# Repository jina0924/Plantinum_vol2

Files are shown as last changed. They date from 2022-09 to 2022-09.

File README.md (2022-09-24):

# 🍀PLANTINUM

<div align="center">
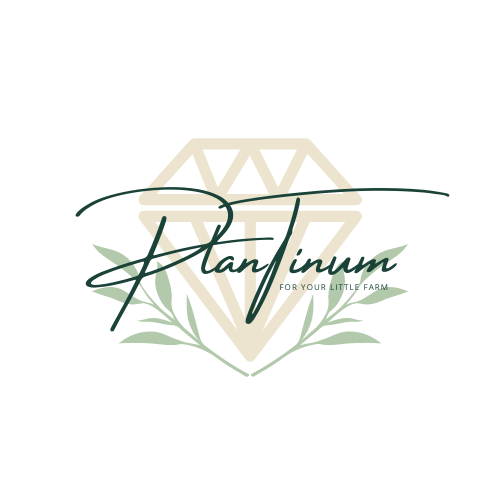
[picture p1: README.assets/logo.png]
  
</div>

**PLANTinum** 이란 **Plant**와 **Platinum**의 합성어입니다. 또한, **Plan**이라는 단어를 담고 계획적으로 식물을 관리하고 보살핀다는 의미를 나타냅니다. 본 프로젝트는 반려식물을 자동으로 케어해주고 나아가 웹을 통하여 반려식물을 거래할 수 있는  **IoT-플랫폼 서비스**를 제공합니다.
Plantinum은 크게 두 가지 서비스로 이루어져 있습니다.

## 1. IoT
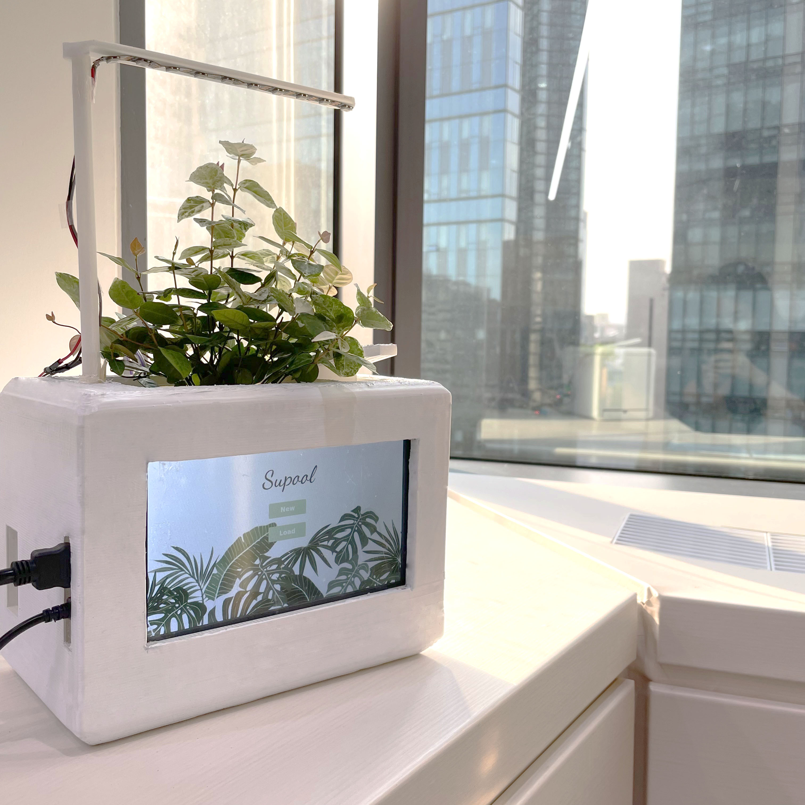
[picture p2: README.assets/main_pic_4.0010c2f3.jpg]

플랜티넘의 IoT 기기 Supool수풀입니다.
Supool의 이름은 **나무와 식물이 우거진 곳**이라는 뜻의 수풀에서 유래했습니다.

### 기능

> 실시간으로 흙의 습도를 측정
> 
> 자동 급수를 진행
>
> LED 식물등
> 
> LCD 터치스크린을 통한 모니터링
> 
> Plantinum, mySQL 웹과 연동

### IoT 기기 구성

<details>
<summary > <b>기능 자세히 보기</b></summary>
<div markdown="1">

[Plantinum 디바이스 시연 영상](https://youtu.be/C1uGjrZCowk)

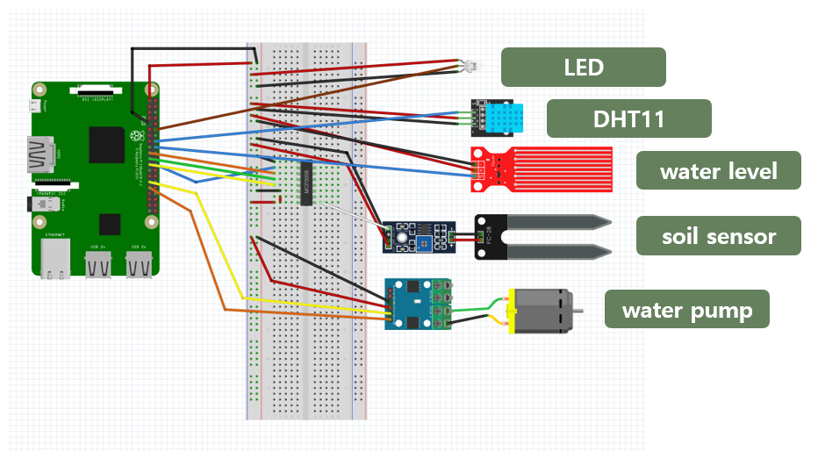
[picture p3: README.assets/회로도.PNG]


> 사용 센서 : LCD, 모터 드라이브(L9110S), 워터펌프, DHT11, 네오픽셀 LED, 수위센서(접촉식), 토양수분센서, mcp3008(컨버터)
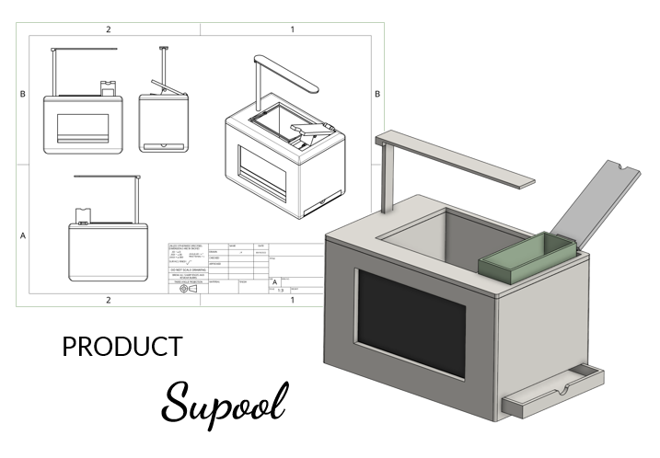
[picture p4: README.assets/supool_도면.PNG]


> supool 3D 도면

</div>
</details>

### LCD 화면 구성

<details>
<summary > <b>기능 자세히 보기</b></summary>
<div markdown="1">

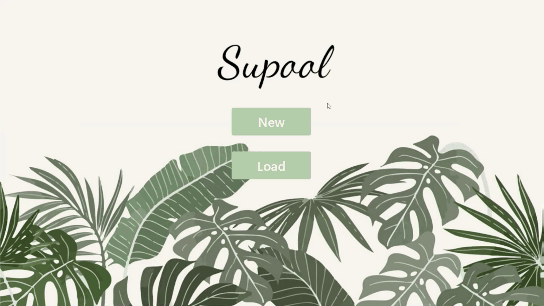
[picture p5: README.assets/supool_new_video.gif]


> new 버튼 클릭 시 OTP 입력으로 WEB과 연동
> 
> OTP는 웹의 내식물 상세 페이지에서 확인 가능 (Supool 연동)
  
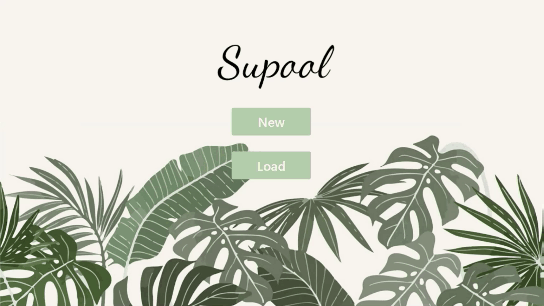
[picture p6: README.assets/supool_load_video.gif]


> load 버튼 클릭 시 supool에 저장되어 있는 정보 불러오기

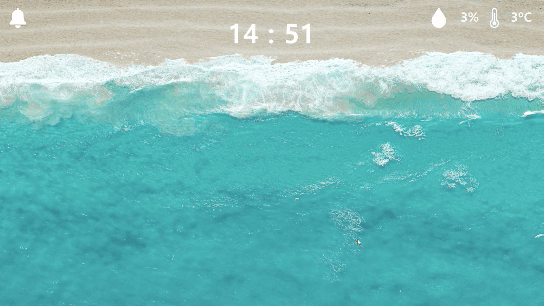
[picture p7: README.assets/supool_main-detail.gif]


> 메인 페이지에서 파도의 높이로 토양 습도 확인
> 
> 디테일 페이지에서 주변환경의 온습도, 토양 수분, 최근 관수 시간, 물통 잔여량 확인

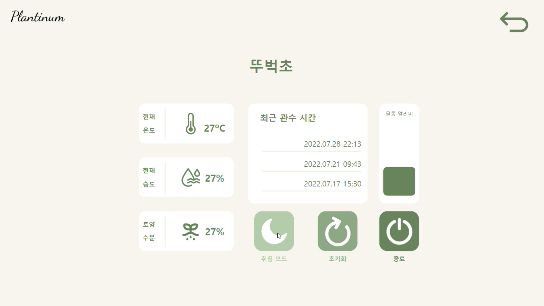
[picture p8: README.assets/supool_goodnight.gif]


> 절전모드 버튼 클릭 후 5초 뒤 절전모드
> 
> 화면 터치 시 메인페이지로 이동

</div>
</details>

<br>

[상세 코드](https://github.com/jina0924/Plantinum_vol2/tree/master/HW/Supool) /
[실행법](https://github.com/jina0924/Plantinum_vol2/blob/master/exec/%EA%B3%B5%ED%86%B5PJT_%EC%84%9C%EC%9A%B81%EB%B0%98_A109_%ED%8F%AC%ED%8C%85%EB%A7%A4%EB%89%B4%EC%96%BC.pdf) /
[기술 스택](https://github.com/jina0924/Plantinum_vol2/blob/master/Docs/STACK_EXPLANATION.md)

## 2. WEB

웹은 크게 세 가지 서비스를 제공합니다.

### 회원가입 및 프로필

<details>
<summary > <b>기능 자세히 보기</b></summary>
<div markdown="1">



> 회원 가입
>
> 최초 회원가 입시 닉네임 자동 생성



> 닉네임, 이메일, 연락처, 주소, 프로필 이미지 변경
>
> 회원가입 후 경과일 확인
>
> 작성한 판매, 구매 게시글 확인
>
> 회원 탈퇴



> 비밀번호 변경

</div>
</details>

<br>

### 내 식물

<details>
<summary > <b>기능 자세히 보기</b></summary>
<div markdown="1">

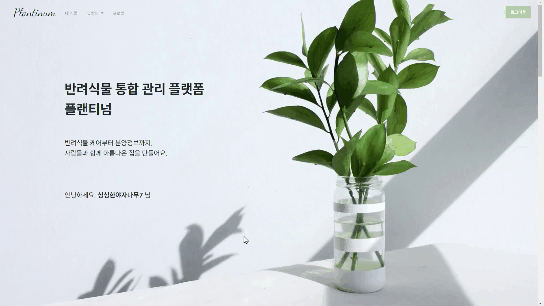
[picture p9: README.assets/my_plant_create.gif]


> 식물 리스트로부터 식물 선택
>
> 존재하지 않는 식물은 사용자가 직접 작성
>
> 반려 식물의 닉네임 지정

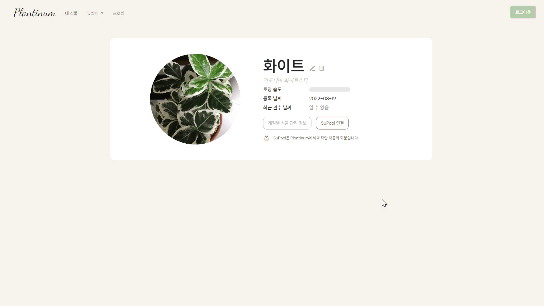
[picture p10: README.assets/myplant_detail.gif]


> 계절별 관리 정보와 특별 관리 정보 제공
>
> SuPool 연결 버튼을 통해 60초 동안 임시 비밀번호 발급, IoT 기기와 웹페이지 연결
>
> 연결 후 웹페이지에서 토양습도와 최근 관수 날짜확인 가능

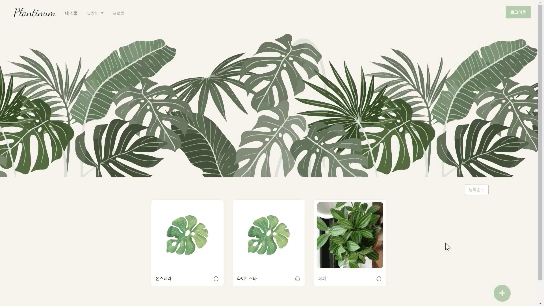
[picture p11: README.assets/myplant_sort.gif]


> 등록순, 이름순 조회
</div>
</details>

<br>

### 잎팔이

<details>
<summary > <b>기능 자세히 보기</b></summary>
<div markdown="1">

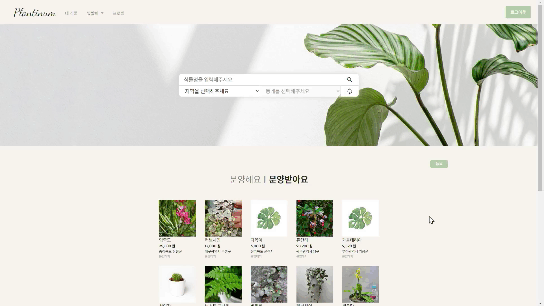
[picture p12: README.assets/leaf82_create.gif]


> 판매, 구매 게시글 등록 및 조회

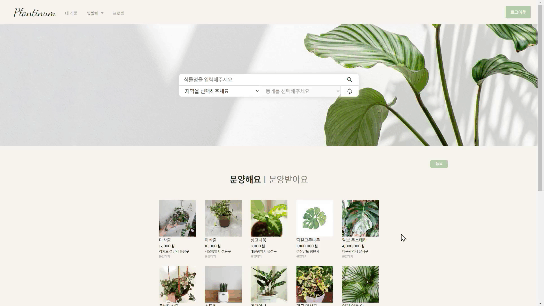
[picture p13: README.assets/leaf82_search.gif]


> 식물명, 지역별 게시글 검색
>
> 게시글은 20개씩 추가 조회

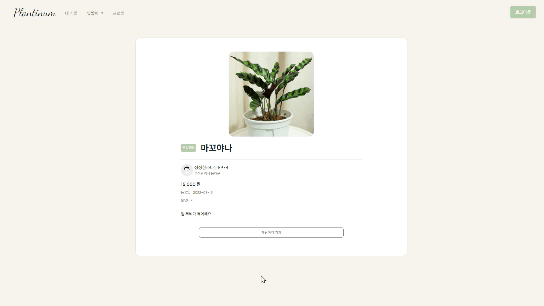
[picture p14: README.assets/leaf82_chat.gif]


> 거래자 간 채팅
</div>
</details>

<br>
<br>
<br>

<details>

<summary > 상세 코드는 여기로 </summary>
<div markdown="1">

### (1) BE

[상세 코드](https://github.com/jina0924/Plantinum_vol2/tree/master/BE) /
[실행법](https://github.com/jina0924/Plantinum_vol2/blob/master/exec/%EA%B3%B5%ED%86%B5PJT_%EC%84%9C%EC%9A%B81%EB%B0%98_A109_%ED%8F%AC%ED%8C%85%EB%A7%A4%EB%89%B4%EC%96%BC.pdf) /
[기술 스택](https://github.com/jina0924/Plantinum_vol2/blob/master/Docs/STACK_EXPLANATION.md)

### (2) FE
[상세 코드](https://github.com/jina0924/Plantinum_vol2/tree/master/FE/plantinum) /
[실행법](https://github.com/jina0924/Plantinum_vol2/blob/master/exec/%EA%B3%B5%ED%86%B5PJT_%EC%84%9C%EC%9A%B81%EB%B0%98_A109_%ED%8F%AC%ED%8C%85%EB%A7%A4%EB%89%B4%EC%96%BC.pdf) /
[기술 스택](https://github.com/jina0924/Plantinum_vol2/blob/master/Docs/STACK_EXPLANATION.md)

</div>
</details>

---

## 💾설치

사이트 주소 : [Plantinum](http://plantinum.co.kr)

> 자세한 내용은 [포팅 매뉴얼](./exec) 참고

- FE
> 파일 위치 : ./FE/plantinum
```shell
// 배포용 설치
$ npm run build

// 로컬에서 이용시 설치
$ npm i
$ npm run serve
```

- BE
> 파일 위치 : ./BE/back

```shell
$ python manage.py runserver
```

- CHAT

> 파일 위치 : ./BE/chat
```shell
$ nohup node app.js &
```

## 🌸 IoT

[코드정보](./HW/Supool)

### [Supool](./HW/Supool)
> 라즈베리파이에 다운로드 후 폴더 내에서 다음 명령어 실행
```shell
$ python main.py
```

### [외관](./HW/stl_files)
> SuPool의 외관 3D 디자인

## 🌸WEB 
### 🌻FE
[코드정보](./FE/) 참고

>  [플랜티넘 폴더](./FE/plantinum/)에서 vscode 실행 후 api 연결 포트 선택

```js
// /FE/plantinum/src/api/drf.js

// 로컬에서 실행할 경우
const HOST = 'http://127.0.0.1:8000/api/v1/'

// 배포용 api 주소
// const HOST = 'http://plantinum.co.kr/api/v1/'
```

### 🌻BE
[api 가이드 문서.md](./BE/api%20%EA%B0%80%EC%9D%B4%EB%93%9C%20%EB%AC%B8%EC%84%9C.md) 참고

[채팅 서버 구축 문서.md](./BE/uwsgi%EB%A5%BC%20%EC%9D%B4%EC%9A%A9%ED%95%B4%EC%84%9C%20django%EC%99%80%20nginx%EC%97%B0%EA%B2%B0%ED%95%98%EA%B8%B0.md) 참고

## 🎮기술스택
[기술스택정리문서](./Docs/STACK_EXPLANATION.md)

## 📃Docs
[문서 모음](./Docs/)
> [프로젝트_명세서](./Docs/%5B%ED%94%84%EB%A1%9C%EC%A0%9D%ED%8A%B8_%EB%AA%85%EC%84%B8%EC%84%9C%5DPlantinum.docx) : 프로젝트가 수행해야 할 모든 기능과 제약 사항, 서비스적인 요구사항을 분석해서 기록해둔 문서

> [HW 흐름 구상 및 유즈케이스.docx](./Docs/HW%20%ED%9D%90%EB%A6%84%20%EA%B5%AC%EC%83%81%20%EB%B0%8F%20%EC%9C%A0%EC%A6%88%EC%BC%80%EC%9D%B4%EC%8A%A4.docx) : 하드웨어 흐름 구상도

> [Jira_guide.pdf](./Docs/Jira_guide.pdf) : Jira 사용법 정리

> [STACK_EXPLANATION](./Docs/STACK_EXPLANATION.md) : 기술 스택 정리

## 💿ERD
 [ERD](https://www.erdcloud.com/d/BqMQqe8yrRaQ5PXyd)

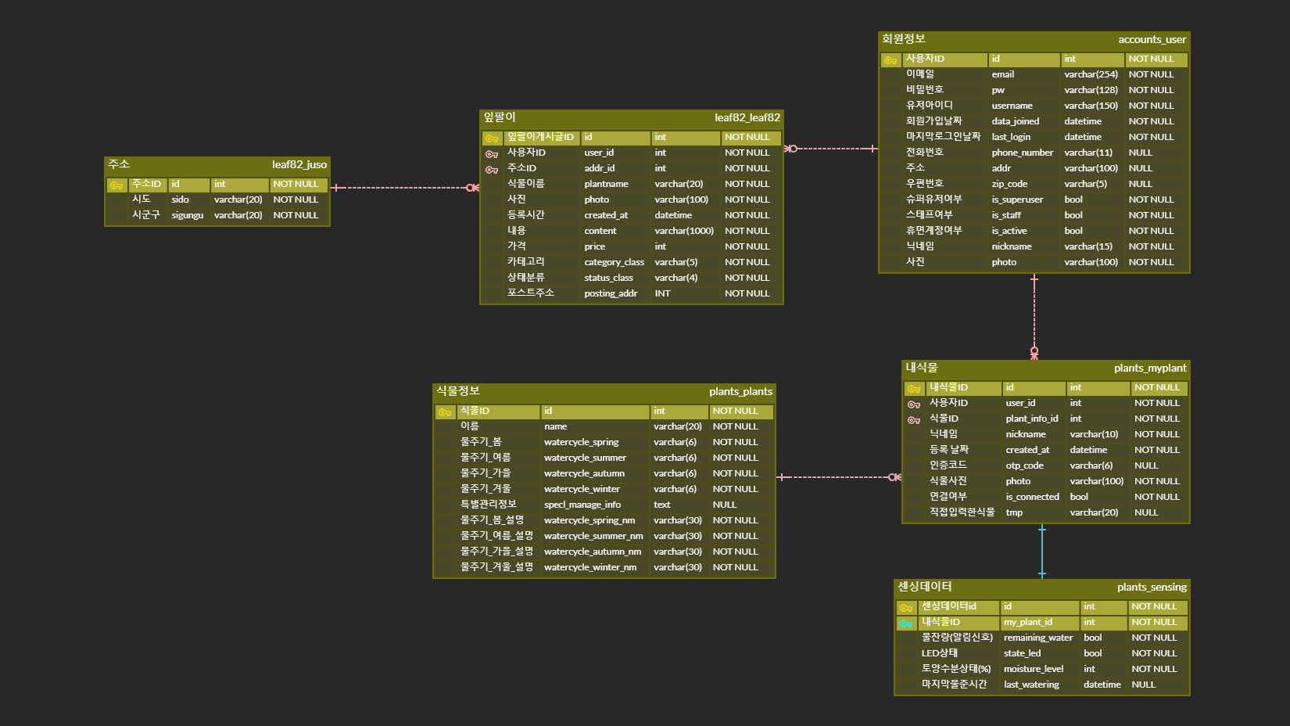
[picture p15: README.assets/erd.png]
erd


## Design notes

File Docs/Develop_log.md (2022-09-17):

# 개발일지

Plantinum 개발 로그입니다.

하루동안 각자 개발한 내용 추가로 적으시면 됩니다.

---

### 2022-07-15

##### [HW] 이용 센서 구매 진행

- 구매완
  - 라즈베리파이 카메라 전용 리본 케이블 (7700원)
  - 아두이노 L9110 듀얼 모터 드라이버 모듈 (990원)
  - MCP3008 ADC칩 아날로그 디지털 컨버터 (3300원)
  - 아두이노 브레드보드 400홀(불투명) (2200원)
  - 아두이노 빗물감지 수위 측정 센서 모듈 (1900원)
  - 아두이노 워터펌프용 실리콘튜브 (3000원)
  - 아두이노 워터펌프 모터3~5V (5500원)
  - 아두이노 토양 수분감지 센서 모듈 (2200원)

### 2022-07-20

##### [HW] 센서 제어 코드 작성 in ./RP2/sensor_test/sensor_main.py

- 구현 함수
  - init() : GPIO 초기 세팅
  - read_spi_adc(adcChannel) : 토양 습도 센서 값 측정 함수
  - map(value, min_adc, max_adc, min_hum, max_hum) : 토양 습도 센서 값이 0~1023이라 0~100사이 값으로 변환해주는 함수
  - humidTemp() : 온습도 센서 측정 / time 라이브러리로 현재시간 출력
    **아직 구현중
  - waterlevel(pin) : 수위 센서 -> 0 or 1 디지털값 1이면 물있음
  - main코드 : 토양 수분이 임계점 이하면 워터펌프 작동 / 10초마다 온습도 센서값 및 현재 시간 출력 / 수위측정값이 0이면 빨간 LED 점등 or 1이면 초록 LED점등

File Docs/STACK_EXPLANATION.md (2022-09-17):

# STACK_EXPLANATION

### Configuration Management

- GITLAB
  > https://lab.ssafy.com/s07-webmobile3-sub1/S07P11A109.git

### Issue Management

- JIRA
  > S07P11A109
  > S07P12A109

### Communication

- Mattermost
- Webex

### Design

- Mockup
  - Web
    - Figma
    - PhotoShop
    - Illustraor
  - HW
    - onshape / 3DWOX Desktop x64
- PPT
  - Figma
  - Google slides

### OS

- Window OS
  > Windows 10 Exterprise
- Linux

### DB

- MySQL

  >MySQL 8.0.20

- Redis

  > Redis 3.0.504

### Server

- AWS EC2 ubuntu
- Nginx
- S3

### Front-end

- Vue.js

  > 3.2.13

- HTML5

- CSS3

- JavaScript

- Node.js

- Vuex

  > 4.0.0

### Back-end

- Django

  > Django 3.2.14
  >
  > djangorestframework 3.13.1

- Python

  > Python 3.9.9

- node.js

  > node.js 16.15.0

- express

  > express  ^4.17.2

- socket.io

  > socket.io  ^4.4.0

- mysql2

  > mysql2  ^2.3.3

### HW

- Raspberry Pi
  - Raspberry Pi 4 model B

- DHT11
  > DHT11 (온습도 센서)
- FC-28
  > FC-28 (토양 수분 감지 센서)
- Water Level Sensor
  > Water Level Sensor (수위 측정 센서 <접촉식>)
- Water Pump
  > Water Pump(워터 펌프)
- mcp3008
  > mcp3008(디지털 컨버터)
- LED
  > 네오 픽셀 LED(보라색)
- LCD
  > LCD 7인치 module
- BreadBoard (아래 2개 중 선택)
  > 400holes BreadBoard
- Pyside6
- C
- Python
- 3D Print
  > 2X DP 303 (Sindoh)
  > 3DWOX Desktop x64

### IDE

- Visual Studio Code
  > Visual Studio Code 1.68.1
  
- Pycharm

### TOOL

- Vim

- MobaXterm

  > MobaXterm Home Edition v22.1 installer edition

- Postman

- Movavi

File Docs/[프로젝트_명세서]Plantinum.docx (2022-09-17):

# 프로젝트 명세서

웹 IoT 프로젝트

“ PLANTinum, IoT 플랫폼 ”

A109팀

팀장 임진경

팀원 김유민

팀원 문요성

팀원 이지수

팀원 정진아

# 목차

1. 프로젝트 개요 ………………………………………………………………………… 3
1) 소개 …………………………………………………………………………… 3
2) Sub PJT 1. Back-End ……………………………………………………… 3
3) Sub PJT 2. Front-End ……………………………………………………… 3
4) Sub PJT 3. Hardware…………………………………………………………4
2. 프로젝트 목표 ………………………………………………………………………… 5
3. 필수 지식 습득 ………………………………………………………………………… 5
4. 과제 명세 ……………………………………………………………………………… 7
1) Back-End ………………………………………………………………………7

Req. 1. 회원관리

Req. 2. 식물등록

Req. 3. 커뮤니티

Req. 4. 프로필

Req. 5. 관리자

2) Front-End ……………………………………………………………………11

Req. 1. 레이아웃

Req. 2. 메인 화면

Req. 3. 커뮤니티 화면

Req. 4. 반응형 웹

Req. 5. 회원관리

Req. 6. 프로필

Req. 7. 당근 페이지

3) Hardware …………………………………………………………………… 14

Req. 1. Raspberry Pi OS 설치

Req. 2. 환경 세팅

Req. 3. 회로도 작성

Req. 4. 서버 연결

Req. 5. GUI 구성

Req. 6. 클래스 및 함수 목록

Req. 7. 자동 실행

5. 프로젝트 실행 및 배포 …………………………………………………………………18
6. 기술 스택 ……………………………………………………………………………… 21
7. 별첨 ………………………………………………………………………………………22

# 1. 프로젝트 개요

## 소개

PLANTinum이란 Plant(식물)와 Platinum(백금)의 합성어를 의미합니다. 또한, 플랫폼을 통해 계획적(Plan)으로 식물을 관리하고 보살핀다는 의미를 담고 있기도 합니다. 본 프로젝트에서는 반려 식물을 케어해주는 자동화된 하드웨어 시스템과 웹 커뮤니티를 통합한 플랫폼 서비스를 제공하는 『IoT 플랫폼』 구현을 목표로 합니다.

“플랫폼 연동 IoT 서비스” PLANTinum은 사용자가 IoT 기기 화면을 통해 화분 내의 토양 상태를 확인하고, 자동화된 케어 서비스를 제공하도록 하는 몇 가지의 선택 항목을 가집니다. 연동된 웹 플랫폼에서는 식물 상태와 서비스 기록을 확인할 수 있으며 비슷한 다수의 사용자가 경험과 소통을 나눌 수 있는 커뮤니티를 제공합니다.

프로젝트의 진행은 3개의 Sub PJT로 진행되며, 각 Sub PJT의 진행은 아래 표와 다음 각 단계를 설명한 내용을 참고하시기 바랍니다.

Sub PJT 1. BE | Sub PJT 2. FE | Sub PJT 3. HW
- Django로 백엔드 구성 - MySQL로 DB 구성 - 게시글 관리 | - Window에 기반한 환경 구성 - Vue로 온라인 웹 플랫폼 제작 - 반응형 웹 | - Raspberry Pi로 하드웨어 구성 - API 제작 - BE 서버 연결

## Sub PJT 1. Back-End

Sub PJT 1에서는 ERD를 그리며 데이터베이스 구조를 설계하고 Django를 사용하여 서비스의 백엔드 영역을 구축합니다. AWS의 S3를 이용해 이미지 업로드 기능을 구현합니다. 마찬가지로 AWS EC2를 통해 서버를 관리하게 됩니다. 주 기능으로는 회원관리, 식물 페이지, 커뮤니티, 프로필 관리, 관리자 페이지 등이 있습니다. 또한 IoT 기기가 받아오는 센서 값들을 DB에 저장하는 역할을 하기도 합니다.

## Sub PJT 2. Front-End

Sub PJT 2에서는 Vue를 사용하여 서비스의 프론트 영역을 구현합니다. 화면은 메인페이지와 내식물 페이지, 커뮤니티, 프로필 페이지로 나뉘며 각 화면은 반응형으로 웹과 모바일에 차이가 둡니다. 관리자용 페이지가 따로 존재합니다. 구현이 완료되었다면 부가 기능으로 식물 거래를 돕는 당근 페이지를 구현합니다.

## Sub PJT 3. Hardware

Sub PJT 3에서는 라즈베리파이와 LCD 모니터를 사용하여 서비스의 하드웨어를 구현합니다. LCD 화면에 식물의 토양 습도와 온도, 기존 기록 등의 정보를 출력하며 웹과 연동하여 식물의 상태를 기록할 수 있습니다. 토양습도 센서, 온도 센서, 워터 필터 등 다양한 센서와 라즈베리파이를 조합하여 뼈대를 제작한 후, 3D 프린터로 프레임을 출력합니다. 각 센서들이 수집한 데이터들은 정해진 시기에 맞춰 서버로 전송됩니다.

# 2. 프로젝트 목표

1) Django와 Vue를 활용한 IoT 플랫폼 구축
2) 임베디드 KIT를 이용한 IoT 서비스 구현
3) AWS 서버를 통해 배포

# 3. 필수 지식 학습

프로젝트 진행을 위한 자기주도 학습에 실마리가 될 수 있는 필수 학습 대상 키워드와 유용한 참고 자료 링크 목록이 아래 표에 제시되어 있습니다. 아래 목록에 제시된 내용은 기초적인 내용에 해당하는 예이며, 이외 추가로 필요한 항목들을 직접 찾아 학습해 나가시기 바랍니다.

주제 | | 참고 링크
반응형 SPA | ES6 | JavaScript의 Array 객체에 대한 소개 https://developer.mozilla.org/ko/docs/Web/JavaScript/Reference/Global_Objects/Array
| React | React 공식 문서(React 기본 예시, CRA, JSX, Hook, Context 등) https://ko.reactjs.org/docs/hello-world.html
| SPA | SPA 개념 설명 https://linked2ev.github.io/devlog/2018/08/01/WEB-What-is-SPA/
| 반응형 웹 | 반응형 웹 디자인 패턴 https://developers.google.com/web/fundamentals/design-and-ux/responsive/patterns?hl=ko
| MariaDB | Maria DB 공식 문서 https://mariadb.org/documentation/
임베디드 키오스크 제작 | Raspbian | Raspbian OS 설치 가이드 https://geeksvoyage.com/raspberry%20pi4/installing-os-for-pi4/
| Arduino | 아두이노 기초 http://blog.naver.com/PostView.nhn?blogId=jamduino&logNo=220812436210
| Arduino 연결 | Node.js에서 시리얼 포트를 활용한 아두이노 연결 https://linked2ev.github.io/devlog/2018/08/01/WEB-What-is-SPA/
| Express.js | Express.js의 이해 및 설치 http://webframeworks.kr/getstarted/express.js
| Material-UI | Material UI Theme 사용법 https://bitly.kr/1LmbXZH
| pm2 | 프로세스 관리툴 중 하나인 pm2의 사용법 소개 https://blog.outsider.ne.kr/1197
| crypto | 암호화 모듈 crypto 사용 https://nodejs.org/api/crypto.html
임베디드 키오스크 완성 | 인증 | 인증과 권한의 개념 https://hanee24.github.io/2018/04/21/authentication-authorization/
| JWT | JWT 장단점 및 토큰 구성 개념 http://www.opennaru.com/opennaru-blog/jwt-json-web-token/
| Socket | Socket의 정의 및 사용법 이해 https://en.wikipedia.org/wiki/Network_socket
| SSR | SPA에서의 SSR과 CSR https://bit.ly/2NK7bfp
| Next.js | Next.js 소개 https://nextjs.org/docs/getting-started
| CSS Animation | CSS Animation 소개 https://developer.mozilla.org/ko/docs/Web/CSS/CSS_Animations
| Infinite Scroll | React에서의 Infinite Scroll 구현 https://reactgo.com/react-infinite-scroll/

# 4. 과제 명세

## Sub PJT 1. Back-End

### Req. 1. 회원관리

회원가입 및 로그인 페이지 관리

제목 | 웹 - 로그인 페이지

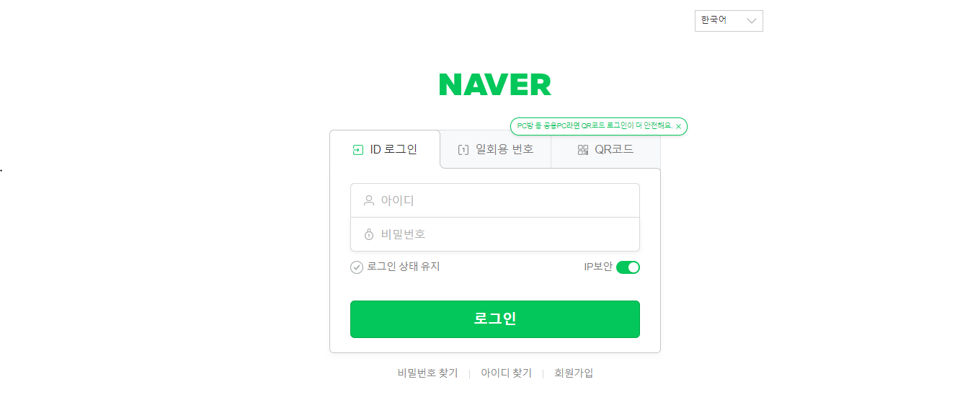
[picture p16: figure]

구성도
설명 | - 로그인 - 회원가입 - 아이디/패스워드 찾기

Req. 1-1. 회원 가입 기능 구현

기능 상세 | - 회원가입 API 구현 - ID, e-mail, 패스워드 필수 입력 - 랜덤 닉네임 자동 생성 - DB의 컬럼 조건에 따라 입력 시 형식 체크(정규식) - email 중복 시 가입 불가로 설정 - 패스워드는 암호화하여 통신 및 DB에 저장

Req. 1-2. 회원 로그인, 로그아웃 기능 구현

기능 상세 | - 회원 로그인 API 구현 - ID, e-mail, 패스워드를 필수 입력 항목으로 설정 - 패스워드는 암호화하여 통신

Req. 1-2. 회원 비밀번호 찾기 기능 구현

기능 상세 | - 비밀번호 분실 시 이메일을 통해 찾기 가능

### Req. 2. 식물 등록

기능 상세 | - 나의 식물 등록하기 - 등록 시 랜덤 값 생성-중복없이, 20초 안에 등록, 이후 삭제 - 이름, 심은 날짜 설정 - 토양 수분 체크 - 최근 물주기 날짜

Req. 2-1. 등록한 식물 상세 페이지

기능 상세 | - 이름, 심은 날짜 - 토양 수분 기록

Req. 2-1. 실내 정원용 식물 정보 등록

기능 상세 | - 농촌진흥청 농사로에서 제공하는 공공데이터 사용 - 식물 이름, 물주기 조건(봄, 여름, 가을, 겨울)

### Req. 3. 커뮤니티

기능 상세 | - 게시글 제목, 내용, 작성자, 작성 시간(최신 순으로) - 댓글, 대댓글 - 카테고리 정렬 - 지역에 따른 카테고리 분류 - 게시글 검색 - 디폴트 이미지 설정

### Req. 4. 프로필

기능 상세 | - 유저가 작성한 게시글 목록 조회 기능 - 유저가 등록한 식물 조회 기능 - 개인정보(비밀번호) 수정 기능

### Req. 5. 관리자

기능 상세 | - 회원 관리 - 게시글 관리

### Req. 6. 추가기능

기능 상세 | - 즐겨찾기 및 좋아요 - 즐겨찾기 등록한 게시글 조회

## Sub PJT 2. Front-End

### Req. 1. 레이아웃

Req. 1-1 | 레이아웃 내용 구성
기능 명세 | - Header에 로고, 메뉴, 회원관리, 검색 버튼 배치 - Footer에 팀 정보 추가 - 메인 화면의 구성요소 가운데 정렬

### Req. 2. 메인 화면- 식물 등록

Req. 2 | 메인화면

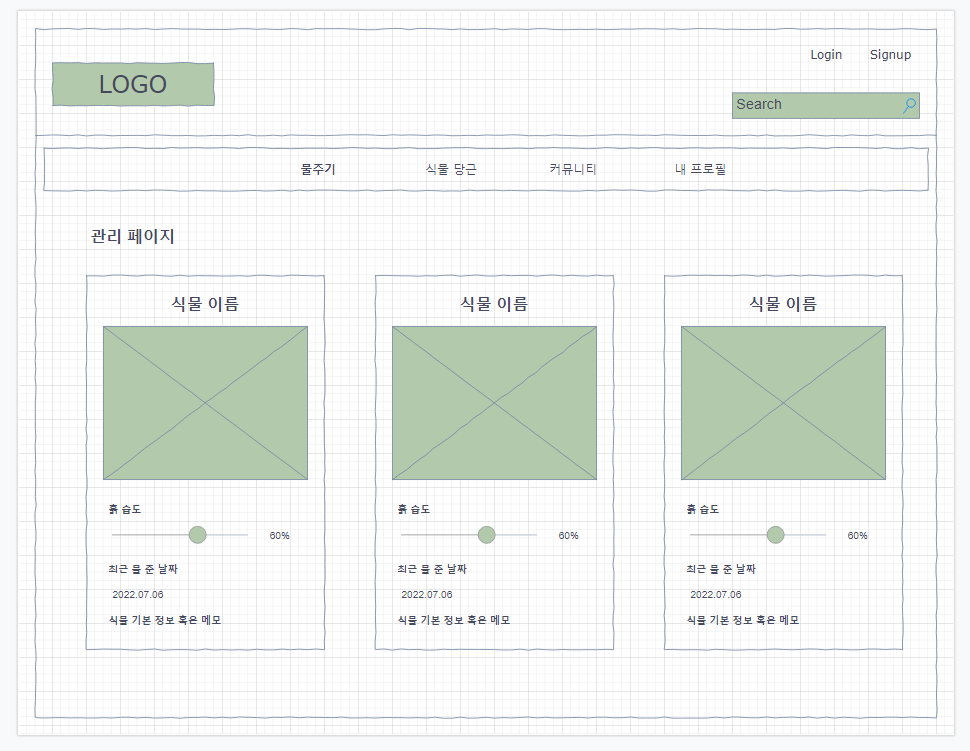
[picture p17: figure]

Req. 2-1 | 버튼 및 메뉴에 주요 이벤트 기능 구현
기능명세 | - 로고 클릭 시 홈화면으로 이동 - login / signup 버튼 클릭 시 해당 페이지로 이동 - search 바를 통해 유저가 등록한 식물 목록 조회 가능 - 물주기, 식물당근, 커뮤니티, 내프로필 등 다른 유저와의 interaction 페이지로 이동 - 등록된 식물을 관리페이지에 보여주며, 등록된 식물이 없을 경우에는 동그라미 안에 + 버튼으로 식물 추가할 수 있도록 구현 - 등록된 식물의 그리드를 클릭함으로써 상세 페이지 접근

### Req. 3. 커뮤니티 화면

Req. 3 | 커뮤니티 화면

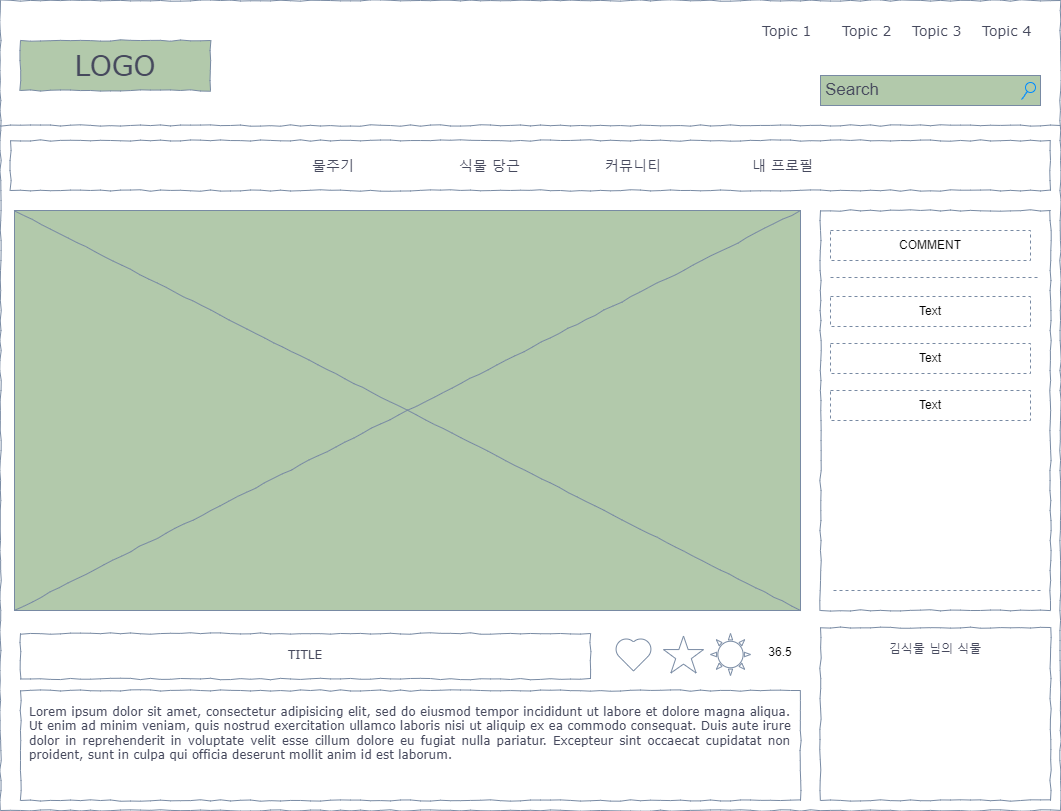
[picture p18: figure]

Req. 3-1 | 커뮤니티 UI 구현
기능 명세 | - 모든 유저가 게시글 열람 가능하도록 구현 - 사진 클릭 시 게시글 상세 페이지로 이동 - 인증된 유저에게만 게시글 작성 루트 노출 - 앨범형으로 구성 (default image) - 인증된 유저는 게시글에 댓글 작성 및 수정, 삭제 가능

Req. 3-2 | 커뮤니티 추가
기능 명세 | - 거래를 위한 채팅 서비스 지원

### Req. 4. 반응형 웹

Req. 4-1 | 모바일 사이즈일 때 메뉴 사이드 바 노출
설명 | - PC화면에서 메뉴 아이콘 비활성 기능 추가 - 화면 사이즈를 변경해 기능 동작 확인

### Req. 5. 회원관리

Req. 5-1 | 회원 가입 UI 구현
설명 | - 회원 관리 모달 구현 - 모달 안에 회원 관리 UI 구현

Req. 5-2 | 회원 로그인 UI 구현
설명 | - 회원 관리 모달 안에 회원 로그인 UI 구현

### Req. 6. 프로필

Req. 6-1 | 유저 정보 변경 UI 구현
설명 | - 프로필 모달 구현 - 유저 정보 변경 UI 구현

Req. 6-2 | 비밀번호 변경 UI 구현
설명 | - 비밀번호 변경 UI 구현

### Req. 7. 일지 페이지

Req. 7-1 | 다이어리 형식의 일지 페이지 구현
설명 | - 각 게시글에 반응 표시 기능 구현 (ex. 좋아요)

## Sub PJT 3. Hardware

### Req. 1. 라즈베리파이 OS 설치 및 초기 환경설정

Req. 1-1 | sd카드에 라즈베리파이 os설치
설명 | - raspberry pi imager 설치 - sd 카드 포맷 후 os설치

Req. 1-2 | 모니터를 이용한 초기 설정
설명 | - 국가, 언어 설정 - 계정 해상도 설정 - WIFI 연결 후 IP확인 - SSH, VNC, SPI, I2C, Serial Port 등 Enable설정

Req. 1-3 | 원격제어 연결
설명 | - VNC Viewer 설치 - IP확인 후 연결

### Req. 2. 환경 세팅(라즈베리파이 쉘)

Req. 2-1 | 설치 라이브러리 목록
설명 | - 라이브러리 설치 전 sudo apt-get update && sudo apt-get upgrade - sudo apt-get install python3.7 - sudo apt-get install vim - vim 설치 후 .vimrc 파일 작성 필요 개인 취향에 맞춰서 작성 - git 설치 (최신 버전으로 받으려면 의존성 패키지 먼저 설치 )

### Req. 3. 회로도 작성

Req. 3-1 | 필요 HW 목록
설명 | - raspberry pi 4 model B - 토양감지센서 - mcp 3008 (디지털 컨버터) x 2 (토양감지센서 1, 수위센서 1) - DHT11(온습도센서) - 네오픽셀 LED, 저항 - lcd monitor 7인치 - 수위센서 - 워터펌프, 모터드라이브 - 브레드보드

Req. 3-2 | 회로구성
설명 | - HW 회로 구성 - 간단한 동작 코드로 각 회로 연결 테스트

Req. 3-3 | 기능 관련
설명 | - date time으로 급수 시기 조절 - 데이터 측정 시간 주기 조절(하루에 두 번?) - DB에는 물 주는 시간만 넘기기 - LCD monitor를 통해서 터치로 조작 가능

### Req. 4. 서버 연결

Req. 4-1 | DB 연결
설명 | - mysql-server && mysql -client 설치 - mysql connector 라이브러리를 이용해서 DB 연결 예정 - db, cur 변수 활용해 db접근 및 쿼리문 전송

Req. 4-2 | 데이터 송수신
설명 | - AWS ubuntu server를 기반하여 MySQL Server 와 통신 - 식물 정보 및 물주기 정보를 받아와 하드웨어에 등록

### Req. 5. GUI 구성

Req. 5-1 | 터치 스크린 GUI 연결
설명 | - 라즈베리파이에 Qtside2 설치 - windows 에서 작성한 python코드 옮겨오기

### Req. 6. 클래스 및 함수 목록 및 기능

1. 식물 정보 등록 시 랜덤 코드(unique)를 DB attribute 하나 추가
2. 해당 primary key를 웹페이지에서 확인이 가능해야됨
3. 해당 코드를 화분에 입력 시 식물정보 가져옴

함수 | 기능
init() | - 각종 센서 및 사용할 DB init - GPIO Pin Number setting
plant_registration() | - 식물 정보 등록(OTP 코드 이용예정)
get_info() | - 파일을 읽어 처음 실행하는 것인지 확인 - 처음 실행시 code로 정보 받기 - 처음 실행이 아닐 시 파일에 등록되어있는 정보 가져오기
Check_Time() | - 해당 식물의 물 주기에 맞는 시간 측정
control_watering() | - 서보모터 작동해서 물주기 - 물 주는 작업 끝날때 check_remaining() 실행 - if( check_remaining() < 100ml ) watchOut() 실행
control_nutrition() | - 서보모터 작동해서 영양제 주기 - 물 주는 작업 끝날때 check_remaining() 실행 - if( check_remaining() < 100ml ) watchOut() 실행
check_remaining() | - 수위센서 활용해서 잔량 확인
watchOut() | - lcd화면에 물 충전 알림 or 웹페이지에 알림
control_light() | - 파라미터로 led 제어 - light(0) => led off - light(1) => led on
get_wheater() | - 실시간 날씨정보 받아오기(보류)
get_sensingData() | - 조도센서, dht11로 온습도,조도 정보 받아오기
send_sensingData() | - DB에 정보 업데이트

### Req. 7. 자동실행

Req. 7 | 전원 공급 시 프로그램 자동 실행
설명 | - crontab, rc.local 등 맞는 방법 선택

### Req. 8. 센서 Pin

이름 | 필요 Pin
LCD monitor | - GND - VCC
모터드라이브 (L9110S) | - GND - VCC - Pin 2개
워터펌프 | - 모터드라이브에 +, - 핀 연결
DHT11 | - GND - VCC - Data Pin 1
네오픽셀 LED | - GND - VCC - IN
수위센서(접촉) | - GND - VCC - mcp3008에 Data Pin 1 연결
토양수분센서 | - GND - VCC - mcp3008에 Data Pin 1 연결
mcp3008(디지털 컨버터) | - GND 2 - VCC 2 - Data Pin 4

# 5. 프로젝트 실행 및 배포

## EC2 인스턴스

Amazon Elastic Compute Cloud(Amazon EC2)는 500개가 넘는 인스턴스, 그리고 최신 프로세서, 스토리지, 네트워킹, 운영 체제 및 구매 모델의 옵션과 함께 워크로드의 요구 사항에 가장 잘 부합할 수 있도록 가장 포괄적이고 심층적인 컴퓨팅 플랫폼을 제공합니다.[^1] AWS EC2 인스턴스를 통해 리눅스 기반 Ubuntu20.04LTS 서버를 구축하고 MobaXterm의 SSH 통신을 통해 인스턴스에 접속합니다.

## Nginx&uWSGI를 이용한 프로세스 관리

Nginx는 동시접속 처리에 특화된 웹서버 프로그램으로 다수의 사용자가 웹에 접속할 경우에 권장되는 사양입니다. 비동기 처리 방식을 채택하여 사용자들의 요청 간의 버퍼링과 대기 시간을 줄일 수 있다는 장점이 존재합니다. AWS 인스턴스 상에 Nginx를 설치하여 다수의 프로그램을 중계합니다. $ sudo apt-get install nginx 명령어를 통해 Nginx 설치 후 환경설정을 세팅할 수 있습니다.

Nginx는 Node.js 환경에서 Proxy 서버로 활용될 수 있으나 Python을 사용하는 Django는 Nginx를 proxy 서버로 이용할 수 없습니다. 따라서 본 프로젝트에서는 Nginx와 Django를 이어주는 중간 다리 역할로서 uWSGI를 채용합니다.

uWSGI는 python 패키지를 사용할 수 있는 애플리케이션 컨테이너 서버로 애플리케이션 호출을 통해 애플리케이션 서버가 코드와 통신할 수 있도록 합니다. 일반적으로 서버가 접근할 수 있는 python 모듈에서 ‘애플리케이션’이라는 이름의 객체로 제공되곤 합니다. 본 프로젝트의 uWSGI는 실제 물리 서버가 아닌 가상 인스턴스(venv)에서 작동합니다.

$ cd /etc/nginx/sites-available

$ vi default

#default

…

server {

listen 80 default_server;

}

위와 같이 Nginx의 default 파일을 수정하면 localhost의 8000번 포트 대신 Nginx에서 입력한 80번의 포트 번호로도 페이지에 접속할 수 있습니다.

## S3 이미지 등록

Amazon Simple Storage Service(Amazon S3)는 AWS에서 제공하는 객체 스토리지 서비스입니다. 스토리지 내에서 이미지를 포함한 데이터를 저장하고 보호할 수 있습니다. 본 프로젝트에서는 웹서비스와 커뮤니티 내에서 사용되는 다양한 이미지 파일들을 S3에 올림으로써 DB가 무거워지는 것을 방지하여 서비스 성능을 향상시키고자 합니다. 대표적으로 본 프로젝트의 S3 스토리지 내에는 plantinum 웹 서비스에서 기본적으로 제공하는 이미지가 포함되어 있습니다.

## 프로그램 배포

예전으로 거슬러 올라가면 서버를 점검하고 수정할 때마다 서버를 정지시키고 재실행해서 변경사항을 적용하곤 했습니다. 이건 당연히 거대한 서비스상의 결함입니다. 서버가 재실행되는 동안은 사용자들이 접속을 할 수 없고, 처리 중에 있던 서비스가 중간에 중단될 수 있기 때문입니다.

따라서 웹의 배포는 백그라운드 작업으로 진행되며, 지속적인 서비스를 고려한 ‘무중단 배포’를 목표로 합니다. 이를 위해서 우선 SSH 터미널 상에서 소스를 수정해서 저장하고, runserver를 통해 서버를 실행합니다. Ctrl+Z를 눌러 실행되던 프로그램을 일시 정지 시킨 후 shell로 돌아와 $ bg명령어를 작성하면 해당 프로그램이 백그라운드에서 작동하게 됩니다. 추가적으로 $ disown -h 명령어를 작성하면 ssh 연결이 끊어져도 프로세스가 종료되지 않습니다. restart는 프로세스를 무조건 kill한 후에 시작하기 때문에 사용해서는 안 됩니다.

단순한 상황에서는 이것만으로 중단이 사라지지만 이때 몇 가지 구멍에서 끊김 현상이 발생할 수 있습니다.

1. new_app이 완전히 동작하기 전에 요청을 받을 경우
2. old_app이 요청 처리 도중에 SIGKILL로 죽을 경우
3. HTTP Keep-Alive 가 사용될 경우

이러한 경우 발생할 수 있는 일부 사태를 방지하기 위해 Redis를 사용합니다.

## Redis 저장소

Redis는 지속성을 보장하는 In-메모리 데이터베이스입니다. 짧은 대기 시간 대비 높은 데이터 처리율을 보이며 멀티 스레드를 사용하여 메모리 관리에 용이합니다. 관계형 데이터베이스인 mySQL과 달리 Redis는 비관계형 데이터베이스이며 데이터에 유효 기간을 두고 있습니다. 일정 기간이 지나면 오래된 데이터를 자동으로 삭제하여 데이터 용량 관리에도 용이합니다. 또한, 데이터가 key-value의 dictionary 형식으로 이루어졌기에 mySQL보다 빠른 속도를 자랑합니다. 이러한 특징들로 인해 채팅 주로 시스템 구현에 이용됩니다.

그 중에서도 Redis의 데이터 유효 기간은 데이터베이스 관리자에 의해 조절 가능합니다. 이를 TTL(Time To Live)라고 부르며 본 프로젝트에서는 OTP 데이터의 관리를 위해 mySQL과 함께 Redis 데이터 베이스를 일부 채용합니다.

OTP 코드가 발급된 채로 서버가 다운될 시, 생성된 OTP는 서버가 복구된 후 IoT 기기가 연결되지 않은 상황에서도 삭제되지 않고 mySQL의 스키마에 남아 새로운 OTP 발급을 저해합니다. 이러한 사태를 해결하기 위해 Redis의 TTL을 사용합니다. Redis는 서버가 다운되어도 TTL에 지정된 시간이 지나면 자동적으로 데이터가 삭제되며 새로운 OTP 발급을 가능케 합니다. 이를 통해 서버가 다운됐을 때, OTP의 재발급이 불가능한 문제를 해결할 수 있습니다.

# 6. 기술 스택

PART | 기술 스택 / HW | 상세 내용
형상관리 | GITLAB | - https://lab.ssafy.com/s07-webmobile3-sub1/S07P12A109.git
이슈관리 | JIRA | - S07P11A109 - S07P12A109
커뮤니케이션 | Mattermost
디자인 | 포토샵/일러스트
| Figma
OS | Window | - Windows 10 Enterprise
| Linux
DB | MySQL | - MySQL 8.0.29 (64bits)
| S3
| Redis
Server | AWS EC2 ubuntu
| Ngnix
FE | Vue
BE | Django
HW | Raspberry Pi | - Raspberry Pi 4 model B
| PySide6
IDE | Visual Studio Code | - Visual Studio Code 1.68.1
| MobaXterm

# * 별첨

각 명세서에 첨부된 별첨 목록을 첨부합니다.

## 웹 IoT 명세서 1. 반응형 SPA 제작

- Chocolatey 설치
- Node.js 설치
- VS Code 설치
- 프록시 서버 NginX 설치

## 웹 IoT 명세서 2. 웹 서버 및 임베디드 기반 키오스크 제작

- Raspbian OS 설치
- Raspbian OS 환경설정
- Maria DB 설치
- 미들웨어 활용

[^1] AWS EC2, https://aws.amazon.com/ko/ec2/features/?trk=ec2_landing, 2022.08.15

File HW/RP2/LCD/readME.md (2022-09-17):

따로 컨벤션이 없어서 편하게 작성합니다.

수정사항!
1. mainUI.py를 수정했습니다. 해당 화면을 확인해 주세요.
2. 토양 수분 센서 값에 따라 이미지 파일(wave)을 움직이는 작업이 필요합니다.
3. 온습도 센서 값에 따라 아이콘 옆에 값을 넣어주는 작업이 필요합니다.
4. 알림 버튼을 누르면 다른 화면, 혹은 modal이 떠서 현재 물통 잔여량, 혹은 물통을 충전해야 한다는 알림을 제공해야 합니다.

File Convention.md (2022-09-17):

# GIT

[toc]

### Message✉

### 개괄
    모든 커밋 메시지는 영어로 작성

### 구조
    기본적으로 커밋 메시지는 아래와 같이 제목/본문/꼬리말로 구성
    - type : subject
        - body
        - footer

### 커밋 타입(Type)
    feat : 새로운 기능 추가
    fix : 버그 수정
    docs: 문서 내용 변경
    style: 포맷,  세미콜론 수정 등 코드가 아닌 스타일에 관련된 수정
    refactor: 리팩토링 코드
    test: 테스트 코드 추가 및 리팩토링 테스트 등
    chore: build task 수정, 프로젝트 매니저 설정 수정 등
    - 타입은 소문자로 시작
        - 타입은 항상 대괄호 안에 파트를 입력하여 시작
        - 예시
            3: "fix" --> ''[HW] fix'

### 제목(Subject)
    제목은 50자 이내로, 대문자로 시작하며 마침표로 끝나지 않도록 함
    - 과거시제를 사용하지 않고 명령어로 작성
        - 예시
        "feat : Logined" --> "feat : Login"
        "feat : Added" --> "feat : Add"

### 본문(Body)
    선택사항

    - 부연 설명 필요 시 작성
        - 100자 미만 작성 권장

### 꼬리말(Footer)
    선택사항

    - issue tracker id를 작성할 때 사용
        - JIRA Code 작성 시 사용
        - 예시
            [FE] feat : Login Design
    
        한글한글한글
        - 영어말고 한글로
        - 선택사항
    
        Issue tracker id : 486
        JIRA Code : #123

## Branch 종류

- main
  - 배포 가능한 상태의 결과물
- develop
  - 구현한 기능을 병합하기 위한 브랜치
  - 통합 폴더의 기능
- feature
  - 개별 기능 구현 브랜치
  - 기능 개발 완료 시 삭제
  - 네이밍 규칙
    - feature/기능
    - 예) feature/login
- ~~hotfix~~

## JIRA
### Epic
    큰 파트 생성
    HW / WEB / 기획 / DB / 배포 / TEST

### Story
    회원에게 제공되는 서비스/기능 목록

    - 네이밍 규칙 - 명사로 마무리
        예) 물주기, 빛조절 / 회원가입, 로그인, 게시물 작성
        - 스토리에는 이모지 추가

### Task
    해당 스토리에 관련한 상세 구현 사항

    - 네이밍 규칙
        파트는 대괄호에 작성
        명사로 마무리
            예) [BE] 유저 모델 작성
        - Task의 Story point는 4 이하로 작성

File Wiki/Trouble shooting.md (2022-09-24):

## Trouble shooting

[TOC]

1. [FE](#1-fe)
2. [BE](#2-be)
3. [HW](#3-hw)
4. [server](#4-server)
5. [기타](#5-기타)

### 1. FE

#### div 태그에 span태그를 수평 중앙정렬🎈

```html
<template>
  <div class="boxes">
    <!-- first box -->
    <div class=first-box>
      <div class="row">
        <div class="col-md-3 home-logo">
          <router-link :to="{ name: 'home' }">
            <span>
              Plantinum
            </span>
          </router-link>
        </div>
      </div>
    </div>
  </div>
  ...
</template>
```

```css
  .home-logo {
    text-align: center;
    padding-top: 1rem;
    padding-bottom: 1rem;
    text-decoration: none;
  }
```

- 포인트
  - 스타일에도 넣을 수 있고,
  - 클래스에 d-flex justify-content-center로도 가능!

---

#### 버튼에 스타일 주기🎆

```html
<template>
  <div class="boxes">
    <div class="first-box">
      ...
      <div class="btnbox row" v-if="!isLoggedIn">
        <!-- <div class="btnbox row"> -->
          <div class="btn-border col-6">
            <div class="login d-flex justify-content-center">
              <router-link :to="{ name: login }">
                <button class="btn">로그인</button>
              </router-link>
            </div>
          </div>
        </div>
      ...
    </div>
  </div>  
</template>
```

```css
  .btn{
    border-radius: 5px;
    height: 44px;
    font-size: 1rem;
    background-color: #b2c9ab;
    color: white;
    width: 100%;
  }

  .btnbox a {
    width: 50%;
  }
```

- 기능

  1. 버튼 클릭하면 해당 링크로 이동

- 포인트

  1. 버튼 생성 후 위치를 정하기 위해 justify-content-center

  2. 높이(height) 조절

  3. border-radius를 통해 버튼 둥글기 조절

  4. 부모  div인 btn-border가 가지고 있는 col-6에서 버튼의 너비(width)를 100%로 꽉 채운 후, 그 속에 있는 a 태그 역할을 하는 router-link의 너비(width)는  50%로 채움

---

#### 배경 이미지 투명도 조절🧨

```css
<style scoped>
.profile {
  background-image: linear-gradient(rgba(255, 255, 255, 0.6), rgba(255, 255, 255, 0.6)), url('@/assets/ProfileView/background_img.jpg');
  background-size: cover;
  height: 1117px;
}
</style>
```

- 기능
  - 배경 `이미지만` 투명으로 설정하고 싶다!
  - **opacity로 조절하면 글자도 투명해짐...ㅠㅠ**

---

#### input[type="file"] 커스터마이징🎉

```vue
<template>
  ...
  <div class="profile-pic d-flex justify-content-center">
    <label for="pic-file">
      <span class="material-symbols-outlined">
        photo_camera
   	  </span>
      <span>
        사진 변경하기
      </span>
    </label>
      <input type="file" id="pic-file">
    </div>
  ...
</template>
```

- 기능
  - 기존 멋없는 input 태그가 없어지고,
  - label로 묶인 항목이 표시됨

---

#### search-bar 검색버튼 input tag 안에 들어간 것 같은 효과 주기🎐

```vue
<template>
...
  <div class="search-box col-sm-8 col-md-4 col-12 d-flex justify-content-center">
    <input class="search-input" type="text" v-model="info.plantname" placeholder="식물명을 입력해주세요" @keyup.enter="beforeSearch()">        
    <button class="search-btn" type="submit" @click="beforeSearch()">
      <span class="material-symbols-outlined d-flex align-items-center justify-content-center">search</span>
    </button>
  </div>
...
</template>

<style>
.search-box {
  position: relative;
  border-radius: 0.5rem;
  box-shadow: 0rem 0rem 1rem #d2d2d2;
}

.search-input {
  width: 90%;
  height: 2.5rem;
  border: 0;
  border-top-left-radius: 0.5rem;
  border-bottom-left-radius: 0.5rem;
  font-size: 1.2rem;
}

.search-btn {
  width: 10%;
  border: 0;
  background-color: white;
  border-top-right-radius: 0.5rem;
  border-bottom-right-radius: 0.5rem;
  color: black;
}
</style>
```

- 효과
  - 서치바에 그림자를 두어 입체감 주기
    - 최상단 div에 주고 싶은 border-radius와 box-shadow  입력
  - 인풋 좌측만 border-radius
  - 버튼 우측만 border-radius
  - 버튼 배경 색 white로 변경

---

#### v-on click을 활용해 렌더링되는 화면 교체하기🎇

```vue
<template>
  ...
  <span @click="changeMyleaf82">
      내 잎팔이 글
  </span>
  ...
</template>
<script>
export default {
  name: 'ProfileDetail',
  data() {
    return {
      myleaf82: false,
    }
  },
  methods: {
    changeMyleaf82() {
      this.myleaf82 = !this.myleaf82
    },
  }
}    
</script>
```

- 기능
  - 버튼 클릭시 관련 정보 보여주기
    - 로그인 및 회원정보 수정 | 내가 등록한 게시글 

- 포인트
  1. 보여줄 화면을 인식하는 값(myleaf82)을 데이터에 저장
  2. methods에 그 값을 변경해주는 changeMyleaf82() 함수 지정
     - ~~method~~ --> methods...
  3. 클릭시 이동시켜줄 span 태그 지정

---

#### vuex 관리하기(로그인 , 로그아웃 사이클)🎃

```js
import router from '@/router'
import axios from 'axios'
import drf from '@/api/drf'

export const Account = {
  // state: {
  // },
  // getters: {
  // },
  // mutations: {
  // },
  // actions: {
  // },
  state: {
    token: localStorage.getItem('token') || '' ,
    currentUser: {},
    authError: null,
    profile: {},
  },

  getters: {
    isLoggedIn: state => !!state.token,
    currentUser: state => state.currentUser,
    authError: state => state.authError,
    authHeader: state => ({ Authorization: `Token ${state.token}`}),
    profile: state => state.profile,
  },

  mutations: {
    SET_TOKEN: (state, token) => state.token = token,
    SET_CURRENT_USER: (state, user) => state.currentUser = user,
    SET_AUTH_ERROR: (state, error) => state.authError = error,
    SET_PROFILE: (state, profile) => state.profile = profile,
  },

  actions: {
      
    // mutations을 호출할 actions
    saveToken({ commit }, token) {
      commit('SET_TOKEN', token)
      localStorage.setItem('token', token)
    },

    removeToken({ commit }) {
      commit('SET_TOKEN', '')
      localStorage.setItem('token', '')
    },

    resetCurrentUser({ commit }) {
      commit('SET_CURRENT_USER', {})
    },

    resetProfile({ commit }) {
      commit('SET_PROFILE', {})
    },

    // 홈페이지에서 로그인이나 로그아웃 버튼이 눌릴 때 시행될  actions
    login({ commit, dispatch }, credentials) {
      axios ({
        url: drf.accounts.login(),
        method: 'post',
        data: credentials
      })
      .then(res => {
        const token = res.data.key
        dispatch('saveToken', token)
        dispatch('fetchCurrentUser')
        dispatch('fetchProfile')
        router.push({ name: 'home' })
      })
      .catch(err => {
        console.error(err.response.data)
        commit('SET_AUTH_ERROR', err.response.data)
      })
    },

    logout({ getters, dispatch }) {
      axios({
        url: drf.accounts.logout(),
        method: 'post',
        headers: getters.authHeader,
      })
      .then(() => {
        dispatch('removeToken')
        dispatch('resetCurrentUser')
        dispatch('resetProfile')
        alert('logout 되었습니다')
        router.push({ name: 'home' })
      })
      // 에러 발생 시 어떻게 할 지 고민해야 함
      .catch(err => {
        alert('잘못된 접근입니다.')
        console.log(err.response)
      })
    },

    // 로그인시 내부적으로 작동할 actions 
    fetchCurrentUser({ commit, getters, dispatch }) {
      if (getters.isLoggedIn) {
        axios({
          url: drf.accounts.currentUserInfo(),
          method: 'get',
          headers: getters.authHeader,
        })
        .then(res => commit('SET_CURRENT_USER', res.data))
        .catch(err => {
          if (err.response.status === 401) {
            dispatch('removeToken')
            router.push({ name: 'login' })
          }
        })
      }
    },

    fetchProfile({ commit, getters },) {
      axios({
        url: drf.accounts.profile(),
        method: 'get',
        headers: getters.authHeader,
      })
      .then(res => {
        commit('SET_PROFILE', res.data)
      })
      .catch(err => {
        if (err.response.status === 404) {
          router.push({ name: 'NotFound404' })
        }
      })
    },
  }
}
```

- 기능
  - 로그인 시 사용자 정보 및 프로필 페이지에 활용될 정보 받아옴
  - 로그아웃 시 토큰, 사용자 정보, 프로필 정보를 지워서 해당 페이지에 접근해도 띄어주는 정보가 없어짐
    - 1차적으로 접근을 못하게 막아야함

- 포인트

  1. 로그인 클릭했을 때, 백엔드로 credentials로 묶어 로그인 정보와 함께 axios 요청을 보냄

  2. 백엔드에서 response를 보내줌
  3. 받아온 토큰 값을 saveToken actions를 호출해 state의 token에저장해주고,
     1. saveToken actions는 SET_TOKEN mutations를 호출해 state의 token 값을 수정
  4.  fetchCurrentUser actions를 실행함
     1. 로그인이 되어있다면 백엔드에 유저 정보를 요청함
     2. 받아온 유저정보를 SET_CURRENT_USER mutations를 호출해 state의 currentUser 값을 수정
  5. fetchProfile actions를 실행함
     1. 위와 같은 형태
  6. router.push를 통해 home이름을 가진 라우터로 이동시킴(로그인 후 홈화면 이동)
  7. 에러가 발생했다면 어스에러 실행...

---

#### 로그인시 로그인, 회원 정보 vuex store에 저장하여 유지하고 로그아웃시 삭제🎊

- App.vue(가장 상위항목에서 실행)
  - 하위항목에서 항상 차있음
- logout actions를 실행하면서 resetToken과 resetCurrentUser, resetProfile을 실행하여 store에서 삭제

---

#### Vue.js에서 다음 주소찾기 api 활용하기🎄

```vue
<template>
...
  <div class="card-text pb-5">
    <input type="text" class="card-input mx-4" v-model="info.addr" id="sample6_address">
    <input type="text" class="card-input mx-4" v-model="info.zip_code" id="sample6_postcode">
    <input type="button" @click="findAddr" value="주소찾기">
  </div>
...
</template>

<script>
...

  methods: {
    findAddr() {
      new window.daum.Postcode({
          oncomplete: (data) => {
                // 팝업에서 검색결과 항목을 클릭했을때 실행할 코드를 작성하는 부분.

                //사용자가 선택한 주소 타입에 따라 해당 주소 값을 가져온다.
              if (data.userSelectedType === 'R') { // 사용자가 도로명 주소를 선택했을 경우
                  this.info.addr = data.roadAddress;
              } else { // 사용자가 지번 주소를 선택했을 경우(J)
                  this.info.addr = data.jibunAddress;
              }
              this.info.zip_code = data.zonecode

                // 우편번호와 주소 정보를 해당 필드에 넣는다.
              document.getElementById('sample6_postcode').value = data.zonecode;
              document.getElementById("sample6_address").value = this.info.addr;
          }
      }).open();
  }

...
</script>
```

- 기능
  - 주소찾기 버튼 클릭시 주소 검색 팝업창 오픈
  - 검색 후 선택한 주소 input 태그로 불러오기
  - v-model로 연동하여 연결

- 포인트
  - [다음 주소 검색 api](https://postcode.map.daum.net/guide) ... 친절하게 설명 됨
  - this. 을 사용하기 위해
    - `oncomplete: function(data) {...}`을 `oncomplete:(data) => {...}`으로 변경

---

#### vue router에 params 적용시 발생하는 `Uncaught (in promise) Error: Missing required param "username"` 해결하기🎋

- 문제 발생 포인트

  - router-link를 사용할 때 params로 getters에 저장된 currentUser.username을 전송하려 했음
    - 개발자 도구 vue-devtools에는 currentUser가 채워져있음...
  - 하지만 DOM이 그려질 때 이를 받아오는 것보다 탭이 먼저 렌더링되어 에러 발생
  - created, mounted, watch 등 여러 수단을 써보았지만 해결 안됨
  - `console.log() 찍으면 2회가 찍히는데 처음엔 undefined 다음엔 username이 정확하게 찍힘`
    - 이를 통해 '두 번' 불러와지고 그 사이에 오류가 뜨는구나 유추
  
- 해결 방법

  - v-if 문을 걸어서 username이 존재하는지 여부를 판단하고 router-link를 렌더링하는 방식을 채택

    ```vue
    <template>
      ...
        <div class="new-box" v-if="!!username">
          <router-link :to="{ name: 'myplant', params: { username } }">
              <button class="btn">내 식물</button>
          </router-link>
        </div>
      ...
    </template>
    ```

- **해결방법(추가, 쉬움)**

  - currentUser를 불러올 수는 있으나 특정 깊이 이상으로 가면 불러오지 못함
  - state나 getters에 원하는 값을 얕게 작성

  ```js
  import router from '@/router'
  import axios from 'axios'
  import drf from '@/api/drf'
  
  export const Account = {
    state: {
  	...
      currentUser: {},
      username: '',
      ...
    },
  
    getters: {
  	...
      currentUser: state => state.currentUser,
      username: state => state.username,
      ...
    },
  
    mutations: {
      ...
      SET_CURRENT_USER: (state, user) => {
        state.currentUser = user
        state.username = user.username
      },
      ...
    },
  
    actions: {
      ...
  }
  ```

---

#### select tag에서 값(option)이 선택되었을 때 서버로 요청보내기(@change 핸들러 사용)🎍

```vue
<template>
  <select class="sido mr-1" @change="beforeFetchSigungu($event)">
    <option selected>지역을 선택해주세요</option>
    <option v-for="(loc) in sido" :key="loc.pk" :value="loc.sido">{{ loc.sido }}</option>
  </select>
</template>

<script>
...    
  data() {
    return {
      info: {
          sido = ''
      }  
    }
  } 
...
  methods: {
    beforeFetchSigungu(event) {
      const sido = event.target.value
      this.info.sido = sido
    },      
  },
...      
</script>
```

- 기능
  - 주소를 검색할 때 드랍박스에서 지역(시, 도)을 선택하고, 동네(시, 군, 구)를 고르는 형식
  - 고를 때마다 data의 info에 담아주어 나중에 요청을 보낼 예정
- 포인트
  - select 태그의 option은 @click이 먹히지 않는다...
    - 처음에 이 방식으로 시도했으나 함수자체가 실행이 되지않아 당황
  - change 핸들러를 통해 event를 받아오고
  - console.log를 찍어가며 어디에 원하는 데이터가 있는지 파악해야 함

---

#### script에서 store로 dispatch(함수) 실행 시 데이터 넘길 때 주의사항🎎

- 데이터는 객체 형태로 넘겨야 한다!

  - 파이썬처럼 중괄호로 감싸면 객체로 인식하지 않음
  - 따로 변수에 할당하기

- 잘못된 예시들

  ```vue
  <script>
  export default {
    data() {
      retrun {
        info: {
          ...블라블라
        }
      }
    }
    ...
    methods: {
      ...
      beforeUpdateLeaf82(credentials) {
          ...
          this.updateLeaf82(credentials, this.info)
      // credentials는 template에서 받는 값, this.info는 data 에 저장된 값
      }
    },
  </script>
  ```

  ```vue
  <script>
  export default {
    data() {
      retrun {
        info: {
          ...블라블라
        }
      }
    }
    ...
    methods: {
      ...
      beforeUpdateLeaf82(credentials) {
          ...
          this.updateLeaf82({credentials, this.info})
      // credentials는 template에서 받는 값, this.info는 data 에 저장된 값
      // 중괄호 해봤자 넘어가서 어차피 객체로 인식못함  
      }
    },
  </script>
  ```

- 좋은 예시

  ```vue
  <script>
  export default {
    ...
    methods: {
      ...
      beforeUpdateLeaf82(credentials) {
          ...
          const updateInfo = {
            credentials,
            info: this.info
          }
          this.updateLeaf82(updateInfo)
      }
    },
  </script>
  ```

---

#### vuex를 사용할 때 created를해도 getters를 받아오지 못할 때 해결법(`watch 사용`)🎑

```vue
<script>
import { mapGetters , mapActions } from 'vuex'

export default {
  name: 'Leaf82Detail',
  data() {
    return {
      user: {
      },
      addr: {
      },
      info: {
        id: null,
        user: {
          nickname: '',
          photo: '',
          pk: null,
          username: '',
        },
        addr: {
          id: null,
          sido: '',
          sigungu: '',
        },
        plantname: '',
        photo: '',
        created_at: '',
        content: '',
        price: '',
        category_class: '',
        status_class: '',
        posting_addr: null
      },
      deleteInfo: {
        username: this.$route.params.username,
        posting_addr: this.$route.params.posting_addr
      }
    }
  },
  methods: {
    ...mapActions(['deleteLeaf82']),
    fillData() {
      this.user = this.leaf82Detail.user
      this.addr = this.leaf82Detail.addr
      this.info = this.leaf82Detail
      this.info.price = this.info.price.toLocaleString('ko-KR')
    }
  },
  computed: {
    ...mapGetters(['leaf82Detail', 'currentUser']),
  },
  watch: {
    leaf82Detail() {
      this.fillData()
    }
  }
}
</script>
```

- 발생한 에러
  - created때 상위components에서 fetchLeaf82Detail actions를 호출해 getters의  leaf82Detail을 채워줬으나, 받지 못함..
  - 콘솔창에 오류 발생, 렌더링 하면 데이터 날라감
- 해결책
  - `watch`
    - getters의 leaf82Detail값을 쳐다보고 있다가 변화가 발생하면,
    - data에 준비한 값을 채우고 그 값을 이용해 template에 띄어주는 방식

---

#### socket.io를 활용해서 채팅 구현하기🧧(미완성)

---

#### 이미지 업로드 시 보내고 받는 방법🎀

- 기능
  
  - 사진 선택 시 이미지를 우선적으로 보여줌
    - 사용자가 접근 후 모든 파일로 이동 가능(이미지가 아니라면 alert로 막아야 함)
  
  - 사진이 업로드 되기 전에는 기본이미지 보여주기
    - 최초에는 S3에서 생성된 url을 초기값으로 설정
  - 사진이 업로드 되면서 blob url 생성 후 대체 이미지 보여주기
    - 이미지와 글 클릭하면 파일 첨부 기능(라벨로 묶자)
    - 미리보기 변수가 필요하겠다!
  - 사진 백엔드로 보내기
    - 백엔드에서 S3로 파일 변환 후 이미지 url 저장
  
- 코드

  ```vue
  <template>
  ...
    <div class="left">
      <div class="img-box d-flex justify-content-center">
        <img :src="preview" alt="등록될 사진입니다.">
      </div>
      <div class="img-add-box d-flex justify-content-center pt-2">
        <label for="pic-file" class="img-add mb-0">
          <span class="material-symbols-outlined">
            photo_camera
          </span>
          <span>
            사진 변경하기
          </span>
        </label>
        <input type="file" id="pic-file" @change="onInputImage()" accept="image/*" ref="leaf82Image">
      </div>
    </div>
  </template>
  
  <script>
  import { mapActions , mapGetters } from 'vuex'
  
  export default {
    name: 'Leaf82NewForm',
    data() {
      return {
        credentials: {
          // 사진을 담아 보낼 변수 photo
          photo: '',
          ...
        },
        // 이미지 미리보기를 위한 변수
        // 디폴트는 백에서 S3로 생성한 이미지 url
        // 밑에서 첨부된 사진이 바뀔 때 이미지 url을 만들어 바꿔줄 예정
        preview: 'https://plantinum.s3.ap-northeast-2.amazonaws.com/static/monstera.jpg'
      }
    },
    methods: {
      ...mapActions(['fetchSido', 'fetchSigungu', 'createLeaf82']),
      ...
      beforecreateLeaf82(credentials) {
        if (credentials.plantname === '') {
          alert('이름을 입력해주세요.')
        } else if (credentials.price === '' || !Number.isInteger(parseInt(credentials.price))) {
          alert('가격을 확인해주세요.')
        } else if (credentials.sigungu === '') {
          alert('주소를 선택해주세요.')
        } else if (credentials.content === '') {
          alert('식물을 소개해주세요')
        } else {
          this.createLeaf82(credentials)
        }
      },
      onInputImage() {
        // data 값에 있는 photo 변수를 ref를 통해 이미지 파일에 접근
        this.credentials.photo = this.$refs.leaf82Image.files[0]
        // 임시 이미지 url 생성 (blob으로 없어지는 임시 데이터)
        const url = URL.createObjectURL(this.credentials.photo)
        // 이미지를 로드해주는 preview 변수에 담아줌
        this.preview = url
      },
    },
    ...
  }
  </script>
  ```

- 포인트

  - 이미지 미리보기 url 만들기 : `URL.createObjectURL(사진 파일)`
  - 이미지 미리보기를 위한 data 값 지정 : `preview`
  - 사진 선택 시 우선적으로 이미지 파일 선택하게 하기 : `accept="image/*"`

---

#### router-link로 이동할 때 스크롤 위치 최상단으로 이동하기(기본값으로는 스크롤 위치로 이동)🎞

```js
// src/router/index.js

// 함수 추가 전
const router = createRouter({
  history: createWebHistory(process.env.BASE_URL),
  routes,
});

// 함수 추가 후
const router = createRouter({
  history: createWebHistory(process.env.BASE_URL),
  routes,
  scrollBehavior(){
    return { top: 0 }
  },
});
```

- 문제점
  - 스크롤이 내려가 있는 상태에서 라우터를 통해 다른 페이지로 이동
    - 스크롤 위치가 그대로 페이지가 바뀜
- 해결
  - 페이지 이동 시 스크롤이 최상단으로 올라감

---

#### viewport 너비를 기준으로 화면 스타일 적용🎟

- 기능
  - 휴대폰 사이즈일때 배경 이미지 변경

```vue
<template>
<div class="boxes">
    <!-- first box를 바인딩해서 조건에따라 값을 변경 -->
    <div :class="firstBox">
      ...
    </div>
    ...
  </div>
</template>

<script>
export default {
  name: 'HomeView',
  data() {
    return {
      // 초기 너비는 윈도우의 이너 너비
      width: window.innerWidth,
      // 기본값으로는 'first-box' 설정
      firstBox: 'first-box',
    }
  },
  methods: {
    // 현재 너비를 수정해줄 함수
    handleResize() {
      this.width = window.innerWidth;
    },
    // 너비값이 바뀔 때마다 실행시켜줄 함수
    mobileOrPc() {
      if (this.width <= 576) {
        this.firstBox = 'first-box-mobile'
      } else {
        this.firstBox = 'first-box'
      }
    },
  },
  // 시작화면이 모바일인지 피씨인지 판별하기위해 초기 설정
  created() {
    this.mobileOrPc()
  },
  // 마운티드에 설정
  mounted() {
    window.addEventListener('resize', this.handleResize);
	},
  // 비포언마운트에 설정
  beforeUnmount() {
    window.removeEventListener('resize', this.handleResize);
  },
  //width 값이 바뀔 때마다 모바일인지 피씨인지 판별하는 함수 실행
  watch: {
    width() {
      this.mobileOrPc()
    }
  }
}
</script>

<style>
.first-box {
  height: 1117px;
  background: url("../assets/HomeView/background_img.jpg") bottom left;
  background-size: cover;
}

.first-box-mobile {
  height: 800px;
  background: linear-gradient(rgba(255, 255, 255, 0.6), rgba(255, 255, 255, 0.6)), url('../assets/HomeView/main_pic_1.jpg') bottom left;
  background-size: cover;
}
</style>
```

#### 더보기 클릭시 추가 데이터 받아오기🎢

- 흐름
  - `더보기` 버튼 클릭
  - 서버로 파라미터를 담아 요청(`page(몇번쨰 페이지인지), limit(몇개씩 받아올 건지)`)
  - 받아온 데이터  `vuex`에 담아주기
  - `watch`를 통해 vuex가 변경되면 `.vue`파일에 `data`채워주기

```vue
src/components/Leaf82Search.vue

<template>
...
	<!-- sellObject로 데이터를 받는데 next 값이 존재한다면(더 받을 데이터가 있는지 백엔드에서 검사) -->
    <div class="d-flex justify-content-center pb-5" v-if="isSell">
      <button class="more-btn" v-if="!!sellObject.next" @click="more()">- 더보기 -</button>
    </div>
    <div class="d-flex justify-content-center pb-5" v-if="!isSell">
      <button class="more-btn" v-if="!!buyObject.next" @click="more()">- 더보기 -</button>
    </div>
...
</template>

<script>

</script>
<script>
import { mapActions , mapGetters } from 'vuex'
import router from '@/router'

export default {
  name: 'Leaf82SearchList',

  //bList, sList를 채워서 v-for문으로 사용자에게 보여줌
  data () {
    return {
      isSell: true,
      info: {
        plantname: '',
        sido: '',
        sigungu: '',
        limit: 20,
        page: 1,
        category_class: '분양해요',
      },
      bList: [],
      sList: [],
      searchBox: '',
      create: '',
      title: '',
    }
  },

  methods: {
    ...mapActions(['fetchSigungu', 'search',]),

    fillList() {
      this.sList = this.sellList
      this.bList = this.buyList
      for (let item of this.sList) {
        const price = Number(item.price)
        item.price = price.toLocaleString('ko-KR')
        if (item.plantname.length > 7) {
          const plantname = item.plantname.substr(0, 7) + '...'
          item.plantname = plantname
        }
      }
      for (let item of this.bList) {
        const price = Number(item.price)
        item.price = price.toLocaleString('ko-KR')
        if (item.plantname.length > 7) {
          const plantname = item.plantname.substr(0, 7) + '...'
          item.plantname = plantname
        }
      }
    },
	
    // 더보기 버튼 클릭시 호출할 api
    more() {
      this.info.page += 1
      const params = this.info
      if (!this.info.plantname) {
        delete params.plantname
      }
      if (!this.info.sigungu) {
        delete params.sigungu,
        delete params.sido
      }
      this.search(params)
    },

	...
  },

  // sellObject, sellList, buyObject, buyList 값이 변화될 예정
  computed: {
    ...mapGetters(['sido', 'sigungu', 'isLoggedIn', 'sellObject', 'sellList', 'buyObject', 'buyList', 'device'])
  },

  created() {
    this.fetchSearch()
    this.changeDevice()
  },

  // 와치를 통해 값이 바뀔 때마다 데이터 값을 추가해줄 예정
  watch: {
    sellList() {
      this.fillList()
    },
    buyList() {
      this.fillList()
    },
    device() {
      this.changeDevice()
    }
  }
}
</script>

<style>

</style>
```

```js
import axios from 'axios'
import drf from '@/api/drf'
import router from '@/router'

export const Leaf82 = {
  state: {
	...
    sellObject: {},
    sellList: [],
    buyObject: {},
    buyList: [],
    ...
  },

  getters: {
    ...
    sellObject: state => state.sellObject,
    sellList: state => state.sellList,
    buyObject: state => state.buyObject,
    buyList: state => state.buyList,
    ...
  },

  mutations: {
    ...
    // set은 첫 불러오기 add는 추가하기
    // count는 데이터 총 개수
    // next는 불러온 데이터들 뒤에 데이터를 더 불러올 수 있는지, 개수와 page 변수로 판단
    // previous는 이전 데이터가 있는지
    SET_SELLOBJECT: (state, sellObject) => {
      state.sellObject = {
        count: sellObject.count,
        next: sellObject.next,
        previous: sellObject.previous
      }
      state.sellList = sellObject.results
    },
    // sellList에 데이터들 for 문으로 돌려주기
    ADD_SELLOBJECT: (state, sellObject) => {
      state.sellObject = {
        count: sellObject.count,
        next: sellObject.next,
        previous: sellObject.previous
      }
      for (let result of sellObject.results) {
        const price = Number(result.price)
        result.price = price.toLocaleString('ko-KR')
        if (result.plantname.length > 7) {
          const plantname = result.plantname.substr(0, 7) + '...'
          result.plantname = plantname
        }
        state.sellList.push(result)
      }
    },
    SET_BUYOBJECT: (state, buyObject) => {
      state.buyObject = {
        count: buyObject.count,
        next: buyObject.next,
        previous: buyObject.previous
      }
      state.buyList = buyObject.results
    },
    ADD_BUYOBJECT: (state, buyObject) => {
      state.buyObject = {
        count: buyObject.count,
        next: buyObject.next,
        previous: buyObject.previous
      }
      for (let result of buyObject.results) {
        const price = Number(result.price)
        result.price = price.toLocaleString('ko-KR')
        if (result.plantname.length > 7) {
          const plantname = result.plantname.substr(0, 7) + '...'
          result.plantname = plantname
        }
        state.buyList.push(result)
      }
    },
    ...
  },

  actions: {
    // 서치로 axios 요청
    // params로 데이터를 보내줄 예정
    // page가 1이라면 초기 요청이기에 set, 그게 아니라면 add
    search({ commit }, params) {
      axios({
        url: drf.leaf82.search(),
        method: 'get',
        params
      })
      .then(res => {
        if (params.category_class === '분양해요' && params.page === 1) {
          commit('SET_SELLOBJECT', res.data)
        } else if (params.category_class === '분양해요' && params.page !== 1) {
          commit('ADD_SELLOBJECT', res.data)
        } else if (params.category_class === '분양받아요' && params.page === 1) {
          commit('SET_BUYOBJECT', res.data)
        } else {
          commit('ADD_BUYOBJECT', res.data)
        }
      })
      .catch(err => {
        console.log(err)
      })
    },

    ...
}
```

#### 배너 이미지 비율 고정🏞

```vue
<template>
  ...
    <!-- 배경 화면 -->
    <div class="container my-0">
      
    </div>
    ...
</template>
```

```css
.container {
  height: 50vh;
  margin: 0;
  padding: 0;
  max-width: 1920px;
}

.banner-img {
  background-image: url('../assets/MyplantView/banner_img-02.svg');
  height: 100%;
  width: 100%;
  margin: 0;
  background-size: cover;
}
```

- 기능
  - 화면이 줄어들 때 배너 이미지의 비율이 망가지지 않고 자리 차지하게 함
- 포인트
  1. 이미지 바깥 태그의 `heignt`값을 `vh`로 설정함
     - `vh` : 뷰포트의 초기 컨테이닝 블록 높이 1%와 같음
  2. `background-size: cover` 
     - 이미지가 찌그러지지 않는 한도 내에서 제일 크게 설정함
     - 이미지의 가로 세로 비율이 요소와 다르다면 이미지를 세로 또는 가로 방향으로 잘라내어 빈 공간이 생기지 않도록 설정함
  3. 이미지가 잘라질 것을 고려하여 가로로 긴 이미지를 준비해서 적용함

#### 모달창 띄우기☁

```vue
...
<div class="row plant-btn-group">
  <button class="btn plant-info-btn" type="button" @click="changeModal(1)">계절별 식물 관리 정보</button>
    ...
  <div class="black-bg" @click="close($event)" v-if="modal===1 || modal===2 ">
    <div class="modal-bg myplant-modal">
      <!-- 계절별 식물 관리 정보 모달 -->
      <div v-if="modal===1">
        <h5>계절별 식물 관리 정보</h5>
        <div class="season">봄</div>{{ myplant.plant_info?.watercycle_spring_nm }}
        <div class="season">여름</div>{{ myplant.plant_info?.watercycle_summer_nm }}
        <div class="season">가을</div>{{ myplant.plant_info?.watercycle_autumn_nm }}
        <div class="season">겨울</div>{{ myplant.plant_info?.watercycle_winter_nm }}
      </div>
      ...
      <button class="modal-close-btn">닫기</button>
    </div>
  </div>
    ...
```

```vue
<script>
import { mapGetters, mapActions } from 'vuex'

export default {
  ...
  methods: {
    ...
    close(event) {
      if (event.target.classList.contains('black-bg') || event.target.classList.contains('modal-close-btn')) {
        this.modal = 0
      }
    },
    changeModal(num) {
      this.modal = num
    }, 
    ...
  },
  ...
}
</script>
```

```css
.black-bg {
  width: 100%;
  height: 100%;
  background: rgba(0, 0, 0, 0.4);
  position: fixed;
  top: 0px;
  left: 0px;
}

.myplant-modal {
  position: relative;
  top: 150px;
}

.modal-bg {
  width: 80vw;
  ...
}

.modal-close-btn {
  ...
  margin-left: auto;
  display: block;
  ...
}
```

- 기능
  - 버튼 클릭하면 모달창 띄움
- 포인트
  1. 모달은 새 페이지가 아니라 `<div>`의 위치값을 지정하는 것
  2. 모달이 띄워질 때 뒷 배경이 어둡게 처리되는 것 = `<div>` 태그 배경 색을 약간 투명한 검은색으로 처리
  3. 모달창 위치를 잡기 위해 `black-bg` 태그가 최상단에 위치
     - `modal`태그는 `black-bg` 안에 위치함
     - `modal`태그 위치값은 `black-bg`를 기준으로 `relative`
  4. `black-bg`가 뷰 화면 전체를 덮기 위해 `width: 100%`, `height: 100%`, `position: fixed`로 하여 좌상단 꼭지점이 뷰 화면의 좌상단과 일치하게 만듦
  5. 모달이 띄워졌을 때 모달 창을 내리는 방법 = 모달 밖 배경을 클릭 or  모달 내의 닫기 버튼 클릭
     1. 모달 밖 배경을 클릭
        - `event.target.classList.contains('black-bg')`
     2. 모달 내의 닫기 버튼 클릭
        - `event.target.classList.contains('modal-close-btn')`
  6. 서로 다른 내용의 모달 띄우는 방법
     - 모달 마다 번호를 매겨 클릭할 때 `changeModal`함수를 일으킴

#### 오른쪽 하단에 등록 버튼 고정시키기🎯

```vue
<template>
  ...
    <!-- 추가 버튼 (스티키 바텀) -->
    <div class="create-btn" v-if="mypage">
      <router-link class="add px-5 mx-5 pb-5" :to="{ name: 'myplantNew' }">
        <button class="btn">
          <span class="material-symbols-outlined">add</span>
        </button>
      </router-link>
    </div>
  ...
</template>
```

```css
.create-btn {
  position: sticky;
  bottom: 15px;
  text-align: end;
  }
```

- 기능
  - 스크롤로 화면을 이동해도 항상 오른쪽 하단에 정해진 위치에 등록 버튼이 따라 다님
- 포인트
  1. `position: sticky` : 위치를 고정시키기 위해
  2. `bottom: 15px` : 뷰 화면 맨 밑에서 약간 떨어진 곳에 위치
  3. `text-align: end` : 오른쪽 정렬로 버튼 위치를 오른쪽에 위치 시킴

#### 마우스 오버시 활성화 효과✨

```vue
<template>
  ...
        <button class="btn">
          <span class="material-symbols-outlined">add</span>
        </button>
  ...
</template>
```

```css
.btn{
  border-radius: 100%;
  height: 60px;
  width: 60px;
  background-color: #b2c9ab;
  color: white;
}

.btn:hover {
  background-color: #65805d;
  transition: all 0.5s;
}
```

- 기능
  - 마우스 오버 시 색상이 바뀌도록하여 사용자에게 클릭할 수 있는 버튼임을 인식하게 함
- 포인트
  1. `:hover` : 마우스 오버시 적용할 css를 담을 수 있음
  2. transition
     - 엘리먼트의 두 가지 상태 사이에 변화를 줄 수 있음
     - 엘리먼트의 상태란, `:hover`나 `:active` 또는 자바스크립트를 사용해 동적으로 만들어진 것
     - `transition: property name | timing function | duration | delay`의 형태로 작성됨
       - property name : 1개 이상의 속성 값을 적용할 수 있음
       - 순서 중요함 : 시간으로 해석될 수 있는 값이 첫 번째면 duration으로, 두 번째면 delay로 적용됨
     - `transition: all 0.5s` : 모든 요소를 0.5초 delay 후 바꿈

#### 객체 안의 객체의 값을 사용하는 방법🧪

###### 1. 객채 안에 값이 있는지 확인하고 그 안에서 값 가져오기

```vue
<div v-if="myplant.plant_info?.name!=='직접 입력하기'" class="myplant-data botanical-name">{{ myplant.plant_info?.name }}</div>
```

- `?.` 
  - `myplant`라는 객체 안에 `plant_info`라는 값이 있는지 먼저 확인함
  - 만약 값을 받아오는 과정에서 `plant_info`값이 있으면 그 안에 있는 `name`을 받아옴

###### 2. 자주 쓰는 값이라면 최초 1회에 받아올 때 다른 곳에 저장함

```vue
<router-link class="nav-link pb-0 mx-2" :to="{ name: 'myplant', params: { username } }" :style="[isMyplant ? {fontWeight: 700} : {fontWeight: 400}]" v-if="!!username">내 식물</router-link>
```

- 상황 설명

  - `username`은 `currentUser`라는 객체 안에 있는 값
    - `created`때 `currentUser`는 받아오지만 아직 그 안에 있는 `username`에 접근하지는 못함
      => 값에 접근하지 못하므로 콘솔창에 에러를 먼저 띄움
      => 에러를 띄운 뒤에 값에 접근해서 동작하는 데에는 문제 없음

- 해결 방법

  - `currentUser`를 저장할 때 `username` 변수를 vuex의 `state`에 저장해두는 방식으로 변경

    ```js
    export const Account = {
      state: {
        ...
        currentUser: {},
        username: localStorage.getItem('username') || '',
        ...
      },
        ...
        fetchCurrentUser({ commit, getters, dispatch }) {
          if (getters.isLoggedIn) {
            axios({
              url: drf.accounts.currentUserInfo(),
              method: 'get',
              headers: getters.authHeader,
            })
            .then(res => {
              commit('SET_CURRENT_USER', res.data)
              localStorage.setItem('username', res.data.username)
            })
            .catch(err => {
              if (err.response.status === 401) {
                dispatch('removeToken')
                router.push({ name: 'login' })
              }
            })
          }
        },
    ```

    - `username`을 `localStorage`에 저장한 이유 : vuex는 새로고침하면 값을 모두 날림
      -> 자주 접근해서 쓰는 값이라면 `localStorage`에 저장해서 쓰는 방식이 경제적

  - 그럼에도 값에 접근하지 못하는 상황 종종 발생

    ```vue
    <router-link class="nav-link pb-0 mx-2" :to="{ name: 'myplant', params: { username: username } }" :style="[isMyplant ? {fontWeight: 700} : {fontWeight: 400}]" v-if="!!username">내 식물</router-link>
    ```

    - `v-if="!!username"` 이라는 조건문을 달아 `username`이라는 값이 존재할 때에만 router-link가 동작하게 만듦
    - 조건문이 없어도 동작하는 데에는 문제가 없지만 에러를 제거하기 위한 시도

#### progress bar📈

```vue
<progress :value=otpTimer max="60" class="progress-bar"></progress>
```

```css
.progress-bar {
  appearance: none;
  background-color: white;
  text-align: center;
  width: 80%;
  margin: 1rem 0;
}
.progress-bar::-webkit-progress-bar {
  background:#e9e9e9;
  border-radius:10px;
}
.progress-bar::-webkit-progress-value {
  border-radius:10px;
  background: #B2C9AB;
  transition: width 1s linear;
}
```

- 기능
  - 바인딩한 수치값에 따라 상태바 형태로 값을 표현함
- 포인트
  1. 원하는 수치값을 바인딩
     - `:value=otpTimer`
       - 타이머가 카운트다운하면 변하는 값을 progress bar의 value값으로 연결함
  2. `-webkit-`
     - 웹 브라우저를 만드는 데 기반을 제공하는 오픈 소스 응용 프로그램 프레임워크
     - `-webkit-` : 구글, 사파리
     - `-mox-` : 파이어폭스

#### OTP 타이머⏱

```vue
<div v-if="!myplant.is_connected && !!temp_OTP" class="otp-timer">
    <div>다음 숫자를 화분에 입력해주세요</div>
    <div class="otp-number">{{ temp_OTP }}</div>
    <div v-if="otpTimer > 0">{{ otpTimer }}초</div>
    <div v-if="otpTimer <= 0">0</div>
    <div class="d-flex justify-content-center">
        <progress :value=otpTimer max="60" class="progress-bar"></progress>
    </div>
</div>
```

```vue
<script>
import { mapGetters, mapActions } from 'vuex'

export default {
  ...
  computed: {
    ...mapGetters(['myplant', 'isOwner', 'temp_OTP', 'otpTimer']),
    ...
  },

  methods: {
    ...mapActions(['fetchMyplant', 'fetchOTP', 'checkOTP', 'disconnectMyplant', 'countTime', 'deleteMyplant', 'removeOTP']),
    ... 
    startTimer() {
      const interval = setInterval(() => {
        this.checkOTP(this.myplantPk)
        this.countTime(this.otpTimer - 1)
        if (this.otpTimer <= 55 && this.temp_OTP === null) {
          this.stopTimer(interval)
          this.fetchMyplant(this.myplantPk)
          this.modal = 0
        } else if (this.myplant.is_connected===true) {
          this.stopTimer(interval)
          this.temp_OTP = null
          this.modal = 0
        }
      }, 1000)
      return interval},
    stopTimer(Timer) {
      clearInterval(Timer)
      this.countTime(60)
      this.modal = 0
    }
  },
  created() {
    this.fetchMyplant(this.$route.params.plantPk)
    if (this.temp_OTP) {
      this.startTimer()
    }
  },
}
</script>
```

- 기능
  - OTP를 입력할 수 있는 60초를 카운트다운

- 포인트
  1. `setInterval` : 일정 시간 간격으로 반복해서 함수를 실행함
     - 첫 번째 인자 : 실행할 코드 혹은 함수
     - 두 번째 인자 : 반복 주기(ms)
     - Interval ID를 반환함 (함수를 호출할 때마다 내부적으로 생성되는 타이머 객체)
     - 이 값을 인자로 `clearInterval()`함수를 호출하면 코드가 주기적으로 실행되는 것을 중단시킬 수 있음
  2. `clearInterval()` : `Interval ID`를 인자로 받아 `setInverval`함수를 중단시킴
- 해결해야 될 점:warning:
  - OTP 타이머가 카운트다운 되는 도중 뒤로가기 혹은 다른 페이지로 이동하는 경우 타이머가 끝나지 않음
  - DB에서 otp_code를 `null`값으로 받아와도 타이머가 계속 실행됨
  - 새로고침하면 타이머가 초기화됨

###### OTP 오류 해결

```vue
<script>

export default {
  name: 'MyplantDetailView',
  data() {
    return {
      ...
      interval: 0,
    }
  },
  ...
  computed: {
    ...mapGetters(['myplant', 'isOwner', 'temp_OTP', 'otpTimer']),
    ...
  methods: {
    ...mapActions(['fetchMyplant', 'fetchOTP', 'checkOTP', 'disconnectMyplant', 'countTime', 'deleteMyplant', 'removeOTP']),
    close(event) {
      if (event.target.classList.contains('black-bg') || event.target.classList.contains('modal-close-btn')) {
        if (this.modal === 3) {
          this.stopTimer(this.interval)
          this.countTime(60)
          this.removeOTP(this.myplantPk)
          this.interval = 0
        }
        this.modal = 0
      }
    },
    changeModal(num) {
      this.modal = num
    },
    startTimer() {
      this.interval = setInterval(() => {
        this.checkOTP(this.myplantPk)
        this.countTime(this.otpTimer - 1)
        if (this.otpTimer <= 55 && this.temp_OTP === null) {
          this.stopTimer(this.interval)
          this.fetchMyplant(this.myplantPk)
          this.modal = 0
        } else if (this.myplant.is_connected===true) {
          this.stopTimer(this.interval)
          this.temp_OTP = null
          this.modal = 0
        }
      }, 1000)
      return this.interval},

    stopTimer(Timer) {
      clearInterval(Timer)
      this.countTime(60)
      this.modal = 0
    },
  },
  created() {
    this.fetchMyplant(this.$route.params.plantPk)
    if (this.temp_OTP) {
      this.removeOTP(this.myplantPk)
      this.countTime(60)
    }
  },

  beforeUnmount() {
    if (this.temp_OTP !== null) {
      this.stopTimer(this.interval)
      this.countTime(60)
      this.removeOTP(this.myplantPk)
    }
  },

}
</script>
```

- 기능
  - 모달창 닫기 버튼 클릭 시, 페이지 새로고침 시, 다른 페이지로 이동 시 연결 시도 중단
- 포인트
  1. `setInterval` 함수가 반환하는 `Interval ID`를 data에 선언해서 변경해 사용함
     - 페이지 이동 시 `Interval ID`를 인자로 받아 타이머를 중단하기 위해
  2. `beforeUnmount()` 사용
     - 페이지 이동, 페이지 새로고침 시 연결 시도 중단하기 위해
  3. `created()` 에서도 OTP코드가 남아있다면 초기화

#### form 하나로 create, update 다루기🖍

NewView

```vue
<template>
  <div class="new-myplant">
    <nav-bar></nav-bar>
    <myplant-form :myplant="myplant" action="create" class="mt-3"></myplant-form>
  </div>
</template>

<script>
...
import MyplantForm from '@/components/MyplantForm.vue'

export default {
  name: 'MyplantNewView',
  components: { NavBar, MyplantForm },
  data() {
    return {
      myplant: {
        nickname: '',
        photo: '',
        plantname: '',
        tmp: '',
      }
    }
  }
}
</script>
```

EditView

```vue
<template>
  <div class="edit-myplant">
    <nav-bar></nav-bar>
    <myplant-form :myplant="myplant" action="update" class="mt-3"></myplant-form>
  </div>
</template>

<script>
...
import MyplantForm from '@/components/MyplantForm.vue'
import { mapGetters, mapActions } from 'vuex'

export default {
  name: 'MyplantEdit',
  components: { NavBar, MyplantForm },
  computed: {
    ...mapGetters(['myplant'])
  },
  methods: {
    ...mapActions(['fetchMyplant'])
  },
  created() {
    this.fetchMyplant(this.$route.params.plantPk)
  }
}
</script>
```

Form

```vue
<template>
  ...
      <form @submit.prevent="onSubmit">
        ...
                <input @change="onInputImage" accept="image/*" ref="newMyplantImage" type="file" class="form-input" id="myplantPhoto">
              ...
        ...
            <input v-model="newMyplant.nickname" type="text" class="form-input" id="myplantNickname" placeholder="식물 닉네임을 입력해주세요.">
          ...
      </form>
    ...
</template>

<script>
import { mapGetters, mapActions } from 'vuex'

export default {
  name: 'MyplantForm',
  props: {
    myplant: Object,
    action: String,
  },
  data() {
    return {
      newMyplant: {
        nickname: this.myplant.nickname,
        photo: this.myplant.photo,
        plantname: this.myplant.plant_info?.name,
        tmp: this.myplant.tmp,
      },
      newMyplantImage: this.action==='create' ? 'https://plantinum.s3.ap-northeast-2.amazonaws.com/static/monstera.jpg' : this.myplant.photo,
    }
  },
  ...
  methods: {
    ...mapActions(['createMyplant', 'searchPlant', 'updateMyplant']),
    ...
    onSubmit() {
      ...
      if (this.action === 'create') {
        this.createMyplant(this.newMyplant)
      } else if (this.action === 'update') {
        if (this.newMyplant.photo === this.myplant.photo) {
          this.newMyplant.photo = 'same'
        }
        const payload ={
          plantPk: this.myplant.id,
          ...this.newMyplant,
        }
        this.updateMyplant(payload)
      }
    },
  },
  ...
}
</script>
```

- 기능
  - 각 페이지에서 데이터와 action 값을 보내어 form에서 받은 값을 토대로 새로운 등록 값을 만듦
- 포인트
  1. 각 페이지에서 form으로 데이터를 prop
  2. `action`을 구분하기 위해 string으로 prop
  3. `create`일 때는 빈 값을, `update`일 때는 해당 데이터를 넘겨주어 입력창을 채워 넣음

#### form에 이미지 넣기📷

```vue
...
<form>
    <div class="mb-3 img-section">
          <div class="preview-section">
            <label for="myplantPhoto" class="img-add">
              <img :src="newMyplantImage" alt="내식물 등록 이미지" class="preview-myplant-image">
            </label>
          </div>
            <div class="img-add-div">
              <label for="myplantPhoto" class="img-add">
                <span class="material-symbols-outlined img-add-icon">photo_camera</span>
                <span>사진 등록하기</span>
                <input @change="onInputImage" accept="image/*" ref="newMyplantImage" type="file" class="form-input" id="myplantPhoto">
              </label>
              <span class="px-2">|</span>
              <label for="photo-delete">
                <span @click="onDeleteImage" class="img-delete-btn img-add">
                  <span class="material-symbols-outlined img-add-icon">imagesmode</span>
                  <span>기본 이미지로</span>
                </span>
              </label>
            </div>
        </div>
</form>
```

```vue
<script>
import { mapGetters, mapActions } from 'vuex'

export default {
  ...
  data() {
    return {
      newMyplant: {
        nickname: this.myplant.nickname,
        photo: this.myplant.photo,
        plantname: this.myplant.plant_info?.name,
        tmp: this.myplant.tmp,
      },
      newMyplantImage: this.action==='create' ? 'https://plantinum.s3.ap-northeast-2.amazonaws.com/static/monstera.jpg' : this.myplant.photo,
    }
  },
  ...
  },
  methods: {
    ...
    onInputImage() {
      this.newMyplant.photo = this.$refs.newMyplantImage.files[0]
      const url = URL.createObjectURL(this.newMyplant.photo)
      this.newMyplantImage = url
    },
    onDeleteImage() {
      this.newMyplant.photo = ''
      this.newMyplantImage = 'https://plantinum.s3.ap-northeast-2.amazonaws.com/static/monstera.jpg'
    },
    onSubmit() {
      ...
      if (this.action === 'create') {
        this.createMyplant(this.newMyplant)
      } else if (this.action === 'update') {
        if (this.newMyplant.photo === this.myplant.photo) {
          this.newMyplant.photo = 'same'
        }
        const payload ={
          plantPk: this.myplant.id,
          ...this.newMyplant,
        }
        this.updateMyplant(payload)
      }
    },
  },
  created() {
    this.searchPlant()
  },
}
</script>
```

- 기능
  - 이미지를 file값으로 form에 넣어서 전공
  - DB에서 받아서 쓰는 이미지는 string(정확히는 url 주소)
- 포인트
  1. `<input>`태그의 `type=file`로 하여 유저의 로컬 파일을 입력 받음
     - `accept="image/*"` 조건을 걸어 이미지 파일만 먼저 필터링해서 볼 수 있게끔 함
  2. 이미지를 입력받고 미리보기 사진을 띄우기 위해 `onInputImage`함수를 만들어서 사용함
     - 입력받은 이미지 `file`을 `url`로 바꾸는 과정
     - `ref="newMyplantImage"` : ref 속성을 부여한 자식 태그를 호출하기 위해 사용
       - `this.newMyplant.photo = this.$refs.newMyplantImage.files[0]`와 같이 입력값을 가공하기 위해 사용함
     - 입력받은 파일 값을 `URL.createObjectURL`을 통해 url 주소값으로 변경하여 사용
  3. 이미지 태그에 `src`를 바인딩해 변하는 값을 띄울 수 있도록 함
  4. 미리보기 이미지와 `input` 태그 모두 같은 id를 가진 `label`로 감싸주어 이미지를 클릭해도, 등록하기를 클릭해도 이미지 파일을 입력받을 수 있도록 함
  5. 사진을 기본 이미지로 변경 시, django에는 빈 문자열을 보내주고, 미리보기는 디폴트 값으로 변경해줌
  6. `update`시에는 넘겨받은 이미지 값은 `string`이고 form에 넣는 값은 `file`이므로 `submit`하기 전에 이전값과 같은 값인지 확인해줌
     - 같은 값이라면 `'same'`이라는 문자열을 담아 전송하고 django에서 처리해줌

#### 검색을 통해 option 리스트 필터링🔍

```vue
<template>
	....
          <div class="select-plant mb-3" v-if="action==='create'">
            <input type="text" id="plant" list="search-plant-list" placeholder="식물 종류를 검색하세요." class="form-input" v-model="newMyplant.plantname">
            <datalist id="search-plant-list">
              <option v-for="(plant) in plant_list" :key="plant.pk">{{ plant.name }}</option>
            </datalist>
            <input v-if="newMyplant.plantname==='직접 입력하기'" type="text" id="tmp-plant" placeholder="식물 종류를 직접 입력해주세요." class="form-input mt-3" v-model="newMyplant.tmp">
          </div>
          <div class="select-plant mb-3" v-if="action==='update'">
            <input v-if="newMyplant.plantname!=='직접 입력하기'" type="text" id="plant" :placeholder="myplant.plant_info.name" class="form-input disabled-input" disabled>
            <input v-if="newMyplant.plantname==='직접 입력하기'" type="text" id="plant" :placeholder="myplant.tmp" class="form-input disabled-input" disabled>
          </div>
        </div>
</template>
```

- 기능
  - `input`태그에 검색어를 입력하면 해당 검색어로 필터링된 데이터 리스트를 띄워줌
- 포인트
  - `input` 태그의 `type`은 `text`
  - `input`태그에 `list="search-plant-list"`를 넣고 `datalist` 태그에 `id`를 동일한 값으로 넣어 검색어로 필터링된 리스트를 띄울 수 있게 함
  - `select` vs. `datalist`
    - `select`는 정해진 데이터만 받아서 쓸 수 있음
    - `datalist`는 미리 정해진 값 이외에도 사용자가 임의로 입력한 변수값도 데이터 입력을 받음
- 문제점:warning:
  - 안드로이드에서는 datalist를 보여주지 못함

#### 내비게이션 바에서 현재 탭일 때 활성화 표시🚩

```vue
<template>
  <nav class="navbar navbar-expand-lg navbar-light px-4">
    ...
    <div class="collapse navbar-collapse" id="navbarSupportedContent">
      <ul class="navbar-nav mr-auto">
        ...
        <li class="nav-item dropdown">
          <a class="nav-link dropdown-toggle pb-0 mx-2" href="#" id="navbarDropdown" role="button" data-toggle="dropdown" aria-haspopup="true" aria-expanded="false" :style="[isLeaf82 ? {fontWeight: 700} : {fontWeight: 400}]">
            잎팔이
          </a>
          <div class="dropdown-menu" aria-labelledby="navbarDropdown">
            <div>
              <router-link class="dropdown-item" :to="{ name: 'leaf82' }">거래</router-link>
            </div>
            
            <router-link class="dropdown-item" :to="{ name: 'messenger' }" v-if="isLoggedIn">채팅</router-link>
            <router-link class="dropdown-item" :to="{ name: 'login' }" v-if="!isLoggedIn">채팅</router-link>
          </div>
        </li>
        ...
  </nav>
</template>

<script>
import { mapGetters, mapActions } from 'vuex'

export default {
  name: 'NavBar',

  data() {
    return {
      ...
      leaf82Group: ['leaf82', 'leaf82New', 'leaf82Detail', 'leaf82Edit', 'messenger'],
      ...
  },

  computed: {
    ...
    isLeaf82() {
      return this.leaf82Group.includes(this.$route.name)
    },
  ...
}
</script>
```

- 기능
  - 하나의 탭에 연결된 페이지가 많을 때 해당 페이지에서 모두 같은 탭을 활성화 표시하기
- 포인트
  1. leaf82의 하위 페이지들을 모두 리스트로 만들어둠
  2. `isLeaf82()`에서 현재 route 페이지의 이름이 `leaf82Group`에 포함되어 있다면 `true`값을 반환함
  3. `li`태그의 `style`을 바인딩하여 활성화 표시 여부를 결정함
     - 삼항 연산자를 사용하여 `true`값이면 굵은 글씨를, `false`값이면 얇은 글씨를 적용하도록 함

#### vuex-persistedstate💾

```js
import { createStore } from 'vuex'
import { Account } from './modules/accounts'
import { Myplant } from './modules/myplant'
import { Leaf82 } from './modules/leaf82'
import { Timer } from './modules/timer'
import { Messenger } from './modules/messenger'
import createPersistedState from "vuex-persistedstate"

export default createStore({
  modules: { 
    Account, Myplant, Leaf82, Timer, Messenger,
  },
  plugins: [createPersistedState({
    paths: ['Timer',]
  })],
})
```

- 기능
  - 새로고침하면 vuex의 데이터가 모두 날아가는 것을 방지
- 포인트
  - vuex에 있는 모든 데이터를 저장해서 쓰면 성능 저하 발생함
  - 유지시킬 데이터만 따로 모듈화해서 지정해줌
  - `Timer`의 경우 새로고침을 해도 카운트다운이 멈추지 않도록 하기 위해 설정해놓음

#### 정해진 url이 아닐 때 404페이지로 이동🏃‍♂️

```js
import { createRouter, createWebHistory } from 'vue-router'
...
import NotFound404 from '@/views/NotFound404.vue'

import store from '../store'

const routes = [
  ...
  //404
  {
    path: '/404',
    name: 'NotFound404',
    component: NotFound404,
  },
  {
    path: "/:catchAll(.*)",
    name: 'catch-all',
    redirect: '/404'
  },
]
...
```

- 기능
  - 지정해놓은 url이 아닌 주소로 사용자가 접근할 경우 자동으로 404 페이지로 이동시킴
- 포인트
  1. 이전 버전 : `path: '*'`
     `vue-router@next` 버전 : `path: "/:catchAll(.*)"`

#### 채팅창의 스크롤을 최근 채팅에 고정시키기💬

```vue
<template>
  ...
                <!-- 채팅 내용 -->
                <div class="col-md-6 col-lg-7 col-xl-8">
                  <div class="you-username" v-if="now_receiver!==-1">{{ nicknames[now_receiver] }}</div>
                  <div class="chat-view" ref="now_messages">
                    ...
                      <!-- 채팅방 클릭 후 -->
                    <div v-for="msg in now_messages" :key="msg">
                      ...
                  <!-- 채팅 메시지 적는 부분 -->
                  <div class="d-flex justify-content-start align-items-center" v-if="now_receiver!==-1">
                    <input v-model="message" type="text" class="form-input" id="exampleFormControlInput2"
                      placeholder="Type message" @keyup.enter="sendMessage">
                    <span @click="sendMessage" class="material-symbols-outlined send-btn">send</span>
                  </div>
</template>
```

```vue
<script>
...
import { mapActions, mapGetters } from "vuex"
import { io } from 'socket.io-client'

export default {
  ...
  data(){
    return {
      socket: null,
      id: -1,
      message: '',
      now_messages: [],
      now_receiver: -1, // 새로고침 했거나, 거래탭에서 채팅하기로 넘어오지 않았을 경우
      rooms: {},
      urls: {},
      baseURL: "https://plantinum.s3.ap-northeast-2.amazonaws.com/",
      nicknames: {},
    }
  },
  ...
  methods : {
    ...
    sendMessage() {
      // 소켓을 통해 서버로 메세지를 보낸다.
      if(this.now_receiver == -1){
        return;
      }
      this.socket.emit('send', {receiver:this.now_receiver , msg: this.message, room_num:this.rooms[this.now_receiver]});
      this.message = ''
    },
  ...
  watch: {
    now_messages() {
      this.$nextTick(() => {
        let now_messages = this.$refs.now_messages;
        now_messages.scrollTo({ top : now_messages.scrollHeight, behavior: 'smooth' })
      })
    }
  },

  updated() {
    let now_messages = this.$refs.now_messages;
    now_messages.scrollTo({ top : now_messages.scrollHeight, behavior: 'smooth' })
  }
  
}
</script>
```

- 기능
  - 채팅 메시지가 새로 입력되었다면(혹은 메시지를 새로 받았다면) 최신 메시지에 맞춰 스크롤이 자동으로 내려가게 함
- 포인트
  1. `watch` : 내가 메시지를 입력했을 때 now_messages의 변화를 감지함
  2. `updated` : 상대방이 메시지를 입력하여 now_messages가 변화하는 것을 감지함
  3. `scrollTo()` : 지정된 위치로 스크롤
     - `scrollTo(x좌표, y좌표)`
     - `scrollTo({ top, left, behavior})`
       - `behavior` : 스크롤 효과 속성
         - `auto` : 기본값, 바로 위치로 이동
         - `smooth` : 부드럽게 이동
     - `scrollHeight` : 스크롤되는 부분을 포함한 실제 요소의 높이값
       - 0이 상단이므로 `scrollHeight`로 하게되면 최하단에 위치하게 됨
  4. `$nextTick()` : 다음 렌더링 사이클 이후 실행될 콜백 함수를 등록할 수 있는 기능을 제공하는 메서드
     - 데이터의 상태가 변경되었으나 화면에 변경된 상태가 반영되지 않는 경우 이 메서드를 사용하여 다시 렌더링하며 반영시킬 수 있음

#### 스크롤바 커스텀🖌

```css
.chat-view::-webkit-scrollbar {
  width: 10px;
}
.chat-view::-webkit-scrollbar-thumb {
  background-color: #EFEFEF;
  border-radius: 10px;
  background-clip: padding-box;
  border: 2px solid transparent;
}
.chat-view::-webkit-scrollbar-track {
  background-color: white;
  border-radius: 10px;
}
```

- 포인트
  - `::-webkit-scrollbar` : 스크롤바 영역에 대한 설정
  - `::-webkit-scrollbar-thumb` : 스크롤바 막대에 대한 설정
  - `::-webkit-scrollbar-track` : 스크롤바 뒷 배경에 대한 설정
- 문제점:warning:
  - 크롬, 사파리를 제외한 브라우저에서는 지원하지 않음

#### 띄어쓰기, 줄바꿈 그대로 입력하기✏

```vue
<template>
  ...
                  <div class="d-flex justify-content-start align-items-center" v-if="now_receiver!==-1">
                    <textarea v-model="message" type="text" class="form-input" id="exampleFormControlInput2"
                      placeholder="Type message" @keyup.enter="sendMessage" rows="1" autofocus></textarea>
                    <span @click="sendMessage" class="material-symbols-outlined send-btn">send</span>
                  </div>
  ...
</template>
```

```css
.form-input {
  ...
  resize: none;
}
```

- 기능
  - 사용자가 입력한 문자 그대로 입력폼에 담아 보내기
  - 띄어쓰기, 줄바꿈 그대로 적용
- 포인트
  - `<textarea>` : `input`보다 긴 텍스트를 입력받고 싶을 때 사용
    - `rows` : 보이는 영역의 라인 수
    - `autofocus` : 페이지가 로드될 때 자동으로 포커스가 텍스트 입력 영역으로 이동함
    - `resize`
      - `<textarea>`의 박스크기를 임의로 수정할 수 있음
      - 막기 위해선 `style`에 `none`으로 지정해야 함

#### 띄어쓰기, 줄바꿈 그대로 보여주기📄

```vue
<template>
                        <div class="message-section">
                          <pre class="your-message chat-message">{{ msg.msg }}</pre>
                          <p class="message-time">{{ msg.datetime.substr(5, 11) }}</p>
                        </div>
</template>
```

```css
.chat-message {
  font-family: 'SUIT';
  white-space: pre-wrap;
}
```

- 기능
  - 데이터로 넘겨받은 텍스트 그대로를 보여주는 것
- 포인트
  - `<pre>` : 작성한 내용 그대로를 표현
    - CSS가 날아가므로 새로 지정해주어야 함	
  - `white-space` : 요소의 공백을 어떻게 처리할 것인지 정의함
    - `normal` : 연속된 공백과 줄 바꿈을 메꿔 하나의 공백으로 표시
    - `nowrap` : 공백을 채우지만 가로로 긴 줄을 줄 바꿈하지 않고 표시함
    - `pre` : 연속된 공백을 그대로 표시
    - `pre-wrap` : 연속된 공백을 그대로 표시  & 행의 줄바꿈은 행의 박스를 채우기 위해 필요한 경우 실행
    - `pre-line` : 연속된 공백을 메꿔 하나의 공백으로 표시 & 행의 줄바꿈은 행의 박스를 채우기 위해 필요한 경우 실행
---

### 2. BE

#### Django 한국어, 한국시간 설정

문제상황
- 모델 설계 중 created_at = models.DateTimeField(auto_now_add=True)를 작성하면 한국 시간이 아니라 국제 표준 시간으로 저장됨
- 시간을 저장할 때 한국 시간으로 저장하고자 함

해결방안
- 기본 설정
```
# project/settings.py

LANGUAGE_CODE = 'en-us'
TIME_ZONE = 'UTC'
USE_I18N = True
USE_L10N = True
USE_TZ = True
```

- 한국어, 한국시간 설정
    - 반드시 USE_TZ = False 설정
```
# project/settings.py

LANGUAGE_CODE = 'ko-kr'
TIME_ZONE = 'Asia/Seoul'
USE_I18N = True
USE_L10N = True
USE_TZ = False
```

auto_now_add와 auto_now
- auto_now_add
    - 데이터 최초 저장 시 현재 날짜와 시간을 저장
    - 생성 당시의 날짜와 시간
- auto_now
    - 데이터가 저장될 때마다 현재 날짜와 시간을 저장
    - 수정 당시의 날짜와 시간

#### Django allauth signup
allauth를 통한 signup시 오류 발생
- User model
```
# accounts/models.py
from django.contrib.auth.models import AbstractUser
from django.db import models

class User(AbstractUser):
    pass
```
    - settings.py에 AUTH_USER_MODEL = 'accounts.User' 등록 완료한 상태
- signup에 요청을 보낼 때 body에 필수값인 username, password1, password2를 기본으로 작성하고, 선택값인 email까지 작성하면 예상하지 못한 오류 발생
- 발생한 오류
```
ConnectionRefusedError: [WinError 10061] 대상 컴퓨터에서 연결을 거부했으므로 연결하지 못했습니다
```
    - 예상 결과는 로그인 상태로 전환되어 토큰 리턴, DB에 email을 포함하여 데이터 저장
    - 실제 결과는 비로그인 상태로 토큰 발행 X, DB에 email을 포함하여 데이터 저장, 500 상태와 함께 에러 발생

해결방안
- 참고문서
    - [공식문서](https://django-allauth.readthedocs.io/en/latest/configuration.html)
    - [깃허브](https://github.com/pennersr/django-allauth/blob/master/allauth/account/app_settings.py#L7)

- 코드 (settings.py)
```
ACCOUNT_EMAIL_VERIFICATION = 'none'
```
또는
```
# 개발단계에서 사용
EMAIL_BACKEND = 'django.core.mail.backends.console.EmailBackend'
````

- ACCOUNT_EMAIL_VERIFICATION = 'none'
```
ACCOUNT_EMAIL_VERIFICATION (=”optional”)
Determines the e-mail verification method during signup – choose one of "mandatory", "optional", or "none".

Setting this to “mandatory” requires ACCOUNT_EMAIL_REQUIRED to be True

When set to “mandatory” the user is blocked from logging in until the email address is verified. Choose “optional” or “none” to allow logins with an unverified e-mail address. In case of “optional”, the e-mail verification mail is still sent, whereas in case of “none” no e-mail verification mails are sent.
```
    - email verification이 기본 설정으로 'optional'이 적용되었기 때문에 회원가입시 email을 작성하면 인증 이메일이 보내짐
    - 'none'으로 설정을 변경하면 메일이 보내지지 않고 바로 회원가입이 완료되며 로그인 상태로 전환됨
- EMAIL_BACKEND = 'django.core.mail.backends.console.EmailBackend'
    - 실제로 회원가입 확인 인증 메일을 보내는 대신에, 터미널창에 이메일 내용을 보여줌
    - 터미널에 이메일 내용을 보여주기 때문에 개발단계에서 사용
- 두 가지 방법 모두 오류 발생 X

#### Django allauth signup
allauth를 통한 signup시 오류 발생
- 자동으로 닉네임을 중복없이 생성하는 기능에 오류 발생
- 상황
    - DB를 새로 만들기 위해 기존의 스키마를 삭제하고 새로 생성
    - 기존의 migrations들을 모두 삭제하고 새롭게 생성하고자 함
    - python manage.py makemigrations를 실행하려 했으나 오류 발생
```
django.db.utils.ProgrammingError: (1146, "Table '<db이름>.accounts_user' doesn't exist")
```

- 기존 model
```
# accounts/models.py
from django.contrib.auth.models import AbstractUser
from django.db import models

class User(AbstractUser):
    
    phone_number = models.CharField(max_length=11, blank=True)
    addr = models.CharField(max_length=100, blank=True)
    zip_code = models.CharField(max_length=5, blank=True)
    nickname = models.CharField(max_length=15, unique=True)
```
- 기존 serializer
```
# accounts/serializers.py
from rest_framework import serializers
from dj_rest_auth.registration.serializers import RegisterSerializer
import random
from django.contrib.auth import get_user_model

User = get_user_model()

class CustomRegisterSerializer(RegisterSerializer):

    full_nickname = ''

    while full_nickname == '':
        nick1_lst = ['촉촉한', '싱싱한', '늘푸른', '건강한', '새내기']
        nick2_lst = ['참나무', '소나무', '올리브나무', '야자나무', '귤나무']
        nick1 = random.choice(nick1_lst)
        nick2 = random.choice(nick2_lst)
        nick3 = str(random.randint(0, 9999))
    
        full_nickname = nick1+nick2+nick3

        if User.objects.filter(nickname=full_nickname).exists():
            full_nickname = ''

    nickname = serializers.CharField(max_length=15, default=full_nickname)
    email = serializers.EmailField()

    def get_cleaned_data(self):
        data = super().get_cleaned_data()
        data['nickname'] = self._validated_data.get('nickname', '')
        data['email'] = self._validated_data.get('email', '')
        return data
```
- 오류 발생 원인
    - 닉네임 default 값을 줄 때 if User.objects.filter(nickname=full_nickname).exists(): 코드를 통해 이미 존재하는 닉네임인지 확인하려 함

→ 아직 존재하지 않는 User 테이블에서 찾아보라는 지시였던 것

    - 이미 db와 테이블이 생성된 뒤에는 동작하였으나 생성되기 전에는 오류 발생

해결방안
- 수정한 serializer
```
from rest_framework import serializers
from dj_rest_auth.registration.serializers import RegisterSerializer
import random
from django.contrib.auth import get_user_model

User = get_user_model()

class CustomRegisterSerializer(RegisterSerializer):

    email = serializers.EmailField()

    def get_cleaned_data(self):
        full_nickname = ''

        while full_nickname == '':
            nick1_lst = ['촉촉한', '싱싱한', '늘푸른', '건강한', '새내기']
            nick2_lst = ['참나무', '소나무', '올리브나무', '야자나무', '귤나무']
            nick1 = random.choice(nick1_lst)
            nick2 = random.choice(nick2_lst)
            nick3 = str(random.randint(0, 9999))
        
            full_nickname = nick1+nick2+nick3
            if User.objects.filter(nickname=full_nickname).exists():
                full_nickname = ''

        data = super().get_cleaned_data()
        data['nickname'] = self._validated_data.get('nickname', full_nickname)
        data['email'] = self._validated_data.get('email', '')
        return data
```
- nickname default 값을 data['nickname'] = self._validated_data.get('nickname', full_nickname)에서 설정해야함
- get_cleaned_data함수 밖 클래스 내에서 User 모델에 접근시 User 테이블이 생성되기 전이기 때문에 인식 불가능
- 기존의 nickname = serializers.CharField(max_length=15, default=full_nickname) 코드에서 default= 인자는 오류 발생

#### Django Redis
Django 설정
- django-redis 설치
```
$ pip install django-redis
```
- 설정
```
# <프로젝트>/settings.py

CACHES = {
    "default": {
        "BACKEND": "django_redis.cache.RedisCache",
        "LOCATION": "redis://127.0.0.1:6379/1",  # 1번 DB 사용
        "OPTIONS": {
            "CLIENT_CLASS": "django_redis.client.DefaultClient",
        }
    }
}
```
- 테스트 함수 작성
```
# views.py

from django.core.cache import cache
from rest_framework.response import Response

def test(request):
    cache.set('key', 'value', timeout=30)  # 지속시간 30초. 30초 뒤 삭제됨
    result = cache.get('key')
    return Response({'result': result})
```
- 주소 설정
```
# urls.py

urlpatterns = [
    path('test/', views.test),
]
```

문제상황 및 원인
- 위 설정까지만 하고 될 것이라 생각했지만 오류 발생
```
redis.exceptions.ConnectionError: Error 10061 connecting to 127.0.0.1:6379. 대상 컴퓨터 
에서 연결을 거부했으므로 연결하지 못했습니다.
[14/Aug/2022 01:41:39] "GET /api/v1/test/ HTTP/1.1" 500 119551  
```
- redis를 설치해야 django-redis 사용 가능

Redis 설치 (해결방안)
Window 설치
- Github에서 파일 다운 & 설치
```
https://github.com/microsoftarchive/redis/releases
```
- 3.0.504 (Latest)
- Redis-x64-3.0.504.msi 다운
- 파일 실행하여 설치
- 정상적으로 설치되었는지 확인
- redis-cli 로 실행, select <number>로 DB 선택 가능
```
# cmd

C:\Users\LJS>netstat -an|findstr 6379
  TCP    0.0.0.0:6379           0.0.0.0:0              LISTENING
  TCP    [::]:6379              [::]:0                 LISTENING
  
C:\Users\LJS>redis-cli  # redis 실행
127.0.0.1:6379> PING
PONG  # 정상 설치
```

Linux 설치 (Ubuntu)
- 설치에 앞서 apt-get 업데이트, 업그레이드
```
$ sudo apt-get update
$ sudo apt-get upgrade
```
- redis-server 설치
```
$ sudo apt-get install redis-server
```
- 버전 확인
```
$ redis-server --version

Redis server v=5.0.7 sha=00000000:0 malloc=jemalloc-5.2.1 bits=64 build=66bd629f924ac924
```
- 메모리 설정에 앞서 서버의 메모리 확인
```
$ vmstat

procs -----------memory---------- ---swap-- -----io---- -system-- ------cpu-----
 r  b   swpd   free   buff  cache   si   so    bi    bo   in   cs us sy id wa st
 1  0      0 9256552 214776 6114212    0    0     0     9    6    2  0  0 100  0  0
```
- maxmemory 설정을 위해 redis.conf 파일 편집
```
$ sudo vim /etc/redis/redis.conf
```
- 수정해야하는 부분
    - maxmemory: redis가 최대로 사용할 메모리
    - maxmemory-policy: redis가 최대로 사용할 메모리를 초과했을 때 데이터를 삭제하는 방식 정의
- 일반모드에서 /<검색할 단어>를 입력하고 엔터
    - 아래 방향으로 검색 (위→아래)
    ?<검색할 단어>: 위 방향으로 검색 (아래→위)
    - n을 누르면 다음 검색 결과로 이동
    shift + n: 이전 검색 결과로 이동
- maxmemory와 maxmemory-policy의 주석 부분을 편집
    - i를 누르면 입력 가능
    ```
    maxmemory 1g  # 최대 메모리 사용량 1G	
    maxmemory-policy allkeys-lru  # 초과시 오래된 데이터를 지워서 메모리 확보
    ```
    - 편집이 끝나면 Esc + :wq
- Redis 재시작
```
$ sudo systemctl restart redis-server.service
```

### 3. HW

#### LCD

1. 화면 해상도
   
    - 제공 받은 LCD가 잘 안쓰이는 해상도였다
    - **해결방안** : 직접 픽셀 수정해가면서 알아냈다. 

<br>

2. 작업표시줄

    - 프로그램이 구동될 때 보이는 작업표시줄이 신경쓰였다.
    - **해결방안** : 
        1. 마우스가 필요하다.
        2. 마우스로 작업표시줄에서 우클릭후 마우스 오버시에만 활성화 할 수 있다. 

#### 라즈베리파이
1. DHT11 : Adafruit_DHT
        
    - adafruit 측에서 더 이상 새로운 업데이트를 내놓지 않고 있다.
    - 즉, 공식적으로 라즈베리파이 4b를 위한 온습도 센서의 라이브러리가 없다.
    - **해결 방안** : 
        1. 기존 것을 쓰되 깃허브에서 직접 다운받는다.
        2. 다운 후 폴더에서 setup 전 직접 파일 수정을 하여 라즈베리파이 4b 모델을 추가해준다 그 이후 setup.py 실행

<br>  

2. NeoPixel LED
   
    - sudo로만 작동 가능하다.
    - 즉, 직접 코드 안에서 쓰는 것이 불가능하다.
    - **해결방안** : 외부 파일을 만든 후 안에서 쓰는 방법 채택하였다. 

<br>

3. subprocess
    - os.system 대신에 쓰인다.
    - subprocess.run("명령어") 구조이지만 에러가 난다. 쉘에서 쓰일 것인데 안된다고 한다.
    - **해결방안** : 
    ```python
        subprocess.run("명령어" , shell = true)
    ```
    로 작성해야 제대로 돌아간다. 

### 4. server

#### Django install 오류

<div markdown="1">

- pip 업데이트 확인 필요
- wheel 이나 다른것 설치가 필요하다.
```console
    pip install wheel
```
- settings.py에서 데이터베이스 명시가 필요하긴 하다.

- mysql-client 오류 시 해당 설치 후 다시 설치하면 잘된다.
```console
    sudo apt-get install python3-dev default-libmysqlclient-dev build-essential
```

</div>

---

<br>
<br>
<br>

#### UWSGI
모듈이 존재하지 않아요!
<div markdown="1">

- 몇시간을 고민하도록 한 문제이다.
- uwsgi를 실행했는데 모듈이 없는 문제이다.
```
    module = back.wsgi:application
```
- 이 부분에서 manage.py 가 있는 경로가 아닌 다른 파일에 wsgi.py가 있다 그 폴더 명을 써줘야한다.

</div>

#### 400 Bad Request
- ALLOWED_HOSTS
```
# 로컬호스트에서만 접속 허용
ALLOWED_HOSTS = []
ALLOWED_HOSTS = ['localhost', '127.0.0.1', '[::1]']

# 모든 곳에서의 접속 허용
ALLOWED_HOSTS = ['*']

# 특정 호스트에서 접속 허용
ALLOWED_HOSTS = ['서비스를 제공할 도메인 주소']
```

#### 500 Internal Server Error
(1) uwsgi 경로 설정 오류
- 프론트에서 백엔드로 보내는 요청 주소 설정
```
# 기존 설정값
const HOST = 'http://127.0.0.1:8000/api/v1/'

# 배포시 설정값
# 포트번호 넣지 않기
const HOST = 'http://<배포주소>/api/v1/'
```

- django uwsgi ini 설정
    - 경로 정확히 작성
```
[uwsgi]
# django 프로젝트 폴더 경로
chdir = /home/ubuntu/back/
# wsgi가 존재하는 경로
module = <프로젝트이름>.wsgi:application
# 가상환경 경로
home = /home/ubuntu/venv/
...

```

- 코드 수정 후 reload, restart
```
$ sudo systemctl restart uwsgi
$ sudo systemctl restart nginx
```

(2) 이미지 파일 최대 크기 설정 오류
- 오류 메시지
```
TypeError: cannot pickle '_io.bufferedrandom' object
```

- 오류 상황
    - POST 요청으로 새로 사진을 업로드할 때는 nginx에 설정한 최대 크기까지 가능
    - PUT 요청으로 사진을 수정할 때 nginx에 설정한 최대 크기가 아닌, django의 이미지필드 기본 최대 크기인 2.5MB까지만 가능

- 오류 해결
```
# <프로젝트>/settings.py
# 30MB까지 업로드 가능하도록 설정
# 프론트에서 파일 크기가 30MB가 넘으면 경고창 띄우기 추가

FILE_UPLOAD_MAX_MEMORY_SIZE = 30 * 1024 * 1024  
```

#### 도메인 연결 오류
- 도메인 구매 후, DNS 연결
    - 레코드 추가
    - 타입: A, 호스트: @, 값: IP주소 xxx.xxx.xxx.xxx, TTL: 600

- IP 찾는 방법
    - CMD 실행
    - tracert <주소>
        - 주소 첫 부분에 http:// 입력하지 않음, 마지막 부분에 / 입력하지 않음
        - 예) tracert naver.com

- nginx 설정
```
# 경로
$ /etc/nginx/site-available/dafault
```
```
# defalut
server {
        listen 80 default_server;
        listen [::]:80 default_server;
		server_name <도메인주소> <www.도메인주소>
		...
}

# 예시
server {
        listen 80 default_server;
        listen [::]:80 default_server;
		server_name abc.com www.abc.com
		...
}
```

- 재시작
```
$ sudo systemctl daemon-reload
$ sudo systemctl restart uwsgi
$ sudo systemctl restart nginx
```

### 5. 기타
#### 성능 검사 dev tool `Lighthouse`🎠

- performance 높이기 위해 필요한 것

  - 요청 수 줄이기
  - 이미지 최적화
  - CDN 사용
  - 모바일 코드 먼저 짜기
  - CSS, JS, HTML 파일 줄이기
  - 비동기 처리
  - 플러그인 줄이기
  - 웹사이트 캐시 사용하기

  ...

---

#### vue cli 사용시 font는 app.vue에 걸어서 사용하는 것 보다 각 .vue파일에 적용하는 것이 성능적으로 더 좋음🎡

app.vue => 31%

HomeView.vue => 58%

---

#### performance 고려 사항 우선순위🎠

1. 이미지, 동영상 등 파일 크기 조절
2. CSR 보다는 SSR로 페이지 구성하기
3. 사용하지 않는 데이터는 사용할 때 받아오기
   - props 등 데이터 간소화
   - components 이용시 적절한 배분 고려 필요

4. 웹팩 공부해서 적용하기

---
#### 등록버튼은 우측하단이 국룰!🎢

#### 검색 및 필터 활용시 🎪

- 로직 명확하게(오류 없이)
- 검색 및 필터는 한곳에 모아서 모듈화(유저는 자기가 어떤 필터를 걸었는지 기억하지 않는다)
- reset 버튼 추가 고려!

  - 변경 전

    ```vue
    <template>
      <!-- 서치배너 -->
      <div class="search row">
        
        <div class="search-box col-sm-8 col-md-4 col-12 d-flex justify-content-center">
          <input class="search-input pl-3" type="text" v-model="info.plantname" placeholder="식물명을 입력해주세요" @keyup.enter="beforeSearch()">        
          <button class="search-btn" type="submit" @click="beforeSearch()">
            <span class="material-symbols-outlined d-flex align-items-center justify-content-center">search</span>
          </button>
        </div>
        
      </div>
      <div class="select-box row mt-5 mb-3">
        
        <div class="select row d-flex justify-content-between col-sm-8 col-12">
          <div class="create">
            <!-- 생성버튼 -->
            <router-link :to="{ name : 'leaf82New' }" v-if="isLoggedIn">
              <button class="create-btn">
                등록
              </button>
            </router-link>
          </div>
          <div class="filter d-flex justify-content-center">
            <!-- 검색버튼 -->
            <select class="sido mr-1" @change="beforeFetchSigungu($event)">
              <option value="null">지역을 선택해주세요</option>
              <option v-for="loc in sido" :key="loc.pk" :value="loc.sido">{{ loc.sido }}</option>
            </select>
            <!-- 시도가 선택되면 활성화 -->
            <select class="sigungu" @change="beforeFetchSearch($event)" v-if="this.info.sido">
              <option selected>동네를 선택해주세요</option>
              <option v-for="loc in sigungu" :key="loc.pk" :value="loc.sigungu">{{ loc.sigungu }}</option>
            </select>
            <select class="sigungu" v-if="!this.info.sido" disabled>
              <option selected>동네를 선택해주세요</option>
            </select>
          </div>
        </div>
        
      </div>
    ...
    </template>
    ```

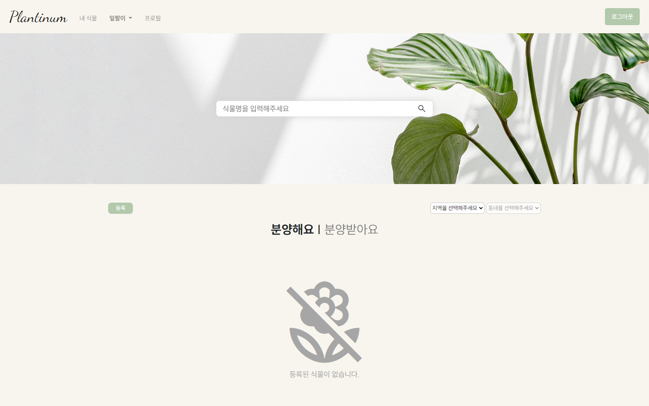
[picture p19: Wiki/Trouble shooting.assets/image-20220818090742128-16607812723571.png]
    
  - 변경 후

    ```vue
    <template>
      <!-- 서치 배너 -->
      <div class="search row">
        
        <div class="search-box col-sm-8 col-md-4 col-12">
          <div class="d-flex justify-content-center">
            <input class="search-input pl-3" type="text" v-model="info.plantname" placeholder="식물명을 입력해주세요" @keyup.enter="beforeSearch()">        
            <button class="search-btn" type="submit" @click="beforeSearch()">
              <span class="material-symbols-outlined d-flex align-items-center justify-content-center">search</span>
            </button>
          </div>
          <!-- 필터링 파트 -->
          <div class="d-flex justify-content-center">
            <select class="sido pl-3 active" @change="beforeFetchSigungu($event)">
              <option value="null">지역을 선택해주세요</option>
              <option v-for="loc in sido" :key="loc.pk" :value="loc.sido">{{ loc.sido }}</option>
            </select>
            <!-- 시도가 선택되면 활성화 -->
            <select class="sigungu pl-3 active" @change="beforeFetchSearch($event)" v-if="this.info.sido">
              <option selected>동네를 선택해주세요</option>
              <option v-for="loc in sigungu" :key="loc.pk" :value="loc.sigungu">{{ loc.sigungu }}</option>
            </select>
            <select class="sigungu pl-3" v-if="!this.info.sido" disabled>
              <option selected>동네를 선택해주세요</option>
            </select>
            <!-- 리셋버튼 -->
            <button class="reset d-flex align-items-center justify-content-center" @click="reset">
              <span class="material-symbols-outlined">autorenew</span>
            </button>
          </div>
        </div>
        
      </div>
    ...
    </template>
    ```

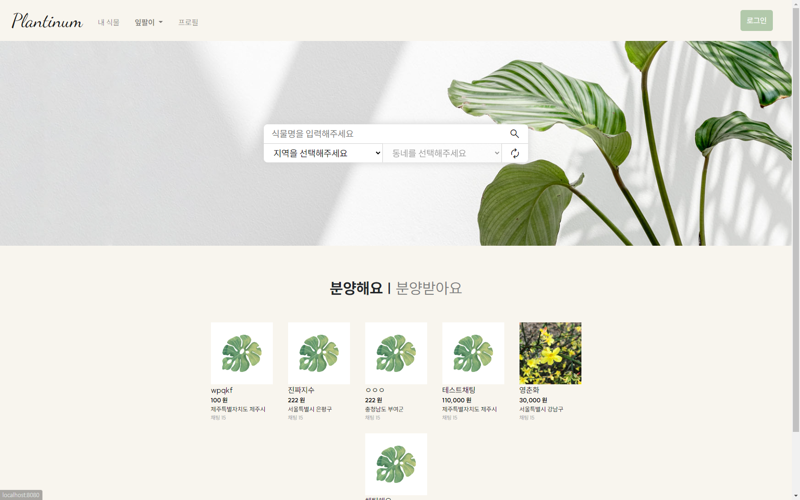
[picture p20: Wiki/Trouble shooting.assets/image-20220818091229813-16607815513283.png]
    

---

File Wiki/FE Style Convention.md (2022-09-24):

### 🌼\<FE Style Convention>🌼

---

#### font

- suit 폰트
  - https://noonnu.cc/font_page/840

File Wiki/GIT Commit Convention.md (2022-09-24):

### 🥑\<GIT Commit Convention>🥑

---
#### Message✉

- 개괄
  - 모든 커밋 메시지는 `영어`로 작성

- 구조

  - 기본적으로 커밋 메시지는 아래와 같이 제목/본문/꼬리말로 구성

  ```
  type : subject
  
  body
  
  footer
  ```

- 커밋 타입(Type)
  - feat : 새로운 기능 추가
  - fix : 버그 수정
  - docs: 문서 내용 변경 
  - style: 포맷,  세미콜론 수정 등 코드가 아닌 스타일에 관련된 수정
  - refactor: 리팩토링 코드
  - test: 테스트 코드 추가 및 리팩토링 테스트 등
  - chore: build task 수정, 프로젝트 매니저 설정 수정 등
  - 타입은 소문자로 시작
  - 타입은 항상 대괄호 안에 파트를 입력하여 시작
  - 예시
    - "fix" --> ''[HW] fix'

- 제목(Subject)
  - 제목은 50자 이내로, 대문자로 시작하며 모두 소문자로 작성 
  - 파일명의 경우에는 대소문자 고려하지 않음
  - 마침표로 끝나지 않도록 함
  - 과거시제를 사용하지 않고 명령어로 작성
  - 예시
    - "feat : Logined" --> "feat : Login"
    - "feat : Added" --> "feat : Add"

- 본문(Body)
  - 선택사항
  - 부연 설명 필요 시 작성
  - 100자 미만 작성 권장

- 꼬리말(Footer)
  - 선택사항
  - issue tracker id를 작성할 때 사용
  - JIRA Code 작성 시 사용

- 예시

  ```
  [FE] feat : Login DEsign.py
  
  한글한글한글
  - 영어말고 한글로
  - 선택사항
  
  Issue tracker id : 486
  JIRA Code : #123
  ```

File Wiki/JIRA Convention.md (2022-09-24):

### 🌻\<JIRA Convention>🌻

---

- **Epic**
  - 큰 파트 생성
  - HW / WEB / 기획 / DB / 배포 / TEST

- **Story**
  - 회원에게 제공되는 서비스/기능 목록
  - 네이밍 규칙 - 명사로 마무리
    - 예) 물주기, 빛조절 / 회원가입, 로그인, 게시물 작성
    - 스토리에는 이모지 추가
  - Story Point는 0

- **Task**
  - 해당 스토리에 관련한 상세 구현 사항
  - 네이밍 규칙
    - 파트는 대괄호에 작성
    - 명사로 마무리
    - 예) [BE] 유저 모델 작성
  - Task의 Story point는 4 이하로 작성
  - SubTask 작성 대신 확인 가능한 Task로 세분화하여 작성

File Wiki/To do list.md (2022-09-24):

## FE
**Vuex**
- [x] local storage & vuex 활용 방법 수정

**Home**
- [x] Homeview 배경 이미지 잘림
- [x] Hoewview 닉네임 강조
- [x] 메인 페이지 등록 버튼 sticky로 수정
- [x] params에서 username 넘기는 방법 찾기
- [x] 화면 크기 줄일 때 헤드라인이 사진이랑 겹쳐서 안보임
- [x] fetchProfile

**Myplant**
- [x] 등록 시 검색 기능 추가
- [x] 이미지 input
- [x] Homeview에서 버튼으로 페이지에 접근 시 navbar 안보임
- [x] router-link 연결
- [x] vuex-persistedstate 선택적 적용
- [x] 식물 리스트 카드 배경 조절
- [x] 리스트 정렬 수정
- [x] 로그인 후 목록 안뜸

**Myplant Detail**
- [x] 모달창 띄우기
- [x] 해당 식물 주인만 otp 버튼 띄우기
- [x] otp 타이머 progress bar
- [x] otp 타이머 딜레이 수정
- [x] 내 식물 정보 수정
- [x] 뒤로가기 버튼

**NewMyplant**
- [x] 등록 폼 CSS
- [x] 식물 목록에 원하는 식물 없을 때 직접 입력할 창 만들기

**NavBar**
- [x] 현재 있는 카테고리 탭 강조

**Login**
- [x] 입력값 폰트 색 조정
- [x] authError 처리
- [x] 로그인/회원가입 화살표 수정

**Logout**
- [x] 로그아웃 시 router push 수정(myplant에서 alert창을 enter쳐서 껐을 때...)

**favicon**
- [x] 아이콘 변경하기

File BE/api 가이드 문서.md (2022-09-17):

# 0. 목차

### 목차
[TOC]

### 시작하기

```python
python manage.py migrate
python manage.py loaddata plants.json juso.json user.json myplant.json leaf82.json
```

```
# 생성되어있는 유저
plantinum_test
plantinum_test2
```

# 1. 관리자 페이지

```
http://127.0.0.1:8000/admin/
```

# 2. 유저 관련 페이지

### 회원가입

- 회원가입시 자동으로 로그인 상태로 변경됨
- 토큰 생성 및 리턴
- POST

- URL

```
http://127.0.0.1:8000/api/v1/accounts/signup/
```

- Body

| Key | Type | Description | Mandatory | Example |
| --- | --- | --- | --- | --- |
| username | String | 유저아이디 | O | plantinum_test |
| email | String | 이메일 | O | plantinum_test@testemail.com |
| password1 | String | 비밀번호 | O | xptmxmdlqslek |
| password2 | String | 비밀번호 재입력 | O | xptmxmdlqslek |
| phone_number | String | 폰넘버 | | |
| addr | String | 주소 | | |
| zip_code | String | 우편번호 | | |
| nickname | String | 닉네임, default값 존재 | |  |

- Response

```
{
    "key": "3e2df1dc87c527fc5722b907f48e352dd3c046ee"
}
```

### 로그인

- 토큰 리턴
- POST
- URL

```
http://127.0.0.1:8000/api/v1/accounts/login/
```

- Body

| Key | Type | Description | Mandatory | Example |
| --- | --- | --- | --- | --- |
| username | String | 유저아이디  | O | plantinum_test |
| password | String | 비밀번호 | O | xptmxmdlqslek  |

- Response

```
{
    "key": "57f72c606b9cbd10d2ecf5df6eda4b90f2213198"
}
```

### 로그아웃

- 로그인 사용자 - 토큰 사용

- POST

- URL

```
http://127.0.0.1:8000/api/v1/accounts/logout/
```

- Headers

| Key | Type | Description | Mandatory | Example |
| --- | --- | --- | --- | --- |
| Authorization | String | Token {token} | O | Token 3e2df1dc87c527fc5722b907f48e352dd3c046ee |

- Response

```
{
    "detail": "로그아웃되었습니다."
}
```

### 비밀번호 변경

- 로그인 사용자 - 토큰 사용
- POST
- URL

```
http://127.0.0.1:8000/api/v1/accounts/password/change/
```

- Body

| Key | Type | Description | Mandatory | Example |
| --- | --- | --- | --- | --- |
| new_password1 | String | | O | new_xptmxmdlqslek |
| new_password1 | String | | O | new_xptmxmdlqslek |

- Response

```
{
    "detail": "새로운 패스워드가 저장되었습니다."
}
```

### 마이페이지(프로필)

- 잎팔이 글 전체 조회 추가예정
- 나의 프로필만 확인 가능, 다른 사람의 프로필 확인 X
- 로그인 사용자 - 토큰 사용
- GET
- URL

```
http://127.0.0.1:8000/api/v1/accounts/profile/
```

- Response

```
{
    "pk": 1,
    "nickname": "싱싱한소나무3309",
    "email": "plantinum_test@testemail.com",
    "phone_number": "",
    "addr": "",
    "zip_code": "",
    "myplant_count": 4,
    "dday": 1,
    "photo": "https://plantinum.s3.ap-northeast-2.amazonaws.com/static/profile.jpg",
    "leaf82_set": [
        {
            "pk": 1,
            "photo": "https://plantinum.s3.ap-northeast-2.amazonaws.com/images/leaf82/%EB%AC%B4%EB%8A%AC%EC%82%B0%ED%98%B8%EC%88%98.jpg",
            "posting_addr": 893570,
            "plantname": "무늬산호수"
        },
        {
            "pk": 2,
            "photo": "https://plantinum.s3.ap-northeast-2.amazonaws.com/images/leaf82/%EC%82%B0%EC%84%B8%EB%B2%A0%EB%A6%AC%EC%95%84.jpg",
            "posting_addr": 863022,
            "plantname": "산세베리아"
        },
        {
            "pk": 3,
            "photo": "https://plantinum.s3.ap-northeast-2.amazonaws.com/static/monstera.jpg",
            "posting_addr": 883823,
            "plantname": "치자나무"
        }
    ]
}
```

### 회원정보수정

- 닉네임, 이메일, 핸드폰번호, 주소, 우편번호, 사진만 수정 가능
- 비밀번호 변경은 별개의 요청
- 로그인 사용자 - 토큰 사용
- PUT
- URL

```
http://127.0.0.1:8000/api/v1/accounts/userinformation/
```

- Body

| Key | Type | Description | Mandatory | Example |
| --- | --- | --- | --- | --- |
| nickname | String | | O | 플랜티넘테스트 |
| email | String | | O | plantinum_test@testemail.com |
| phone_number | String | | O | |
| addr | String | | O | |
| zip_code | String | | O | |
| photo | ImageFile | 새로운 사진/기존사진/기본사진 | O | |

- Response

```
{
    "pk": 1,
    "nickname": "플랜티넘테스트",
    "email": "plantinum_test@testemail.com",
    "phone_number": "",
    "addr": "",
    "zip_code": "",
    "myplant_count": 4,
    "dday": 1,
    "photo": "https://plantinum.s3.ap-northeast-2.amazonaws.com/static/profile.jpg"
}
```

### 회원탈퇴

- 로그인 사용자 - 토큰 사용
- DELETE
- URL

```
http://127.0.0.1:8000/api/v1/accounts/withdraw/
```

- Response

```
{
    "detail": "정상적으로 탈퇴되었습니다."
}
```

# 3. 식물 관련 페이지

### 전체 식물 데이터 조회

- 공공데이터를 활용한 식물 데이터
- 확인용O 배포용X
- GET
- URL

```
http://127.0.0.1:8000/api/v1/plants/
```

- Response

```
[
    {
        "id": 1,
        "myplant_set": [
            {
                "pk": 2,
                "nickname": "가울이"
            }
        ],
        "name": "가울테리아",
        "watercycle_spring": "053003",
        "watercycle_spring_nm": "토양 표면이 말랐을때 충분히 관수함",
        "watercycle_summer": "053003",
        "watercycle_summer_nm": "토양 표면이 말랐을때 충분히 관수함",
        "watercycle_autumn": "053003",
        "watercycle_autumn_nm": "토양 표면이 말랐을때 충분히 관수함",
        "watercycle_winter": "053004",
        "watercycle_winter_nm": "화분 흙 대부분 말랐을때 충분히 관수함",
        "specl_manage_info": ""
    },
    ...
]
```

### 등록용 식물 검색

- 물주기 등록시 사용
- 로그인 사용자 - 토큰 사용
- GET
- URL

```
http://127.0.0.1:8000/api/v1/plants/search/
```

- Response

```
[
    {
        "pk": 1,
        "name": "가울테리아"
    },
    {
        "pk": 2,
        "name": "개운죽"
    },
    ...
    {
        "pk": 207,
        "name": "직접 입력하기"
    }
]
```

### 내식물 전체 조회

- 로그인 사용자 - 토큰 사용
- GET
- URL

```
http://127.0.0.1:8000/api/v1/plants/myplant/{username}/
```

- Request Parameters

| Name | Type | Description | Mandatory | Example |
| --- | --- | --- | --- | --- |
| username | String | 유저id | O | plantinum_test |

- Response

```
[
    {
        "pk": 4,
        "nickname": "개나리아님",
        "photo": "https://plantinum.s3.ap-northeast-2.amazonaws.com/images/myplant/%EC%98%81%EC%B6%98%ED%99%94.jpg",
        "sensing": {
            "moisture_level": 0
        },
        "diary_count": 0
    },
    {
        "pk": 3,
        "nickname": "중간고사",
        "photo": "https://plantinum.s3.ap-northeast-2.amazonaws.com/images/myplant/%EB%B2%9A%EB%82%98%EB%AC%B4.jpg",
        "sensing": {
            "moisture_level": 0
        },
        "diary_count": 0
    },
    {
        "pk": 2,
        "nickname": "가울이",
        "photo": "https://plantinum.s3.ap-northeast-2.amazonaws.com/images/myplant/%EA%B0%80%EC%9A%B8%ED%85%8C%EB%A6%AC%EC%95%84.jpg",
        "sensing": {
            "moisture_level": 0
        },
        "diary_count": 0
    },
    {
        "pk": 1,
        "nickname": "사랑이",
        "photo": "https://plantinum.s3.ap-northeast-2.amazonaws.com/images/myplant/%EB%9F%AC%EB%B8%8C%EC%B2%B4%EC%9D%B8.jpg",
        "sensing": {
            "moisture_level": 0
        },
        "diary_count": 0
    }
]
```

### 내식물 등록

- 물주기 등록 전 반드시 식물 이름 검색이 선행되어야 함
- 로그인 사용자 - 토큰 사용
- POST
- URL

```
http://127.0.0.1:8000/api/v1/plants/myplant/
```

- Body

| Key | Type | Description | Mandatory | Example |
| --- | --- | --- | --- | --- |
| nickname | String | 내식물 등록 대상 식물의 애칭 | O | 깨운이  |
| photo | ImageFile | 내식물 등록 대상 식물의 사진 | 기본값존재 | |
| plantname | String | 사용자가 선택한 식물 이름 | O | 개운죽 |
| tmp | String | 직접 입력하기 선택시 기입 |  |  |

- Response

```
{
    "id": 8,
    "user": {
        "pk": 1,
        "username": "plantinum_test",
        "nickname": "플랜티넘테스트"
    },
    "plant_info": {
        "pk": 2,
        "name": "개운죽",
        "watercycle_spring_nm": "흙을 촉촉하게 유지함(물에 잠기지 않도록 주의)",
        "watercycle_summer_nm": "흙을 촉촉하게 유지함(물에 잠기지 않도록 주의)",
        "watercycle_autumn_nm": "흙을 촉촉하게 유지함(물에 잠기지 않도록 주의)",
        "watercycle_winter_nm": "토양 표면이 말랐을때 충분히 관수함",
        "specl_manage_info": "수경은 물주기가 필요 없으나, 화분은 1-2주에 한번씩 충분히 관수한다."
    },
    "sensing": {
        "id": 8,
        "remaining_water": false,
        "state_led": false,
        "moisture_level": 0,
        "last_watering": "",
        "my_plant": 8
    },
    "diary_set": [],
    "diary_count": 0,
    "nickname": "깨운이",
    "created_at": "2022-08-13T22:41:15.882334",
    "otp_code": null,
    "photo": "https://plantinum.s3.ap-northeast-2.amazonaws.com/static/monstera.jpg",
    "is_connected": false,
    "tmp": ""
}
```

### 내식물 상세페이지

- 물주기 식물 별 상세페이지
- 로그인 사용자 - 토큰 사용
- GET
- URL

```
http://127.0.0.1:8000/api/v1/plants/myplant/{내식물 식물 pk}/detail/
```

- Request Parameters

| Name | Type | Description | Mandatory | Example |
| --- | ---- | --- | --- | --- |
| 내식물 식물 pk | Int  | 내식물 등록한 식물의 pk | O | 8 |

- Response

```
{
    "id": 8,
    "user": {
        "pk": 1,
        "username": "plantinum_test",
        "nickname": "플랜티넘테스트"
    },
    "plant_info": {
        "pk": 2,
        "name": "개운죽",
        "watercycle_spring_nm": "흙을 촉촉하게 유지함(물에 잠기지 않도록 주의)",
        "watercycle_summer_nm": "흙을 촉촉하게 유지함(물에 잠기지 않도록 주의)",
        "watercycle_autumn_nm": "흙을 촉촉하게 유지함(물에 잠기지 않도록 주의)",
        "watercycle_winter_nm": "토양 표면이 말랐을때 충분히 관수함",
        "specl_manage_info": "수경은 물주기가 필요 없으나, 화분은 1-2주에 한번씩 충분히 관수한다."
    },
    "sensing": {
        "id": 8,
        "remaining_water": false,
        "state_led": false,
        "moisture_level": 0,
        "last_watering": "",
        "my_plant": 8
    },
    "diary_set": [],
    "diary_count": 0,
    "nickname": "깨운이",
    "created_at": "2022-08-13T22:41:15.882334",
    "otp_code": null,
    "photo": "https://plantinum.s3.ap-northeast-2.amazonaws.com/static/monstera.jpg",
    "is_connected": false,
    "tmp": ""
}
```

### 내식물 수정

- 닉네임과 사진만 수정 가능

- 로그인 사용자 - 토큰 사용

- PUT
- URL

```
http://127.0.0.1:8000/api/v1/plants/myplant/{내식물 식물 pk}/detail/
```

- Request Parameters

| Name | Type | Description | Mandatory | Example |
| --- | ---- | --- | --- | --- |
| 내식물 식물 pk | Int  | 내식물 등록한 식물의 pk | O | 8 |

- Body

| Key | Type | Description | Mandatory | Example |
| --- | --- | --- | --- | --- |
| nickname | String | 내식물 등록 대상 식물의 애칭 | O | 깨운잉  |
| photo | String | 내식물 등록 대상 식물의 사진<br />새로운 사진/기존사진/기본사진 | O | |

- Response

```
{
    "id": 8,
    "user": {
        "pk": 1,
        "username": "plantinum_test",
        "nickname": "플랜티넘테스트"
    },
    "plant_info": {
        "pk": 2,
        "name": "개운죽",
        "watercycle_spring_nm": "흙을 촉촉하게 유지함(물에 잠기지 않도록 주의)",
        "watercycle_summer_nm": "흙을 촉촉하게 유지함(물에 잠기지 않도록 주의)",
        "watercycle_autumn_nm": "흙을 촉촉하게 유지함(물에 잠기지 않도록 주의)",
        "watercycle_winter_nm": "토양 표면이 말랐을때 충분히 관수함",
        "specl_manage_info": "수경은 물주기가 필요 없으나, 화분은 1-2주에 한번씩 충분히 관수한다."
    },
    "sensing": {
        "id": 8,
        "remaining_water": false,
        "state_led": false,
        "moisture_level": 0,
        "last_watering": "",
        "my_plant": 8
    },
    "diary_set": [],
    "diary_count": 0,
    "nickname": "깨운잉",
    "created_at": "2022-08-13T22:41:15.882334",
    "otp_code": null,
    "photo": "https://plantinum.s3.ap-northeast-2.amazonaws.com/static/monstera.jpg",
    "is_connected": false,
    "tmp": ""
}
```

### 내식물 삭제

- 로그인 사용자 - 토큰 사용

- DELETE
- URL

```
http://127.0.0.1:8000/api/v1/plants/myplant/{내식물 식물 pk}/detail/
```

- Request Parameters

| Name | Type | Description | Mandatory | Example |
| --- | ---- | --- | --- | --- |
| 내식물 식물 pk | Int  | 내식물 등록한 식물의 pk | O | 8 |

- Response

```
{
    "detail": "내식물이 삭제되었습니다."
}
```

### OTP 생성

- 기기와 연결되지 않았고 OTP도 없는 상태에서 OTP 발급
- 연결이 되지 않았는데 OTP가 있다면 현재 있는 값 보여주기
- 20초 후 자동으로 삭제 (NULL)

- 로그인 사용자 - 토큰 사용
- GET

- URL

```
http://127.0.0.1:8000/api/v1/plants/myplant/{내식물 식물 pk}/otp/
```

- Request Parameters

| Name | Type | Description | Mandatory | Example |
| --- | ---- | --- | --- | --- |
| 내식물 식물 pk | Int  | 내식물 등록한 식물의 pk | O | 1 |

- Response

```
# 정상 발급 / otp 존재
{
    "otp_code": "492279"
}
```

```
# 연결된 상태
{
    "detail": "이미 연결되었습니다."
}
```

```
# 존재하지 않는 식물pk
{
    "detail": "찾을 수 없습니다."
}
```

```
# 다른 유저의 식물
{
    "detail": "잘못된 접근입니다."
}
```

### OTP 상태 조회

- 식물의 OTP 상태 조회
- 값이 있으면 해당 값 리턴, 없으면 null 리턴
- 로그인 사용자 - 토큰 사용
- GET
- URL

```
http://127.0.0.1:8000/api/v1/plants/myplant/{내식물 식물 pk}/otp/status/
```

- Request Parameters

| Name | Type | Description | Mandatory | Example |
| --- | ---- | --- | --- | --- |
| 내식물 식물 pk | Int  | 내식물 등록한 식물의 pk | O | 1 |

- Response

```
{
    "otp_code": "636631"
}
```

```
{
    "otp_code": null
}
```

### 연결 해제

- 기기와 연결상태가 True인 경우 연결 해제
- 로그인 사용자 - 토큰 사용

- GET
- URL

```
http://127.0.0.1:8000/api/v1/plants/myplant/{내식물 식물 pk}/disconnect/
```

- Request Parameters

| Name | Type | Description | Mandatory | Example |
| --- | ---- | --- | --- | --- |
| 내식물 식물 pk | Int  | 내식물 등록한 식물의 pk | O | 1 |

- Response

```
# 정상 연결 해제
{
	"is_connected": false
}
```

```
# 연결되지 않은 식물의 연결 해제 시도
{
    "detail": "연결상태를 확인해주세요."
}
```

### 식물 일지

- **수정필요**

- 나의 식물 별 일지 전체 조회, 일지 작성
- 로그인 사용자 - 토큰 사용
- GET, POST
- PUT/DELETE는 추후 추가 예정
- URL

```
http://127.0.0.1:8000/api/v1/plants/myplant/{내식물 식물 pk}/diary/
```

- Request Parameters

| Name | Type | Description | Mandatory | Example |
| --- | ---- | --- | --- | --- |
| 내식물 식물 pk | Int  | | O | 2 |

- Body: POST

| Key | Type | Description | Mandatory | Example |
| --- | --- | --- | --- | --- |
| content | String | | O | 쑥쑥 자라는 가울이 |
| photo | String | **수정 예정** | 임시 X | |
| public_private | Bool | default=False<br />False=공개 | | |

- Response

```
# GET
[
    {
        "id": 1,
        "my_plant": {
            "pk": 2,
            "nickname": "가울이"
        },
        "content": "첫 번째 일지",
        "photo": "",
        "diary_created_at": "2022-07-26T08:15:09.427783Z",
        "public_private": false
    },
    {
        "id": 2,
        "my_plant": {
            "pk": 2,
            "nickname": "가울이"
        },
        "content": "두 번째 일지",
        "photo": "",
        "diary_created_at": "2022-07-26T08:16:08.831901Z",
        "public_private": false
    }
]
```

```
# POST
{
    "id": 3,
    "my_plant": {
        "pk": 2,
        "nickname": "가울이"
    },
    "content": "쑥쑥 자라는 가울이",
    "photo": "",
    "diary_created_at": "2022-07-26T08:32:50.126572Z",
    "public_private": false
}
```

# 4. 잎팔이 관련 페이지
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

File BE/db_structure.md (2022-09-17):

# 커뮤니티 

- 커뮤니티(잠정 중단)
  - 커뮤니티에 집중하기보다 당근에 집중하자?
  - 커뮤니티의 메리트가 없음
  - 당근부터 구현 후, 필요성 대두 시 커뮤니티 추가 
  - 구현새로운 중고거래 페이지 네이밍

- 당근 시스템(네이밍 변경)

  - 카테고리: 팔아요/삽니다/나눔

    ⇒ [팔아요] 화분도 같이 거래할 수 있도록 + 쿠팡 추천같은 느낌

    (ex. 이건 어때요? 처럼 구매 유도)

- DB 설계

  - 메인: 우리 기계를 소개하고 웹으로 할 수 있는 기능을 보여주는 페이지, 개발자 소개 ⇒ 로그인하기/회원가입(웹 화면 위 아래에 모두 위치)

  - 당근: 제목, 내용, 작성자, 가격, 작성자 거주지역(서울 경기 경상도 전라도 강원도… 드랍박스 검색이 가능하도록-필터링하여 게시글 열람, 회원가입시 저장)
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

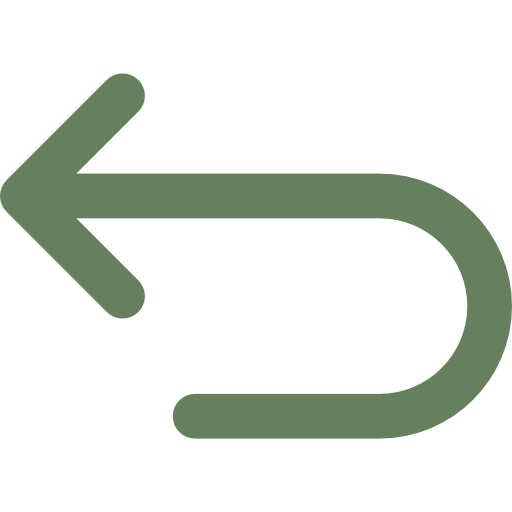
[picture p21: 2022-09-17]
HW/Supool/img/return_green.png

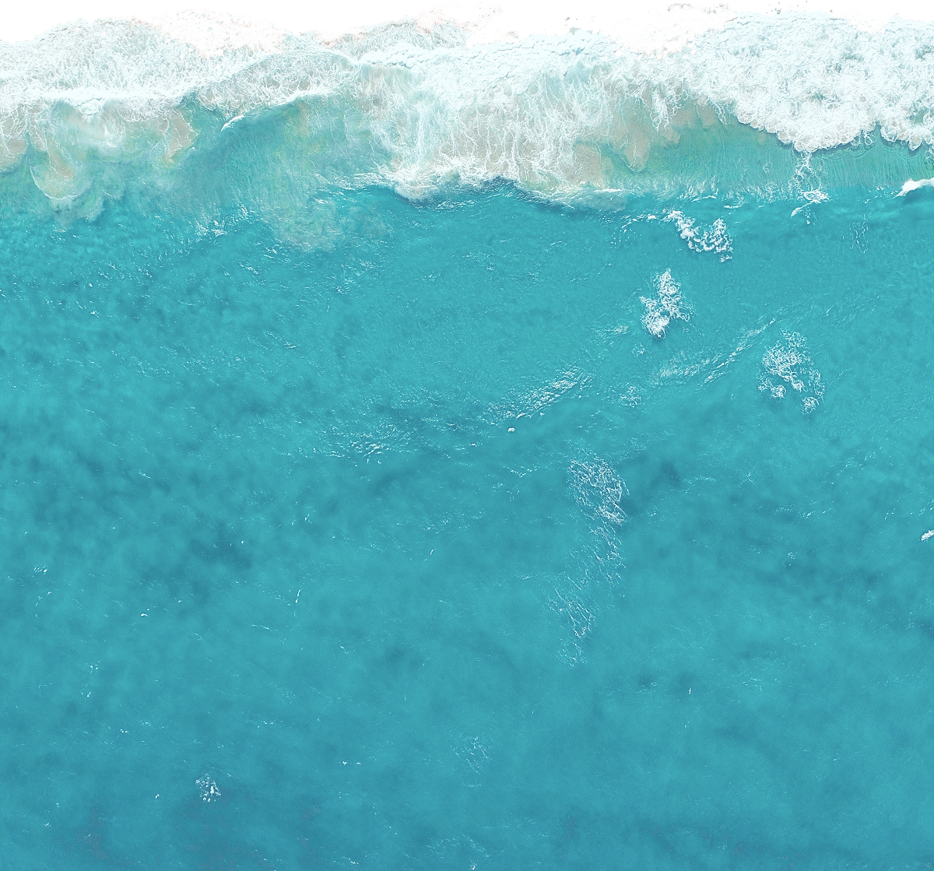
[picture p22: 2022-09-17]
HW/Supool/img/icc_wave.png

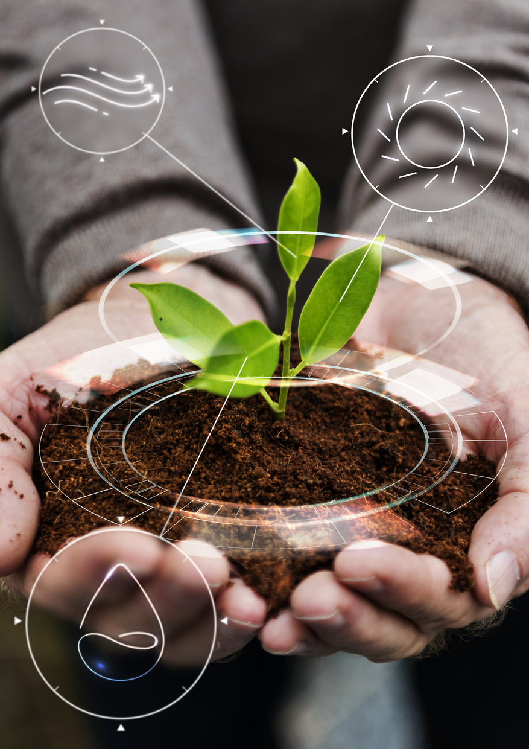
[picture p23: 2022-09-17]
FE/plantinum/src/assets/HomeView/main_pic_2_tablet.jpg

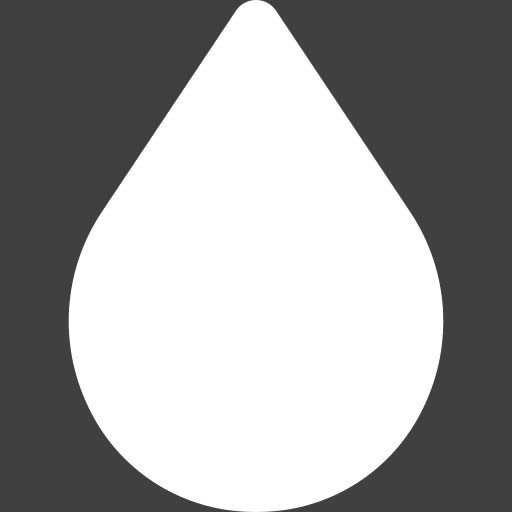
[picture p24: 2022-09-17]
HW/Supool/img/water_white.png

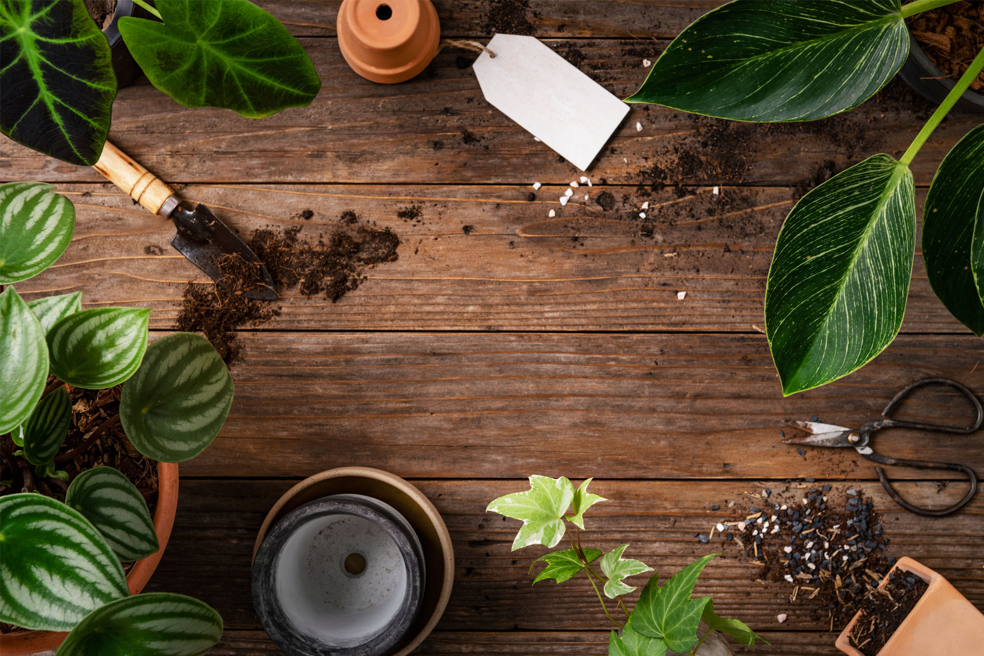
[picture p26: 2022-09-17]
FE/plantinum/src/assets/HomeView/main_pic_2_small.jpg

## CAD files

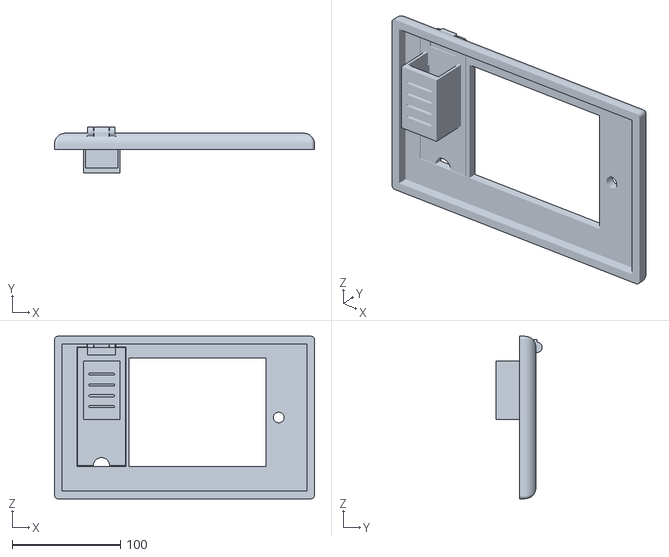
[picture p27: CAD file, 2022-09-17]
HW/stl_files/뚜껑.stl
240.0 x 42.9 x 150.0

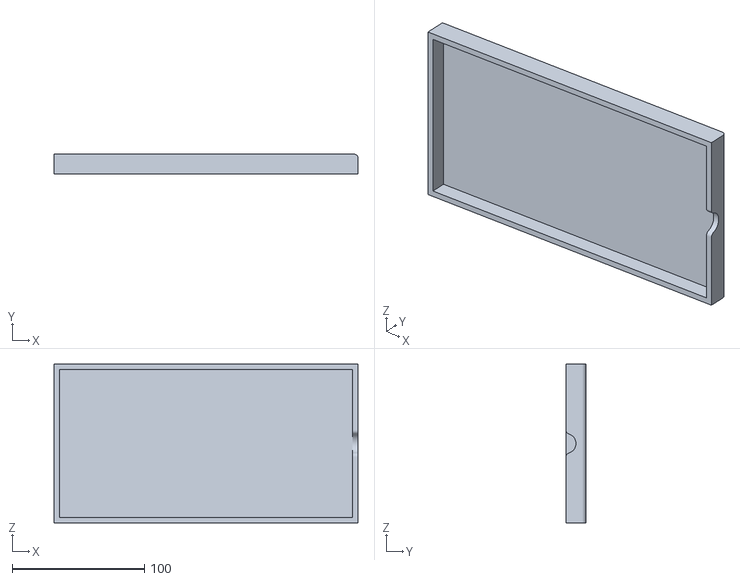
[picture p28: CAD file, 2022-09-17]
HW/stl_files/물받침.stl
230.0 x 15.0 x 120.0

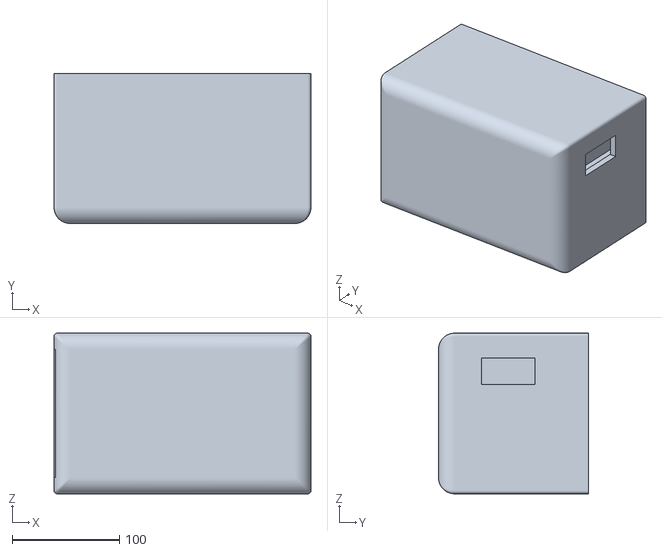
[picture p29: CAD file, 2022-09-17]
HW/stl_files/본체.stl
240.0 x 140.0 x 150.0

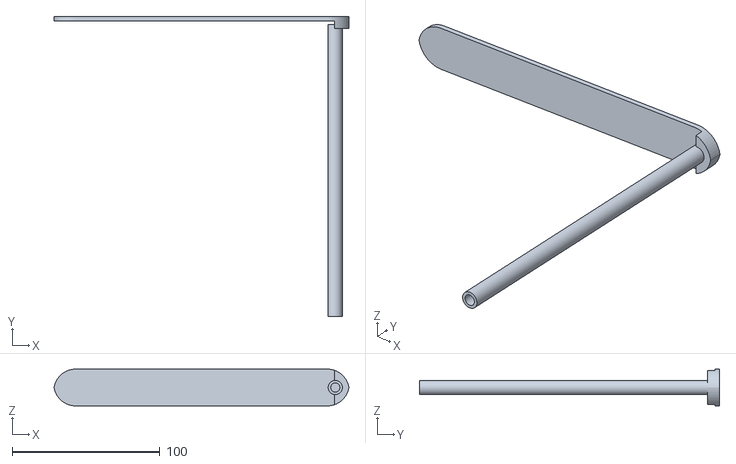
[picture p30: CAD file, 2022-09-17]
HW/stl_files/조명.stl
199.6 x 203.0 x 25.0

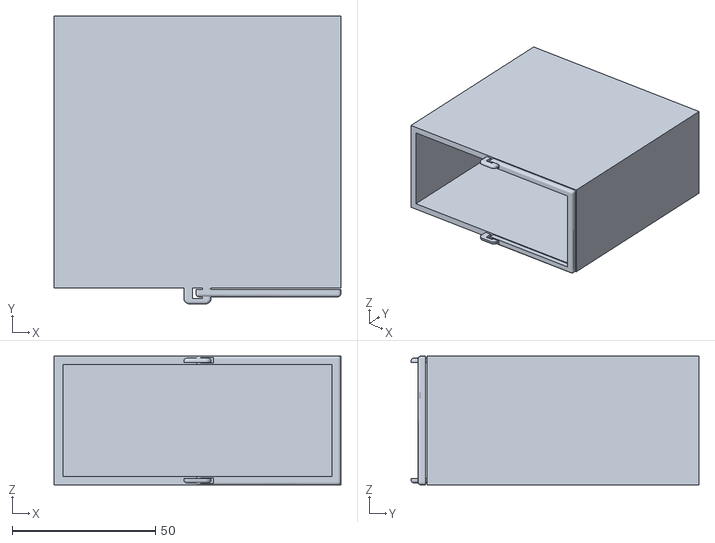
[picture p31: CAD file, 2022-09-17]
HW/stl_files/물통.stl
100.0 x 100.5 x 45.0

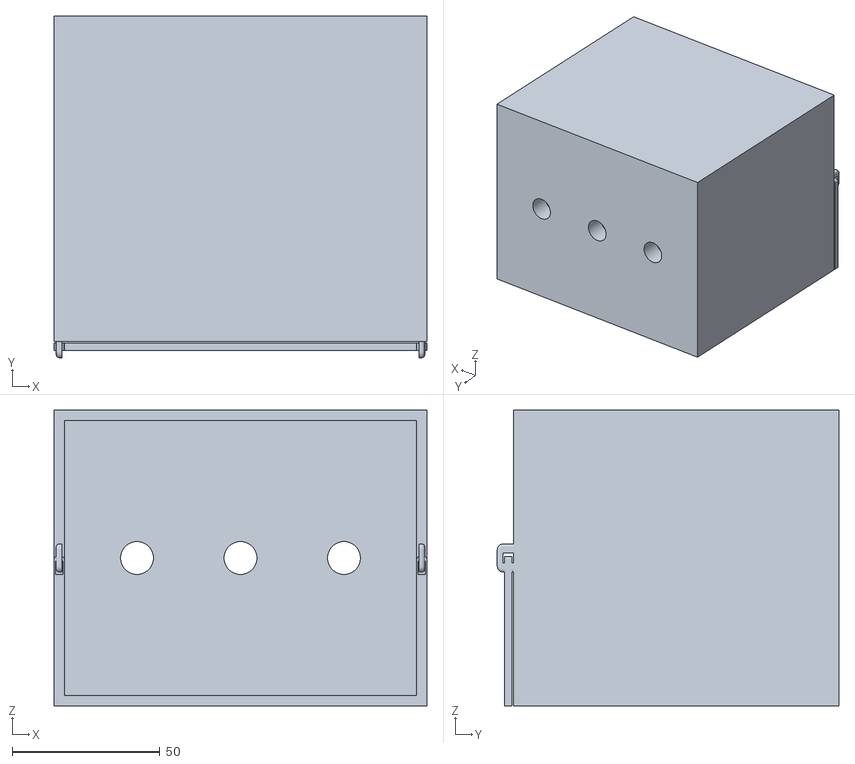
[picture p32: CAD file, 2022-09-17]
HW/stl_files/화분.stl
126.1 x 115.5 x 100.0

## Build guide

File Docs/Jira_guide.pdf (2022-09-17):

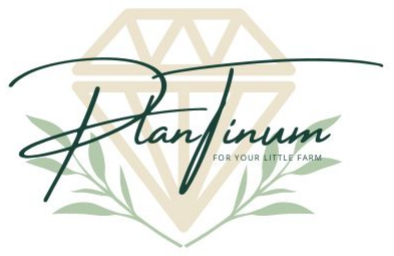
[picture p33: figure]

# Jira 사용법에 대해 알아봅시다

# 1. Epic 생성

## Epic

: 대분류

- HW / WEB / 기획 / DB / 배포 / TEST 등으로 나누어짐
- 자유롭게 생성 가능하나 되도록 팀원들과 상의 후 제작할 것
- Reporter는 자유 (혹은 팀장)

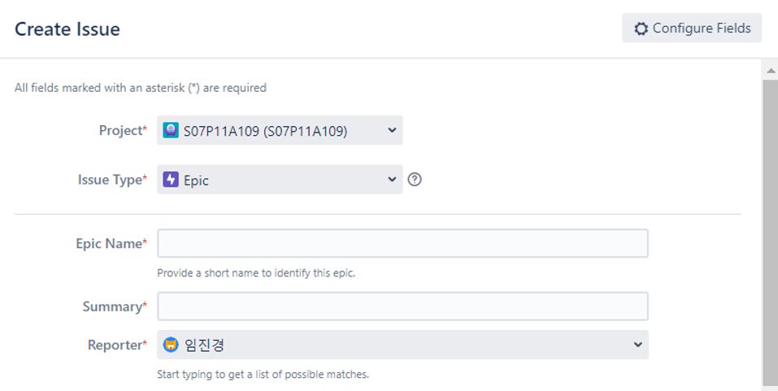
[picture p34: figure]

# 2. Story 생성

## Story

: 회원에게 제공되는 서비스/기능 목록

- 네이밍 규칙: 명사로 마무리
* 예) 물주기, 빛조절 / 회원가입, 로그인, 게시물 작성
- Story Point는 0
- Reporter, Assignee 무관
- 주제에 맞게 Epic Link와 팀 Sprint 설정

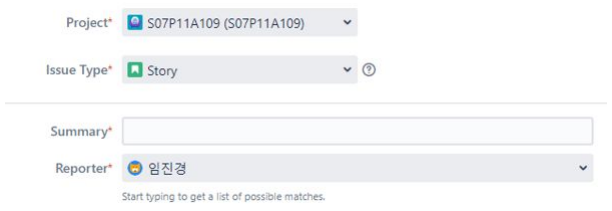
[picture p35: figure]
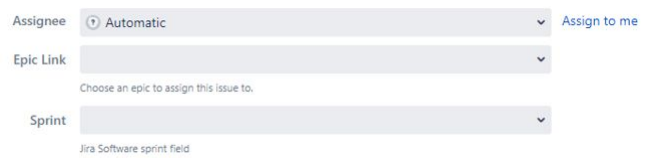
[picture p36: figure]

# 3. Task 생성

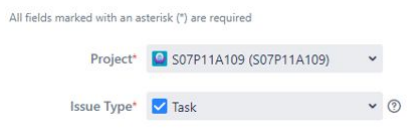
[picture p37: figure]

## Task

: 해당 스토리에 관련한 상세 구현 사항

- 팀 내에서 각 개발자에게 직접적으로 배정되는 업무 목록
- 네이밍 규칙
- 파트는 대괄호로 명시
- 명사로 마무리
- 예시: [BE] 유저 모델 작성
- Story Point는 4 이하, 모든 Task를 합하여 1주 40시간 배정
- Reporter, Assignee 본인 이름으로 설정
- 주제에 맞게 Epic Link와 Issue(Story), 팀 Sprint 설정
- Subtask는 사용하지 않는다.
- Task를 보다 세분화하여 설정

# 4. Sprint 시작

## Sprint

: Backlog에 Issue들을 모아 Sprint를 시작한다.

- 팀장이 Sprint 제작 후 각 팀원들이 Backlog에 Issue들을 올리면 Sprint를 시작한다.
- 할당된 Task Point의 총합은 Backlog 페이지 오른쪽 상단의 숫자로 확인 가능
- 검은색 : Not Started
- 파란색 : In Progress
- 초록색 : Done

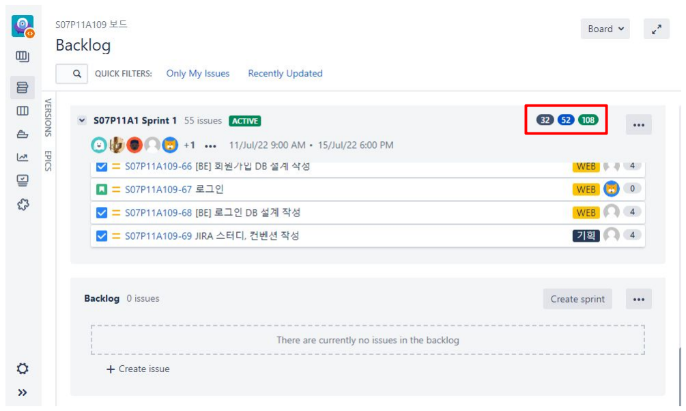
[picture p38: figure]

# 5. Task 관리

: 진행중인 Sprint는 Active Sprints에서 관리할 수 있다.

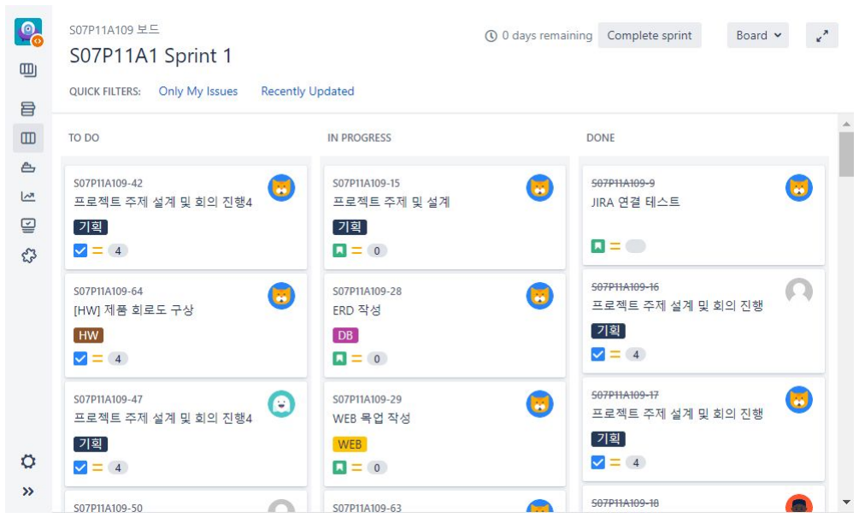
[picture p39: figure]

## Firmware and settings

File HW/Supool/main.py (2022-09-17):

from PySide2.QtWidgets import *
from PySide2.QtCore import *
from entryUI import Ui_Form as Ui_EntryUI
from mainUI import Ui_Form as Ui_MainUI
from detailUI import Ui_Form as Ui_DetailUI
from otpUI import Ui_Form as Ui_Otp
from sleepUI import Ui_Form as Ui_SleepUI

import mysql.connector
import json
from datetime import datetime
import time
import sys
import os,subprocess

import RPi.GPIO as GPIO
import spidev
import Adafruit_DHT


#variable
success_acc = 0
detail_back =0
otp_back = 0

userfilepath= "./user_setting.json"
screenfilepath = '/boot/cmdline.txt'
plant_id = -1
user_data=[]
#물임계점
hum_threshold = -1
#물통 양 디지털
water_amount = 0

#recnet_watering의 크기
watering_cnt=0
temp=28
humi=30
soil=54
#파도 움직임
waveLV = 120

#취침모드
issleep=0
isfirst=0

#페이지 생성 확인용
is_detail_page = 0
is_sleep_page = 0

#센서 정보
t=0
humSensor = Adafruit_DHT.DHT11
humSensor_pin = 23
waterLV_pin=24
hum_max=0
A1A = 5
A1B = 6

spi = spidev.SpiDev()
spi.open(0,0)
spi.max_speed_hz=500000


#watering_stop
watering_flag = 0
fromMaintoDetail =0


def sensor_init():
    GPIO.setwarnings(False)
    GPIO.setmode(GPIO.BCM)
    GPIO.setup(A1A, GPIO.OUT)
    GPIO.output(A1A, GPIO.LOW)
    GPIO.setup(A1B, GPIO.OUT)
    GPIO.output(A1B, GPIO.LOW)

	#WATERLEVEL Sensor GPIO Setting
    GPIO.setwarnings(False)
	
	#LED GPIO Setting
   

	#WaterLevel Sensor GPIO Setting
    GPIO.setup(waterLV_pin, GPIO.IN)


def read_spi_adc(adcChannel):
    global soil
    adcValue=0
    try:
        buff=spi.xfer2([1,(8+adcChannel)<<4,0])
        adcValue = ((buff[1]&3)<<8)+buff[2]
        soil = int(map(adcValue,hum_max,1023,0,100))
        soil = 100 - soil
    except:
        print("can\'t read spi_adc")
        return

# Mapping 0 to 100  with  Analog Sensor Value
def map(value, min_adc, max_adc, min_hum, max_hum):
	adc_range = max_adc-min_adc
	hum_range = max_hum - min_hum
	scale_factor = float(adc_range)/float(hum_range)
	return value/scale_factor

def humidTemp():
    global humi,temp
    humi,temp = Adafruit_DHT.read_retry(humSensor,humSensor_pin)
    humi = int(humi)
    temp = int(temp)


def check_waterlevel():
    global water_amount
    if water_amount != GPIO.input(waterLV_pin) : 
        water_amount = GPIO.input(waterLV_pin)
        user_data['water_amount'] = water_amount

        with open(userfilepath,"w",encoding = 'utf-8') as file:
            json.dump(user_data, file, indent = "\t",ensure_ascii=False)

#센서 측정 스레드_메인시작시 같이 시작
class sensorThread(QThread):
    global a,success_acc

    def __init__(self):
        super().__init__()
        sensor_init()

    def stop(self):
        GPIO.cleanup()
        spi.close()
        self.quit()
        self.wait(1000)

    def run(self):
        global temp,humi,waveLV,watering_flag
        t = 0
        self.send_datas=0

        screen(0)
        
        humidTemp()

        while(1):
            try:
                read_spi_adc(0)
                check_waterlevel()

                if(soil < hum_threshold):
                    GPIO.output(A1A, GPIO.HIGH)
                    GPIO.output(A1B, GPIO.LOW)
                    watering_flag = 1
                else:
                    GPIO.output(A1A, GPIO.LOW)
                    GPIO.output(A1B,GPIO.LOW)
                    if(watering_flag == 1):
                        watering()
                        watering_flag = 0
                
                t += 1
                #every 10sec
                if(t >= 100):
                    humidTemp()
                        #if 9oclock
                    self.nowtime = datetime.now().strftime("%H:%M")

                    if(self.nowtime == "09:00"):
                        if(self.send_datas == 0):
                            self.send_data()
                    elif(self.send_datas == 1):
                        self.send_datas = 0
                        
                            
                    t = 0
                #every 1sec
                if(t%10 == 0):
                    waveLV = ((100-soil)*7) + 120

                time.sleep(0.1)

            except:
                GPIO.cleanup()
                spi.close()
                break


    def send_data(self):
        try:
            self.cur = db.cursor()
            self.sql_str = "update plants_sensing set remaining_water = " +water_amount+ ", state_led= " + (1-issleep) +", moisture_level = " + soil +" where id=" + str(user_data['id']) 
            self.cur.execute(self.sql_str)
            self.cur.close()
            db.commit()
        except:
            db.reconnect()

#물줄때
def watering():
    global watering_cnt,user_data
    w_now_time = datetime.now().strftime("%y.%m.%d %H:%M")
    user_data['recent_watering'].append(w_now_time)
    watering_cnt += 1
    if(watering_cnt > 3):
        del(user_data['recent_watering'][0])
        watering_cnt = 3

    with open(userfilepath, "w", encoding='utf-8') as file:
        json.dump(user_data, file, indent="\t",ensure_ascii=False)
    
    #db update
    try:
        wcur=db.cursor()
        wsql_str = "update plants_sensing set last_watering = \"" + w_now_time + "\"  where id=" + str(user_data['id']) 
        wcur.execute(wsql_str)
        wcur.close()
        db.commit()
    except Exception as e:
        print("db update is impossible")


#Change sreensaver

def screen(screen_mode):
    #sleep_mode : 10sec
    if(screen_mode == 1):
        
        subprocess.run("sudo python3 ./led_off.py",shell=True)
        subprocess.run('xset s on',shell = True)
        subprocess.run('xset s 10',shell = True)
    else:
        #GPIO.output(LED1, GPIO.HIGH)
        #GPIO.output(LED2, GPIO.HIGH)
        subprocess.run("sudo python3 ./led_on.py",shell=True)
        subprocess.run('xset s off',shell=True)


#시작 페이지 
class EntryPage(QDialog, QWidget, Ui_EntryUI):
    def __init__(self):
        super().__init__()
        self.setWindowFlag(Qt.FramelessWindowHint)
        self.setupUi(self)
        self.dbset()

    def dbset(self):
        #db커넥트
        global db
        db = mysql.connector.connect(host="db_server",user='username', password='pw', database='db_name',buffered=True)

    def main(self):
        pass

    #새식물 등록
    def new_plant(self):

        widget.setCurrentIndex(1)

    def old_plant(self):
        global success_acc
        global plant_id,nickname,water_amount,hum_threshold
        global user_data,watering_cnt
        

        if(user_data['id'] == -1):
            msgBox = QMessageBox()
            msgBox.setText("There is no information\nPlease push NEW button")
            msgBox.exec()
        #쿼리요청
        self.cur = db.cursor()
        self.sql_str = "select is_connected from plants_myplant where id=" + str(user_data['id'])
        self.cur.execute(self.sql_str)
        

        for result in self.cur:
            # connect success 바로 메인페이지로 이동
            if(result[0] == 1):
                #connect == 1 이면 연결유지 상태 메인페이지 이동
                hum_threshold=user_data['hum_threshold']
                watering_cnt = len(user_data['recent_watering'])
                success_acc = 1
                widget.addWidget(MainPage())
                widget.setCurrentIndex(2)
            else:
                #연결이 끊기면 오류메세지
                msgBox = QMessageBox()
                msgBox.setText("There are no connected plants")
                msgBox.exec()
                #연결이 끊겨있으므로 user_data정보 지워줌

                user_data['id'] = -1
                user_data['nickname'] = ""
                user_data['hum_threshold'] = -1
                user_data['recent_watering']= []
                user_data['water_amount'] = 0
                # 수정반영
                with open(userfilepath, "w", encoding='utf-8') as file:
                    json.dump(user_data, file, indent="\t", ensure_ascii=False)

            #print(result[0])

        #다시 누를 것 대비_변경반영

        self.cur.close()
        db.commit()
#메인 페이지 _ 파도 화면
class MainPage(QDialog, QWidget, Ui_MainUI):
    def __init__(self):
        super().__init__()
        self.setupUi(self)
        self.now = datetime.now().strftime('%H : %M')
        self.clock.setText(self.now)
        #온습도 글씨
        humidTemp()
        self.humi_label.setText(str(humi)+"%")
        self.temp_label.setText(str(temp)+"ºC")

        #시계를 위해 5초에 한번 화면 새로고침

        self.main()

    def main(self):
        global snsth, clock_timer
        self.warn_label.hide()

        self.now = datetime.now().strftime('%H : %M')
        self.clock.setText(self.now)
        #시계 타이머
        clock_timer = QTimer(self)
        clock_timer.setInterval(5000)  # 1초 => 나중에 5초에 한번으로 바꿀거임
        clock_timer.timeout.connect(self.show_clock)
        clock_timer.start()

        #센서 스레드
        snsth = sensorThread()
        snsth.start()

    def go_detailPage(self):
        global detail_back,is_detail_page
        #화면 새로고침 필요없음
        clock_timer.stop()
        #디테일페이지 선언 및 화면 전환
        if (is_detail_page == 0):
            is_detail_page = 1
            widget.addWidget(DetailPage())
            widget.addWidget(SleepPage())
        widget.setCurrentIndex(3)
        # 뒤로가기 버튼으로 돌아왔을때

    #화면 새로고침
    def show_clock(self):
        global now_time
        #시간 00:00 형태
        self.now = datetime.now().strftime('%H : %M')
        self.clock.setText(self.now)
        #온습도 글씨
        #humidTemp()
        self.humi_label.setText(str(humi)+"%")
        self.temp_label.setText(str(temp)+"ºC")

        #파도 조절
        self.wave.setGeometry(QRect(0, waveLV , 1366, 768))
        #print(now_time)

        if(water_amount == 0):
            self.warn_label.show()
        else:
            self.warn_label.hide()



class DetailPage(QDialog, QWidget, Ui_DetailUI):
    def __init__(self):
        super().__init__()
        self.setupUi(self)
        #최근 관수날짜 보드
        #초기화 후 채워넣음
        self.watering_board = [self.label_8, self.label_9, self.label_10]
        self.label_8.clear()
        self.label_9.clear()
        self.label_10.clear()
        self.label_11.setText(user_data['nickname'])
        self.label_4.setText(str(temp)+"ºC")
        self.label_5.setText(str(humi)+"%")
        self.label_6.setText(str(soil)+"%")

        #화면 새로고침 한번 하고 시작
        self.main()

    def main(self):
        #관수정보
        for i in range(len(user_data['recent_watering'])):
            self.watering_board[i].setText(user_data['recent_watering'][len(user_data['recent_watering'])-i-1])


        #물의 양
        if(water_amount == 1):
            self.progressBar.setStyleSheet(
                "QProgressBar::chunk { background-color : rgb(101, 128, 93) ; border-radius : 10px;} QProgressBar {background-color : rgb(255,255,255);border-radius : 15px;}")
            self.progressBar.setValue(80)
        else:
            self.progressBar.setStyleSheet(
                "QProgressBar::chunk { background-color : rgb(163, 77, 79) ; border-radius : 10px;} QProgressBar {background-color : rgb(255,255,255);border-radius : 15px;}")
            self.progressBar.setValue(40)


       
    #메인페이지로 돌아감
    def go_mainpage(self):
       
        global clock_timer
        clock_timer.start()
        widget.setCurrentIndex(2)
    #취침모드
    def sleep_mode(self):
        global issleep,is_sleep_page

        issleep = 1
       
        #취침모드에서 벗어나면 바로 메인페이지로 돌아감

        
        screen(1)
        widget.setCurrentIndex(4)

    



    #새로고침
    def redo(self):
        #관수정보
        for i in range(len(user_data['recent_watering'])):
            self.watering_board[i].setText(user_data['recent_watering'][len(user_data['recent_watering'])-i-1])

        #닉네임
        try:
            self.cur = db.cursor()
            self.sql_str = "select nickname from plants_myplant where id=" + str(user_data['id'])
            self.cur.execute(self.sql_str)

            for (res) in self.cur:
            #print(res)
            #닉네임 변경시
                if(res[0] != user_data['nickname']):
                    self.label_11.setText(res[0])
                    user_data['nickname'] = res[0]
                    with open(userfilepath, "w", encoding='utf-8') as file:
                        json.dump(user_data, file, indent="\t", ensure_ascii=False)

            self.cur.close()
            db.commit()
        except Exception as e:
            print(e)
            db.reconnect()
            

        #물의 양
        if(water_amount == 1):
            self.progressBar.setStyleSheet(
                "QProgressBar::chunk { background-color : rgb(101, 128, 93) ; border-radius : 10px;} QProgressBar {background-color : rgb(255,255,255);border-radius : 15px;}")
            self.progressBar.setValue(80)
        else:
            self.progressBar.setStyleSheet(
                "QProgressBar::chunk { background-color : rgb(163, 77, 79) ; border-radius : 10px;} QProgressBar {background-color : rgb(255,255,255);border-radius : 15px;}")
            self.progressBar.setValue(40)


        #humi,temp,soil
        self.label_5.setText(str(humi)+"%")
        self.label_4.setText(str(temp)+"ºC")
        self.label_6.setText(str(soil)+"%")

    #프로그램 및 라즈베리파이 종료
    #코드 해제를 위함
    def turnoff(self):
        global clock_timer, snsth
        clock_timer.stop()
        snsth.stop()
        GPIO.cleanup()
        spi.close()
        subprocess.run("sudo python3 ./led_off.py",shell=True)
        quit()
        #라즈베리파이 종료 
        sys.exit(0)


#otp코드
class OtpPage(QDialog, QWidget, Ui_Otp):
    def __init__(self):
        super().__init__()
        self.setupUi(self)
        self.otp_code = ""
        self.number_label = [self.number_1, self.number_2, self.number_3, self.number_4, self.number_5, self.number_6]
        for i in range(6):
            self.number_label[i].clear()


    def check_otp(self):
        global success_acc,isfirst
        global plant_id, water_amount, hum_threshold
        self.flag=0

        #otp코드가 6자리일때
        if(len(self.otp_code) == 6):
            #self.flag = 1
            self.cur = db.cursor()

            # is otp exist?
            self.sql_str = "select A.id, A.nickname, A.otp_code, A.is_connected, B.watercycle_spring from plants_myplant A join plants_plants B on A.plant_info_id = B.id where otp_code = " + self.otp_code
            self.cur.execute(self.sql_str)
            # result = 1개
            if(self.cur.rowcount ==1):
                #id, 닉네임, 물의 양 등 저장
                for(id,name,otp,isconnect,hum_t) in self.cur:
                    #Already connect
                    #이미 연결이 되어있는 식물의 경우
                    if(isconnect == 1):
                        self.flag = 2
                        break;
                    #가져온 id(pk),name 저장
                    self.plant_id = int(id)
                    self.name = str(name)
                    self.hum_threshold = hum_t

                # Success connect!
                if(self.flag != 2):
                    self.flag = 1

                    # make otp=NULL, isconnect = 1
                    self.sql_str = "update plants_myplant set otp_code=NULL, is_connected=1 where id="+str(self.plant_id)
                    self.cur.execute(self.sql_str)

                    #json 수정

                    user_data['id'] = self.plant_id
                    user_data['nickname'] = self.name
                    user_data['recent_watering'] = []
                    user_data['water_amount']=0
                    #humuduty 정리
                    if(self.hum_threshold == "053001"):
                        hum_threshold = 80
                    elif(self.hum_threshold == "053002"):
                        hum_threshold = 60
                    elif(self.hum_threshold == "053003"):
                        hum_threshold = 40
                    elif(self.hum_threshold == "053004"):
                        hum_threshold = 20
                    else:
                        hum_threshold = 0

                    user_data['hum_threshold']=hum_threshold
                    #수정반영
                    with open(userfilepath, "w", encoding='utf-8') as file:
                        json.dump(user_data, file, indent="\t",ensure_ascii=False)

                    plant_id = self.plant_id
                    water_amount = 0
        
                    db.commit()
            else:
                self.flag = 0

        #성공했을때_db에 정보존재
        if(self.flag == 1):
            success_acc = 1
            widget.addWidget(MainPage())
            isfirst = 1
            widget.setCurrentIndex(2)
        else:
            #실패했을때
            msgBox = QMessageBox()
            if(self.flag == 2):
                msgBox.setText("Already connected")
            else:
                msgBox.setText("Wrong OTP")
            msgBox.exec()

            #실패시 otp코드 초기화
            success_acc = 0
            for i in range(6):
                self.number_label[i].clear()
            self.otp_code = ""



    def back_entry(self):
        #global otp_back
        #메인으로 다시 돌아감
        #otp_back = 1
        #self.close()
        widget.setCurrentIndex(0)

    #숫자보드 입력
    def click_pad(self):
        self.send = self.sender().text()


        if( self.send == "<"):
            if(len(self.otp_code) != 0):
                self.number_label[len(self.otp_code) - 1].clear()
                self.otp_code = self.otp_code[:-1]

        else:
            if(len(self.otp_code) < 6):
                self.otp_code += self.send
                self.number_label[len(self.otp_code)-1].setText(self.send)


#취침 화면
class SleepPage(QDialog, QWidget, Ui_SleepUI):
    def __init__(self):
        super().__init__()
        self.setupUi(self)
        #self.show()
        #self.main()

    def main(self):
       #self.testlabel.setText(str(a))
       #ScreenSaver
       pass

    #화면 터치시 취침모드 종료 후 파도화면으로 돌아감
    def wakeup(self):
        global issleep
        #self.close()
        clock_timer.start()
        screen(0)
        issleep = 1
        widget.setCurrentIndex(2)


app=QApplication()
main = EntryPage()

widget = QStackedWidget()
widget.addWidget(main)
widget.addWidget(OtpPage())
#widget.setFixedHeight(768)
#widget.setFixedWidth(1366)
widget.setGeometry(0,0,1366,768)

#프로그램 실행 전 user_data 불러옴

#한글 읽기 위하여 encoding 표시
with open(userfilepath, "r", encoding="utf-8") as file:
    user_data = json.load(file)


widget.show()
app.exec_()

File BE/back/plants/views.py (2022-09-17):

from django.shortcuts import get_object_or_404, get_list_or_404
from django.contrib.auth import get_user_model
from rest_framework.decorators import api_view, authentication_classes, permission_classes
from rest_framework.response import Response
from .serializers import MyplantSerializer, PlantsSerializer, PlantsSearchSerializer, DiarySerializer, MyplantListSerializer
from .models import Myplant, Plants, Diary
from rest_framework.authentication import TokenAuthentication
from rest_framework.permissions import IsAuthenticated
from rest_framework import status
from django.core.cache import cache


User = get_user_model()


# 전체 식물 조회 => 제공하지 않는 기능, 개발 확인용
@api_view(['GET'])
def plants(request):
    plants = get_list_or_404(Plants)
    serializer = PlantsSerializer(plants, many=True)
    return Response(serializer.data)    


# 내 식물 전체 조회 
@api_view(['GET'])
@authentication_classes([TokenAuthentication])
@permission_classes([IsAuthenticated])
def read_myplant(request, username):
    user = get_object_or_404(User, username=username)
    
    plants = Myplant.objects.filter(user=user).order_by('-pk')

    serializer = MyplantListSerializer(plants, many=True)
    return Response(serializer.data)
    

# 식물 이름 검색
@api_view(['GET'])
@authentication_classes([TokenAuthentication])
@permission_classes([IsAuthenticated])
def search(request, plantname):
    plants = Plants.objects.filter(name__contains=plantname)
    serializer = PlantsSearchSerializer(plants, many=True)
    return Response(serializer.data)


# 등록용 식물 검색
@api_view(['GET'])
@authentication_classes([TokenAuthentication])
@permission_classes([IsAuthenticated])
def search_all(request):
    plants = Plants.objects.all()
    serializer = PlantsSearchSerializer(plants, many=True)
    return Response(serializer.data)


from threading import Timer
import random


# 물주기(내 식물) 등록 (등록 전 식물 검색 필요)
@api_view(['POST'])
@authentication_classes([TokenAuthentication])
@permission_classes([IsAuthenticated])
def create_myplant(request):
    
    user = request.user

    serializer = MyplantSerializer(data=request.data)
    if serializer.is_valid(raise_exception=True):
        plantname = request.data['plantname']

        if Plants.objects.exclude(name='직접 입력하기').filter(name=plantname).exists():
            plant_info = Plants.objects.get(name=plantname)

            serializer.save(user=user, plant_info=plant_info)
        else:
            plant_info = Plants.objects.get(name='직접 입력하기')

            serializer.save(user=user, plant_info=plant_info)

        

        return Response(serializer.data, status=status.HTTP_201_CREATED)


# 연결되지 않은 상태, otp도 없는 상태에서 otp 발급
# 1분이 지나면 otp 삭제
@api_view(['GET'])
@authentication_classes([TokenAuthentication])
@permission_classes([IsAuthenticated])
def create_otp(request, myplant_pk):

    if Myplant.objects.filter(pk=myplant_pk).exists():
        myplant = Myplant.objects.filter(pk=myplant_pk)

        me = request.user.id
        user = myplant.values('user_id')[0]['user_id']
        
        if me == user:  # OTP 요청자와 식물 등록자가 같으면
            if cache.get(f'{me}_{myplant_pk}') == None and myplant.values('is_connected')[0]['is_connected'] == False:  # 해당 식물의 OTP 코드가 발급되지 않았고 연결된 상태가 아니라면

                otp_code = ''

                while otp_code == '':

                    otp_code = random.randint(0, 999999)
                    otp_code = str(otp_code).zfill(6)

                    if Myplant.objects.filter(otp_code=otp_code).exists():  # db 존재 여부 확인
                        otp_code = ''  # 이미 존재하면 재발급

                myplant.update(otp_code=otp_code)

                def set_otp_redis():
                    cache.set(f'{me}_{myplant_pk}', otp_code, timeout=60)  # 지속시간 60초
                set_otp_redis()

                otp_redis = cache.get(f'{me}_{myplant_pk}')

                def delete_otp():
                    myplant.update(otp_code=None)
                Timer(60, delete_otp).start()  # 60초뒤 삭제 함수 실행

                return Response({'otp_code': otp_redis})
            

            elif cache.get(f'{me}_{myplant_pk}') and myplant.values('is_connected')[0]['is_connected'] == False:  # 연결되지 않은 상태로 otp 존재
                otp_redis = cache.get(f'{me}_{myplant_pk}')
                return Response({'otp_code': otp_redis})

            elif myplant.values('is_connected')[0]['is_connected'] == True:  # 해당 식물이 연결된 상태라면
                
                return Response({'detail': '이미 연결되었습니다.'}, status=status.HTTP_400_BAD_REQUEST)

        else:  # OTP 요청자와 식물 등록자가 다르면
            return Response({'detail': '잘못된 접근입니다.'}, status=status.HTTP_403_FORBIDDEN)
    else:  # 존재하지 않는 식물pk
        return Response({'detail': '찾을 수 없습니다.'}, status=status.HTTP_404_NOT_FOUND)


# otp코드 조회
@api_view(['GET'])
@authentication_classes([TokenAuthentication])
@permission_classes([IsAuthenticated])
def otp_status(request, myplant_pk):
    myplant = get_object_or_404(Myplant, pk=myplant_pk)
    me = request.user.id
    user = myplant.user_id
    
    if me == user:
        is_connected = myplant.is_connected
        if is_connected == True:
            otp_redis = None

        else:
            otp_redis = cache.get(f'{me}_{myplant_pk}')
        print(otp_redis)
        return Response({'otp_code': otp_redis})

    else:
        return Response({'detail': '잘못된 접근입니다.'}, status=status.HTTP_403_FORBIDDEN)


# otp 삭제
@api_view(['GET'])
@authentication_classes([TokenAuthentication])
@permission_classes([IsAuthenticated])
def otp_remove(request, myplant_pk):
    myplant = get_object_or_404(Myplant, pk=myplant_pk)
    me = request.user.id
    user = myplant.user_id

    if me == user:
        otp_redis = cache.get(f'{me}_{myplant_pk}')
        if otp_redis:
            cache.delete(f'{me}_{myplant_pk}')
        
            return Response({'otp_code': None})

    else:
        return Response({'detail': '잘못된 접근입니다.'}, status=status.HTTP_403_FORBIDDEN)


# 연결끊기
@api_view(['GET'])
@authentication_classes([TokenAuthentication])
@permission_classes([IsAuthenticated])
def disconnect(request, myplant_pk):
    if Myplant.objects.filter(pk=myplant_pk).exists():
        myplant = Myplant.objects.filter(pk=myplant_pk)

        me = request.user.id
        user = myplant.values('user_id')[0]['user_id']

        if me == user:  # 연결끊기 요청자와 식물 등록자가 같으면
            if myplant.values('is_connected')[0]['is_connected'] == True:
                myplant.update(is_connected=False)
                return Response({'is_connected': False})

            else:
                return Response({'detail': '연결상태를 확인해주세요.'}, status=status.HTTP_400_BAD_REQUEST)
        else:
            return Response({'detail': '잘못된 접근입니다.'}, status=status.HTTP_403_FORBIDDEN)
    else:
        return Response({'detail': '찾을 수 없습니다.'}, status=status.HTTP_404_NOT_FOUND)
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
